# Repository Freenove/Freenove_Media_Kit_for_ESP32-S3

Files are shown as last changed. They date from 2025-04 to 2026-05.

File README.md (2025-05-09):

## Freenove_Media_Kit_for_ESP32-S3

A kit with a Freenove® ESP32-S3 Board for learning programming and electronics.

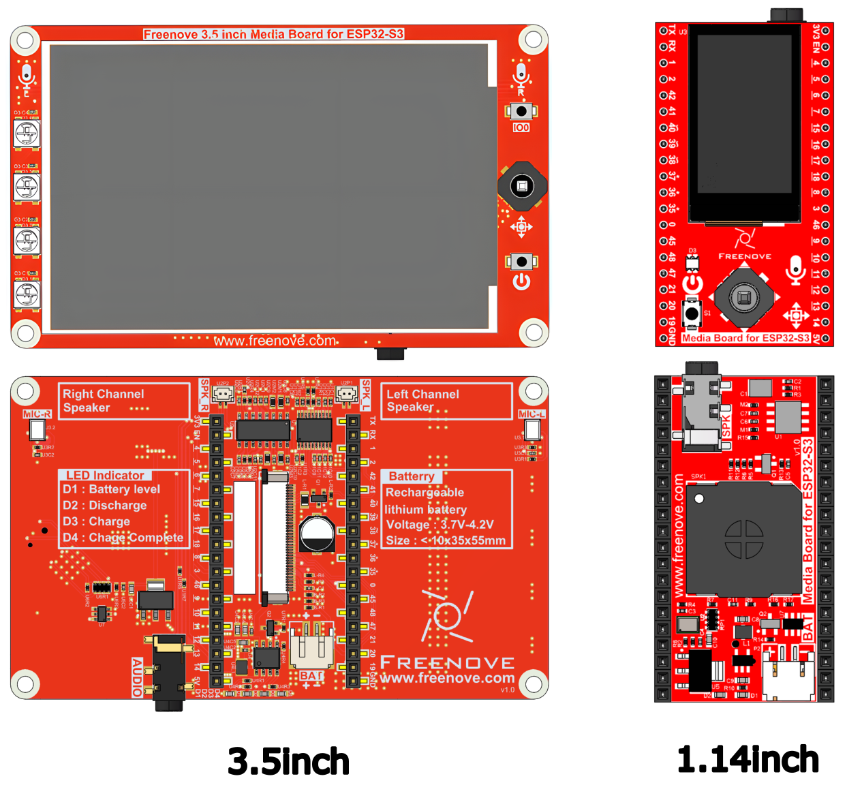
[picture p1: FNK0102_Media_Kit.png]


ESP32-S3 chip is manufactured by Espressif®.
>Espressif® is a trademark of Espressif Systems (Shanghai) Co.Ltd (https://www.espressif.com/).

Freenove ESP32-S3 Board can be uploaded code using Arduino® IDE.
> Arduino® is a trademark of Arduino LLC (https://www.arduino.cc/).

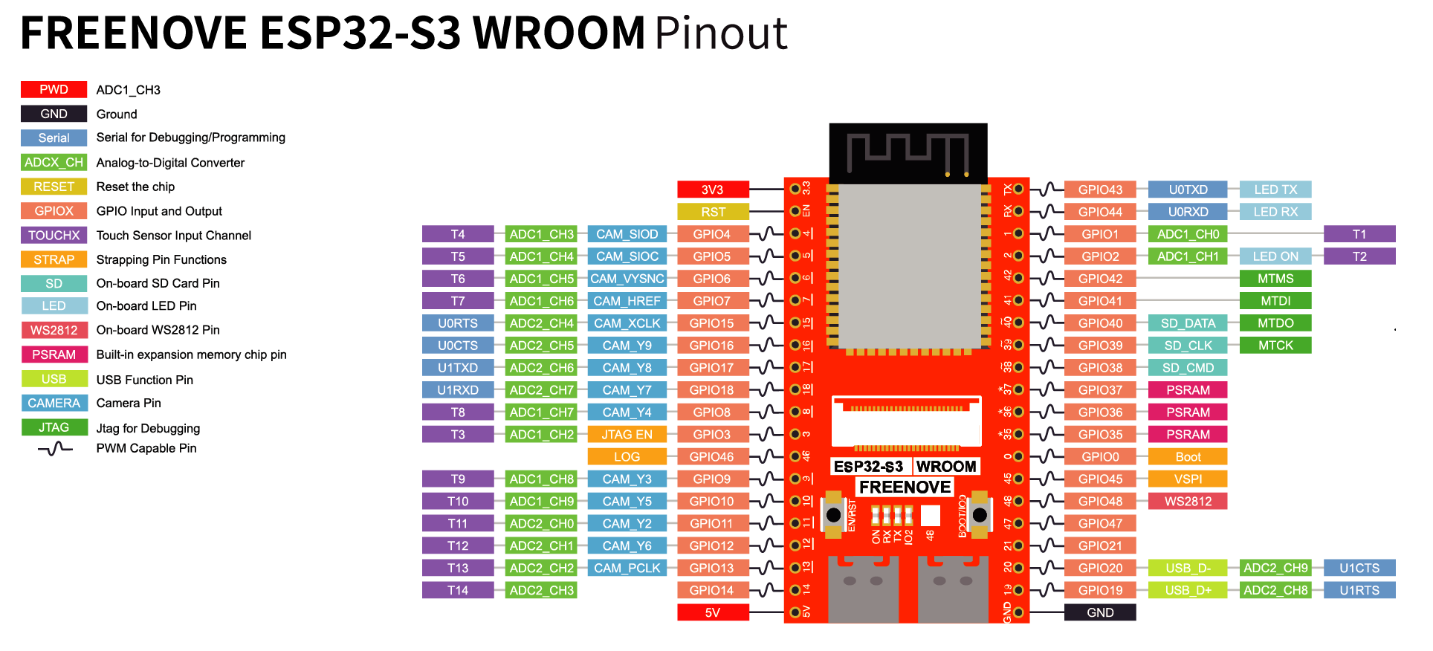
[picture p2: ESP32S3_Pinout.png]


### Download

* **Use command in console**

	Run following command to download all the files in this repository.

	`git clone https://github.com/Freenove/Freenove_Media_Kit_for_ESP32-S3.git`

* **Manually download in browser**

	Click the green "Clone or download" button, then click "Download ZIP" button in the pop-up window.
	Do NOT click the "Open in Desktop" button, it will lead you to install Github software.

> If you meet any difficulties, please contact our support team for help.

### Use

1. Download the ZIP file as above.
2. Unzip it and you will get a folder contains tutorials and related files.
3. If you are interested in the source code of OpenAI or Xiaozhi AI, you can visit the Urls:

	Open AI: [https://github.com/Freenove/openai-realtime-embedded](https://github.com/Freenove/openai-realtime-embedded)
	
	Xiaozhi Ai: [https://github.com/Freenove/xiaozhi-esp32](https://github.com/Freenove/xiaozhi-esp32)
	
	Xiaozhi Ai Server: [https://github.com/Freenove/xiaozhi-esp32-server](https://github.com/Freenove/xiaozhi-esp32-server)

### Support

Freenove provides free and quick customer support. Including but not limited to:

* Quality problems of products
* Problems of products when used
* Questions of learning and creation
* Opinions and suggestions
* Ideas and thoughts

Please send an email to:

[support@freenove.com](mailto:support@freenove.com)

We will reply within one working day.

### Purchase

Please visit the following page to purchase our products:

http://freenove.com/store

Business customers please contact us through the following email address:

[sale@freenove.com](mailto:sale@freenove.com)

### About

Freenove provides open source electronic products and services.

Freenove is committed to helping customers learn programming and electronic knowledge, quickly implement product prototypes, realize their creativity and launch innovative products. Our services include:

* Kits for learning programming and electronics
* Kits compatible with Arduino®, Raspberry Pi®, micro:bit®, etc.
* Kits for robots, smart cars, drones, etc.
* Components, modules and tools
* Design and customization

To learn more about us or get our latest information, please visit our website:

http://www.freenove.com

### Copyright

All the files in this repository are released under [Creative Commons Attribution-NonCommercial-ShareAlike 3.0 Unported License](http://creativecommons.org/licenses/by-nc-sa/3.0/).
You can find a copy of the license in this repository.



> It means you can use these files on your own derived works, in part or completely. But not for commercial use.

Freenove® brand and logo are trademarks of Freenove Creative Technology Co., Ltd. Must not be used without permission.

Other registered trademarks and their owners appearing in this repository:

Arduino® is a trademark of Arduino LLC (https://www.arduino.cc/).  
Raspberry Pi® is a trademark of Raspberry Pi Foundation (https://www.raspberrypi.org/).  
micro:bit® is a trademark of Micro:bit Educational Foundation (https://www.microbit.org/).  
Espressif® is a trademark of Espressif Systems (Shanghai) Co.Ltd (https://www.espressif.com/).

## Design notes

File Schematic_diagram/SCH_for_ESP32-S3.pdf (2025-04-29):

CSI_Y1 CSI_Y³ | CSI_Y²
IO0 | 27 IO35 | 28 IO36 | 29 IO37 | 30 IO38 | 31 IO39 | 32 IO40 | 33 IO41 | 34 IO42 | 35 RXD0/IO44 | 36 TXD0/IO43 | 37 IO2 | 38 IO1 | 39 GND | 40 PGND | 41

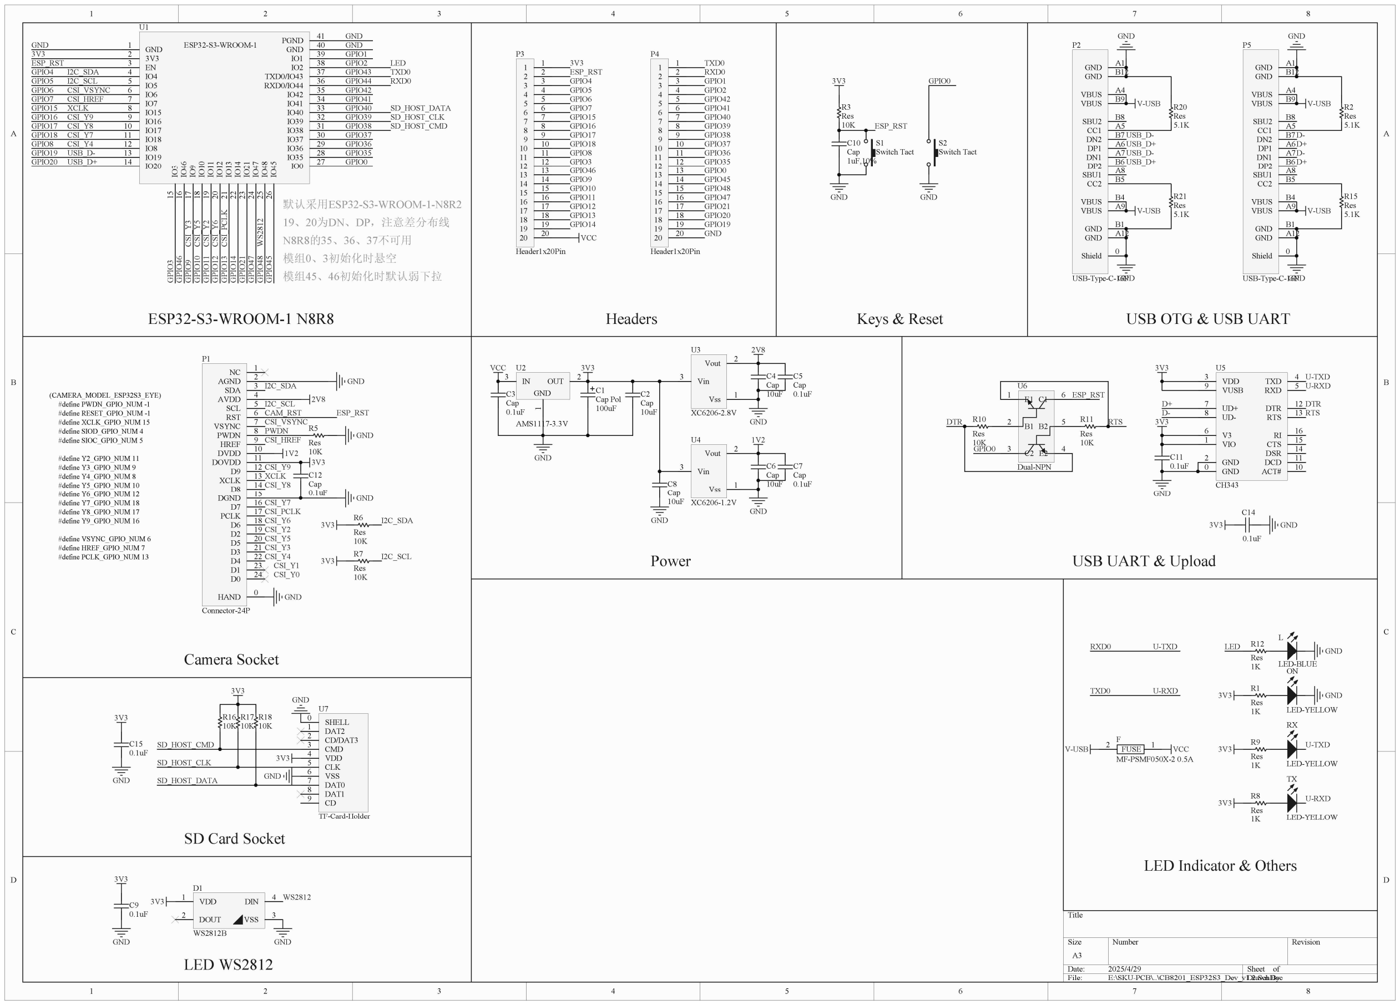
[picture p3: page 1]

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
Title

Size | Number | Revision
A3
Date: | 2025/4/29 | Sheet of
File: | E:\SKU-PCB\..\CB8201_ESP32S3_Dev_v1.2.SchDoc Drawn By:
NC | 1
AGND | 2
SDA | 3
AVDD | 4
SCL | 5
RST | 6
VSYNC | 7
PWDN | 8
HREF | 9
DVDD | 10
DOVDD | 11
D9 | 12
XCLK | 13
D8 | 14
DGND | 15
D7 | 16
PCLK | 17
D6 | 18
D2 | 19
D5 | 20
D3 | 21
D4 | 22
D1 | 23
D0 | 24
HAND | 0

P1

Connector-24P

1K

R1
Res

ON

LED-YELLOW

3V3 | GND

GND

2V8
CAM_RST
CSI_VSYNC
PWDN
CSI_HREF

CSI_Y9
XCLK
CSI_Y8

CSI_Y7

CSI_Y6
CSI_Y2

CSI_Y3
CSI_Y4

CSI_Y5

CSI_PCLK

1V2
3V3

GND

GND

IN 3 | OUT | 2 1
GND

U2

AMS1117-3.3V

VCC

Vss | 1
Vout | 2

Vin 3

U3

XC6206-2.8V

Vss | 1
Vout | 2

Vin 3

U4

XC6206-1.2V

1V2

2V8

GND

GND

100uF

C1
Cap Pol

3V3

10uF

C2
Cap

GND

0.1uF

C3
Cap

10uF

C4
Cap
0.1uF

C5
Cap

10uF

C6
Cap
0.1uF

C7
Cap

10uF

C8
Cap

GND

10K

R3
Res

1uF,10%

C10
Cap

3V3

GND

ESP_RST

ESP_RST

CSI_Y4 | CSI_Y⁵ | CSI_Y⁶

CSI_Y7

CSI_Y0

CSI_VSYNC

CSI_Y9
CSI_Y8

XCLK

CSI_HREF | CSI_PCLK

GND
10K

R5
Res

0.1uF

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
3V3 | I2C_SDA

I2C_SCL

TX

LED-YELLOW

RX

LED-YELLOW

DTR

1K

R8
Res

1K

R9
Res

C1 6

B1 2

E1 1

C2 3

B2 | 5
E2 | 4

U6

Dual-NPN

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
ESP_RST

GPIO0

GND

V-USB

0.1uF

C14

0.1uF

C15

GND

S1
Switch Tact

S2
Switch Tact

GPIO0

GND

1K

R12
Res

L

LED-BLUE

GND LED

3V3

3V3

TXD0

RXD0

U-TXD
U-RXD
FUSE 2 | 1

F

MF-PSMF050X-2 0.5A

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
10 10
11 11
12 12
13 13
14 14
15 15
16 16
17 17
18 18
19 19
20 20

P3

Header1x20Pin

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
10 10
11 11
12 12
13 13
14 14
15 15
16 16
17 17
18 18
19 19
20 20

P4

Header1x20Pin

VCC

D+

D+

D-

D-

D-

D+

V-USB

GND

5.1K

R2
Res

5.1K

R15
Res

GND

V-USB

GND 1
3V3 2
EN 3
IO4 4
IO5 5
IO6 6
IO7 7
IO15 8
IO16 9
IO17 10
IO18 11
IO8 12
IO19 13
IO20 14 | IO³ 15 IO⁴⁶ 16 IO⁹ 17 IO¹⁰ 18 IO¹¹ 19 IO¹² 20 IO¹³ 21 IO¹⁴ 22 IO²¹ 23 IO⁴⁷ 24 IO⁴⁸ 25 IO⁴⁵ 26

U1

GND | ESP32-S3-WROOM-1
3V3

GPIO0

GPIO1
GPIO2 GPIO¹³ GPIO¹⁴

GPIO19
GPIO20 | GPIO²¹

GPIO35

GPIO36

GPIO37

GPIO38

GPIO39

GPIO40

GPIO41

GPIO42

GPIO43
GPIO44 GPIO⁴⁶ | GPIO⁴⁷ GPIO⁴⁸ GPIO⁴⁵

GND
GND

GPIO4
GPIO5
GPIO6
GPIO7
GPIO8 | GPIO³ | GPIO⁹ GPIO¹⁰ GPIO¹¹ GPIO¹²

GPIO15
GPIO16
GPIO17
GPIO18

GPIO4
GPIO5
GPIO6
GPIO7

GPIO8

GPIO15
GPIO16
GPIO17
GPIO18

ESP_RST

3V3

GPIO13
GPIO14

GPIO46
GPIO9
GPIO10
GPIO11
GPIO12

GPIO3

VCC

GPIO0

GPIO1
GPIO2

GPIO35

GPIO36

GPIO37

GPIO38

GPIO39

GPIO40

GPIO41

GPIO42

GND

GPIO19

GPIO20

GPIO21

GPIO45

GPIO47

GPIO48

I2C_SDA

I2C_SCL

I2C_SDA
I2C_SCL

VIO 1

GND 2

VDD 3 | TXD | 4
| RXD | 5

V3 6

UD+ 7
UD- 8

VUSB 9

ACT# | 10 DCD | 11
DTR | | | 12
RTS | | | 13
DSR | 14 CTS | 15 RI | 16

GND 0

U5

CH343

GND | A1
GND | B12
VBUS | A4
VBUS | B9
SBU2 | B8
CC1 | A5
DN2 | B7
VBUS | B4
CC2 | B5
DP2 | B6
GND | B1
DP1 | A6
DN1 | A7
SBU1 | A8
VBUS | A9
GND | A12
Shield | 0

P5

USB-Type-C-16P

10K

R16
10K

R17
10K

R18

SD_HOST_CMD

SD_HOST_CLK
SD_HOST_DATA | GND

SD_HOST_CMD

SD_HOST_CLK

SD_HOST_DATA

TXD0
RXD0

VDD 1

DOUT 2 | VSS | 3
| DIN | 4

D1

WS2812B
GND | GND

0.1uF

C9

# WS2812 WS²⁸¹² 19、20为DN、DP，注意差分布线

## 默认采用ESP32-S3-WROOM-1-N8R2

LED

USB_D-USB_D+

## N8R8的35、36、37不可用

### 模组0、3初始化时悬空

### 模组45、46初始化时默认弱下拉

V-USB

GND

5.1K

R20
Res

5.1K

R21
Res

GND

V-USB

GND | A1
GND | B12
VBUS | A4
VBUS | B9
SBU2 | B8
CC1 | A5
DN2 | B7
VBUS | B4
CC2 | B5
DP2 | B6
GND | B1
DP1 | A6
DN1 | A7
SBU1 | A8
VBUS | A9
GND | A12
Shield | 0

P2

USB-Type-C-16P

USB_D-USB_D+
USB_D-USB_D+

GND

TXD0
RXD0

ESP_RST

3V3

3V3

GND

0.1uF

C11

U-TXD

U-RXD

U-TXD

U-RXD

DAT2 1
CD/DAT3 2
CMD 3
VDD 4
CLK 5
VSS 6
DAT0 7
DAT1 8

SHELL 0

CD 9

U7

TF-Card-Holder

3V3

3V3

3V3

# ESP32-S3-WROOM-1 N8R8

# Camera Socket

# SD Card Socket

# LED WS2812

# Headers

# Power

Keys & Reset | USB OTG & USB UART

# USB UART & Upload

# LED Indicator & Others

3V3

3V3

3V3

(CAMERA_MODEL_ESP32S3_EYE) #define PWDN_GPIO_NUM -1
#define RESET_GPIO_NUM -1

#define XCLK_GPIO_NUM 15

#define SIOD_GPIO_NUM 4

#define SIOC_GPIO_NUM 5

#define Y2_GPIO_NUM 11

#define Y3_GPIO_NUM 9

#define Y4_GPIO_NUM 8

#define Y5_GPIO_NUM 10

#define Y6_GPIO_NUM 12

#define Y7_GPIO_NUM 18

#define Y8_GPIO_NUM 17

#define VSYNC_GPIO_NUM 6

#define Y9_GPIO_NUM 16

#define HREF_GPIO_NUM 7

#define PCLK_GPIO_NUM 13

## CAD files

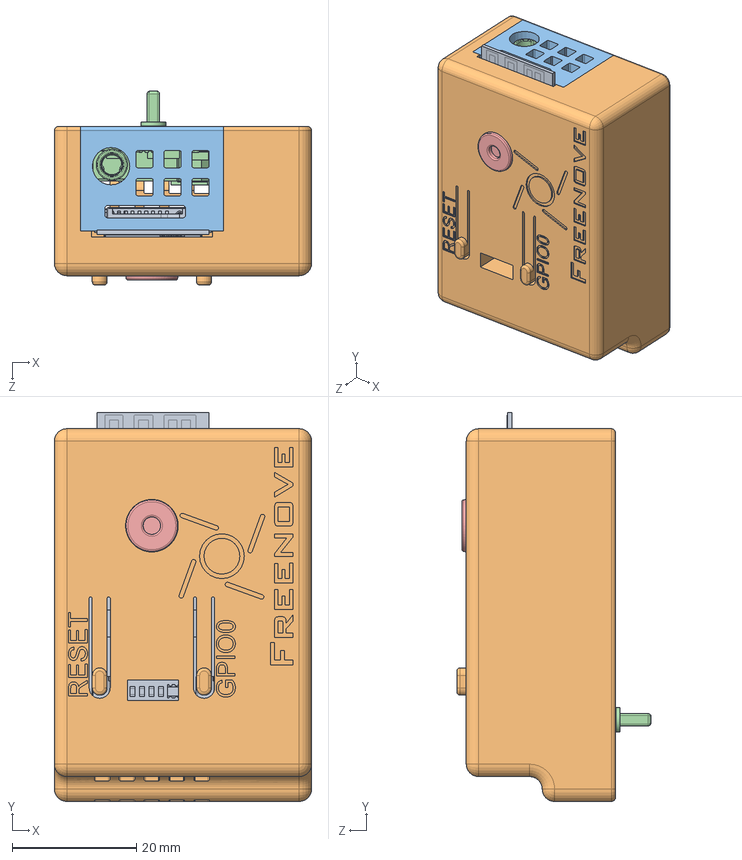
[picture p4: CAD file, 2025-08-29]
3D_Models/FNK0102A/FNK0102A_Assembly_Has_Battery_1.14inch.SLDASM
41.3 x 62.5 x 31.2 mm
CB8201_20250427
FNK0102_Part1_v1.2
FNK0102_Part2_v1.2
CB10201
Camera_OV3660
Battery_752035

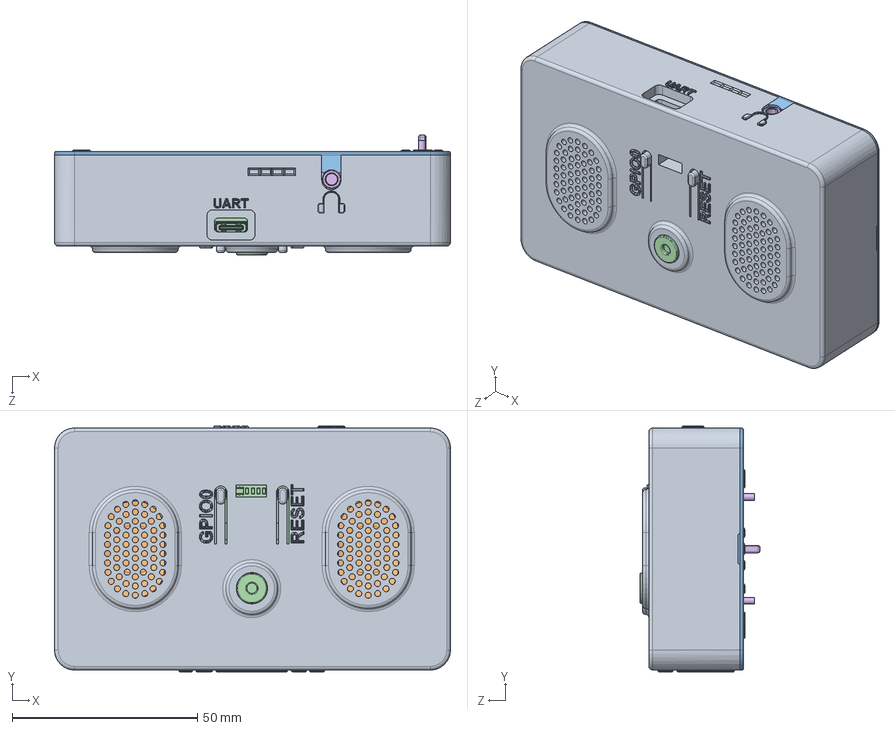
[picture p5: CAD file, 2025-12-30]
3D_Models/FNK0102B/FNK0102B_Assembly_Has_Battery_3.5inch.SLDASM
107.0 x 66.4 x 32.4 mm
FNK0102B_part1_v1.0
speaker_2535 x 2
FNK0102B_part2_v1.0
CB8201_OV3660
Battery_103450
CB10202

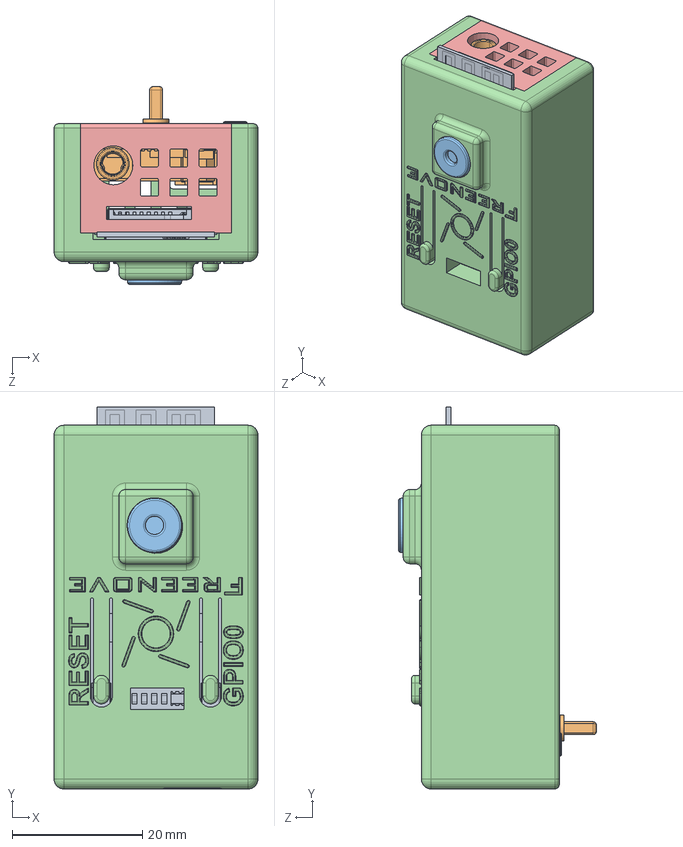
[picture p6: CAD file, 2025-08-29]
3D_Models/FNK0102A/FNK0102A_Assembly_No_Battery_1.14inch.SLDASM
31.3 x 58.7 x 30.4 mm
CB8201_20250427
CB10201
Camera_OV3660
FNK0102_Part1_v1.3
FNK0102_Part2_v1.3

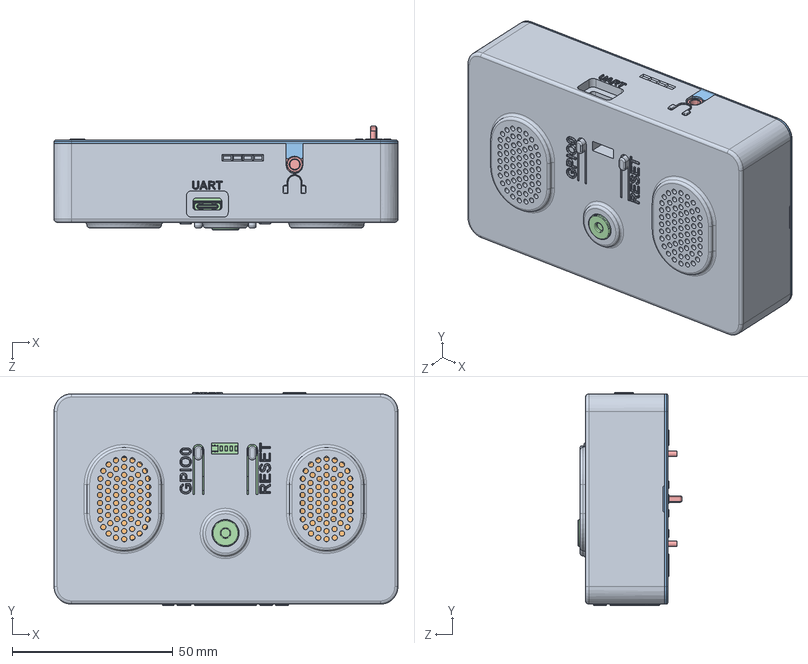
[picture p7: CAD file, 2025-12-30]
3D_Models/FNK0102B/FNK0102B_Assembly_No_Battery_3.5inch.SLDASM
107.0 x 66.4 x 32.4 mm
FNK0102B_part1_v1.0
speaker_2535 x 2
FNK0102B_part2_v1.0
CB8201_OV3660
CB10202

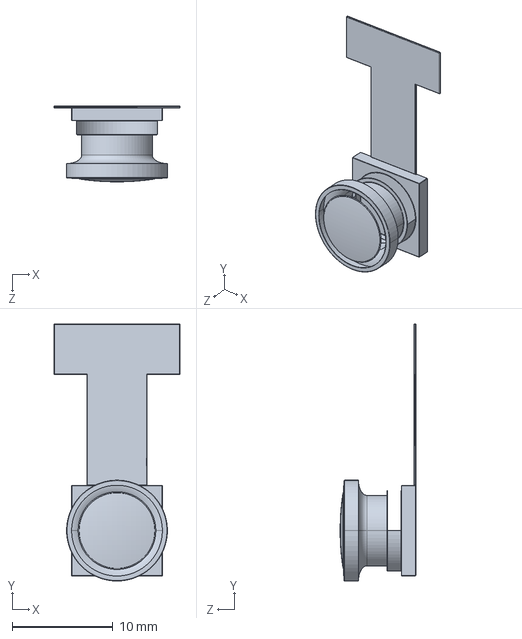
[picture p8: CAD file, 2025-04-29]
3D_Models/FNK0102A/3D_Shell_Camera/Camera.SLDPRT
12.5 x 25.5 x 7.51 mm

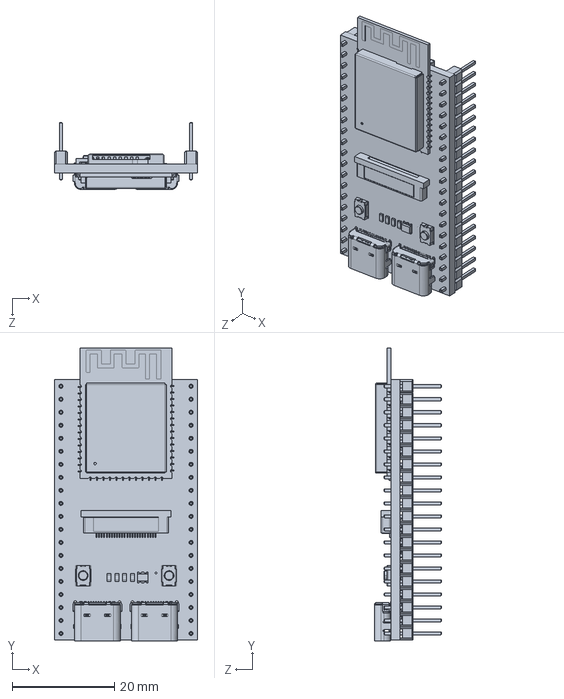
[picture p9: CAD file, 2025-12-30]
3D_Models/FNK0102A/3D_Shell_ESP32-S3/CB8201_20250427.SLDPRT
27.9 x 57.2 x 13.1 mm

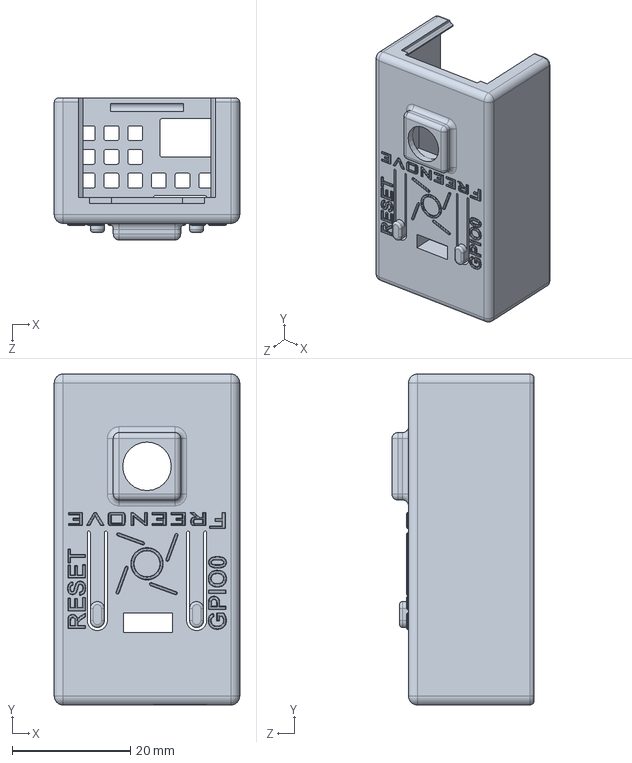
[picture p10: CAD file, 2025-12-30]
3D_Models/FNK0102A/3D_Shell_No_Battery/FNK0102_Part1_v1.3.SLDPRT
31.3 x 55.9 x 24.0 mm

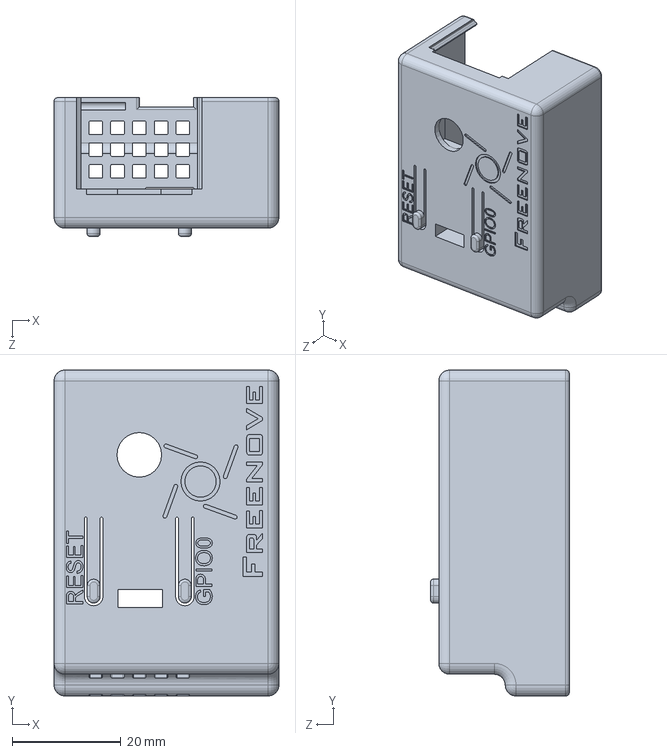
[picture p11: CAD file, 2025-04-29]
3D_Models/FNK0102A/3D_Shell_With_Battery/FNK0102_Part1_v1.2.SLDPRT
41.3 x 59.9 x 25.5 mm

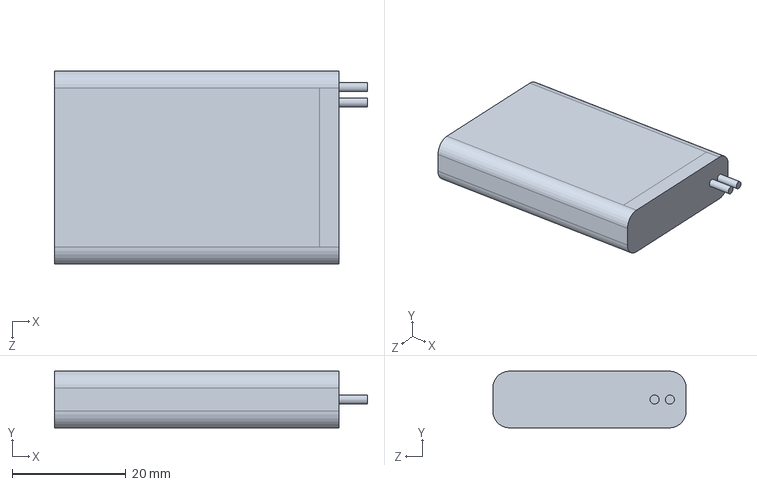
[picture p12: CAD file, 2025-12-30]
3D_Models/FNK0102B/3D_Shell_Battery/Battery_103450.SLDPRT
55.0 x 10.0 x 34.0 mm

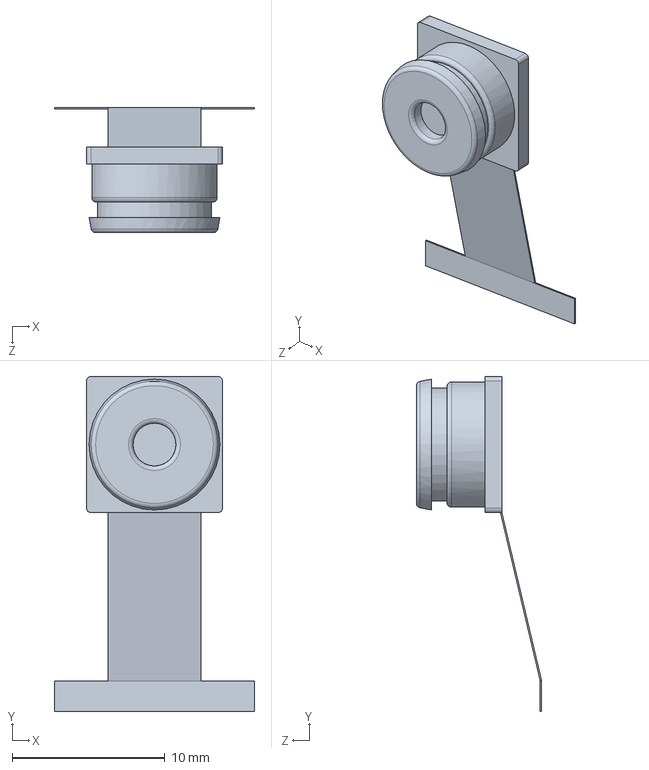
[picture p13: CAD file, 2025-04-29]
3D_Models/FNK0102B/3D_Shell_Camera/Camera_OV3660.SLDPRT
13.1 x 21.9 x 8.20 mm

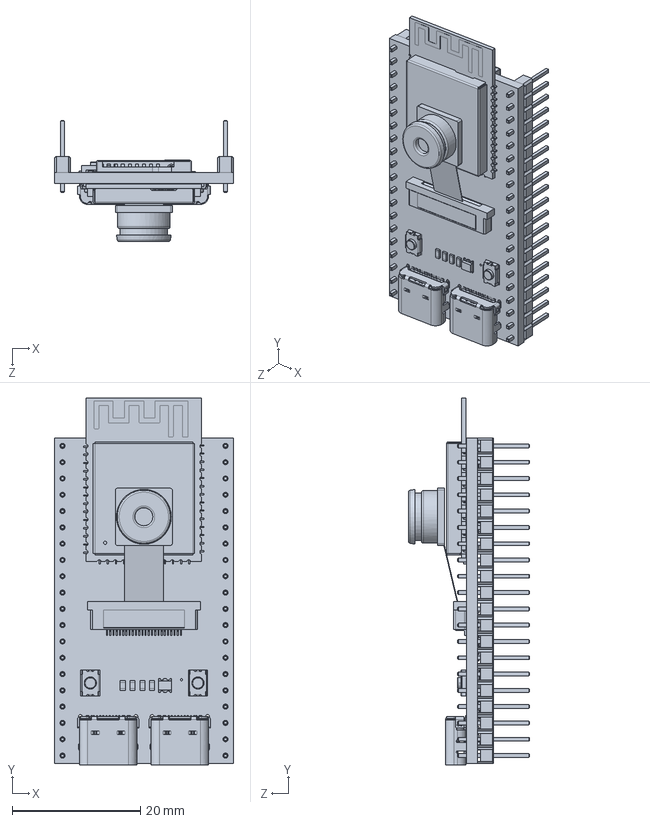
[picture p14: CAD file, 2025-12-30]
3D_Models/FNK0102B/3D_Shell_ESP32-S3/CB8201_OV3660.SLDPRT
27.9 x 57.2 x 18.9 mm

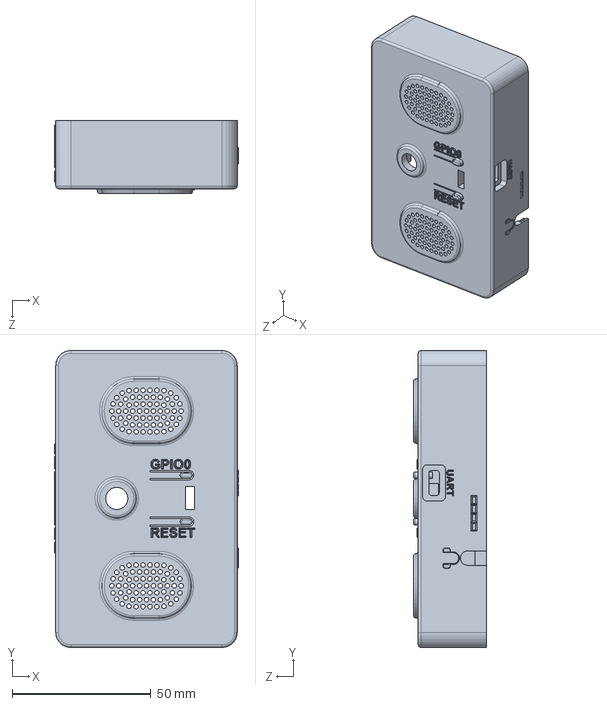
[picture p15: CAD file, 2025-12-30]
3D_Models/FNK0102B/3D_Shell_Part/FNK0102B_part1_v1.0.SLDPRT
66.4 x 107.0 x 26.3 mm

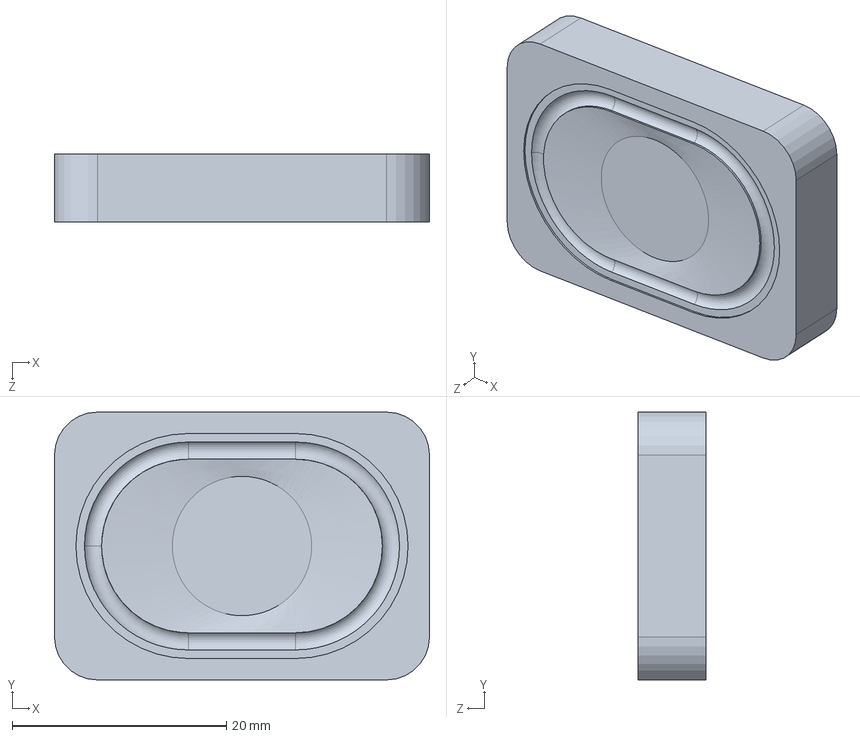
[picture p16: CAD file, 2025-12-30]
3D_Models/FNK0102B/3D_Shell_Speaker/speaker_2535.SLDPRT
35.0 x 25.0 x 6.30 mm

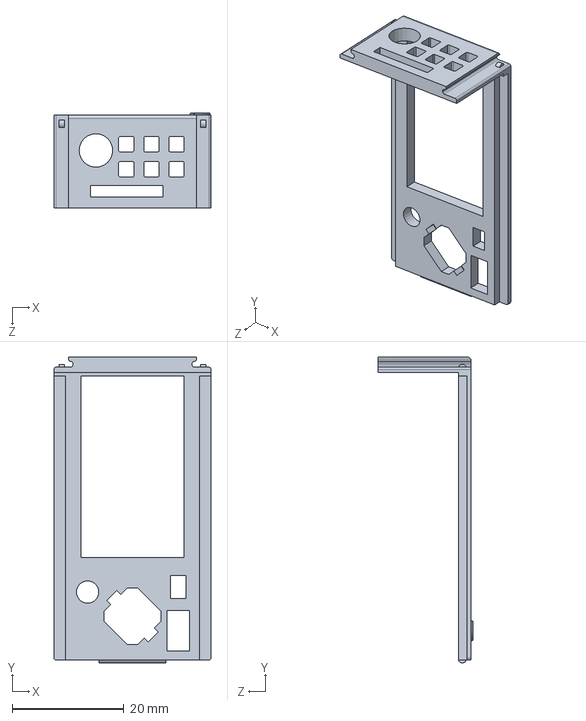
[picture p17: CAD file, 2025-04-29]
3D_Models/FNK0102A/3D_Shell_No_Battery/FNK0102_Part2_v1.3.SLDPRT
28.1 x 54.8 x 17.0 mm

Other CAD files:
3D_Models/FNK0102A/3D_Shell_With_Battery/Battery_752035.SLDPRT
3D_Models/FNK0102B/3D_Shell_Part/FNK0102B_part2_v1.0.SLDPRT
3D_Models/FNK0102A/3D_Shell_Media_Board/CB10201.SLDPRT
3D_Models/FNK0102A/3D_Shell_No_Battery/FNK0102_Part1_v1.3.STL
3D_Models/FNK0102A/3D_Shell_No_Battery/FNK0102_Part2_v1.3.STL
3D_Models/FNK0102A/3D_Shell_With_Battery/FNK0102_Part1_v1.2.STL
3D_Models/FNK0102A/3D_Shell_With_Battery/FNK0102_Part2_v1.2.SLDPRT
3D_Models/FNK0102A/3D_Shell_With_Battery/FNK0102_Part2_v1.2.STL
3D_Models/FNK0102B/3D_Shell_Media_Board/CB10202.SLDPRT

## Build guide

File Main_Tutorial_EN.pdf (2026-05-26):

█ www.freenove.com | List | 1

# Important Information

Thank you for choosing Freenove products!

## Getting Started

If you have not yet downloaded the zip file, associated with this kit, please do so now and unzip it.

## Get Support and Offer Input

Freenove provides free and responsive product and technical support, including but not limited to:
⚫ | Product quality issues
⚫ | Product use and build issues
⚫ | Questions regarding the technology employed in our products for learning and education
⚫ | Your input and opinions are always welcome
⚫ | We also encourage your ideas and suggestions for new products and product improvements
For any of the above, you may send us an email to:

# support@freenove.com

## Safety and Precautions

Please follow the following safety precautions when using or storing this product:
⚫ | Keep this product out of the reach of children under 6 years old.
⚫ | This product should be used only when there is adult supervision present as young children lack
| necessary judgment regarding safety and the consequences of product misuse.
⚫ | This product contains small parts and parts, which are sharp. This product contains electrically conductive
| parts. Use caution with electrically conductive parts near or around power supplies, batteries and
| powered (live) circuits.
⚫ | When the product is turned ON, activated or tested, some parts will move or rotate. To avoid injuries
| to hands and fingers keep them away from any moving parts!
⚫ | It is possible that an improperly connected or shorted circuit may cause overheating. Should this happen,
| immediately disconnect the power supply or remove the batteries and do not touch anything until
| it cools down! When everything is safe and cool, review the product tutorial to identify the cause.
⚫ | Only operate the product in accordance with the instructions and guidelines of this tutorial, otherwise
| parts may be damaged or you could be injured.
⚫ | Store the product in a cool dry place and avoid exposing the product to direct sunlight.
⚫ | After use, always turn the power OFF and remove or unplug the batteries before storing.

2 | List | www.freenove.com █

## About Freenove

Freenove provides open source electronic products and services worldwide.

Freenove is committed to assist customers in their education of robotics, programming and electronic circuits so that they may transform their creative ideas into prototypes and new and innovative products. To this end, our services include but are not limited to:

⚫ | Educational and Entertaining Project Kits for Robots, Smart Cars and Drones
⚫ | Educational Kits to Learn Robotic Software Systems for Arduino, Raspberry Pi and micro: bit
⚫ | Electronic Component Assortments, Electronic Modules and Specialized Tools
⚫ | Product Development and Customization Services

You can find more about Freenove and get our latest news and updates through our website:

## http://www.freenove.com

## sale@freenove.com

## Copyright

All the files, materials and instructional guides provided are released under Creative Commons Attribution-NonCommercial-ShareAlike 3.0 Unported License. (http://creativecommons.org/licenses/by-nc-sa/3.0/) A copy of this license can be found in the folder containing the Tutorial and software files associated with this product.

This means you can use these resource in your own derived works, in part or completely but NOT for the intent or purpose of commercial use.

Freenove brand and logo are copyright of Freenove Creative Technology Co., Ltd. and cannot be used without written permission.

█ www.freenove.com | List | 3

# Contents

4 | List | www.freenove.com █
Project 10.3 Record and Play | 164
Chapter 11 ESP32_SR | 173
Project 11.1 ESP32_SR | 173
Chapter 12 LVGL | 186
Project 12.1 LVGL | 186
Chapter 13 LVGL LEDPixel | 195
Project 13.1 LVGL LEDPixel | 195
Chapter 14 LVGL Camera | 199
Project 14.1 LVGL Camera | 199
Chapter 15 LVGL Picture | 205
Project 15.1 LVGL Picture | 205
Chapter 16 LVGL Music | 210
Project 16.1 LVGL Music | 210
Chapter 17 LVGL Sound Recorder | 215
Project 17.1 LVGL Sound Recorder | 215
Chapter 18 LVGL Multifunctionality | 219
Project 18.1 LVGL Multifunctionality | 219
Chapter 19 LVGL Multifunctionality | 224
Project 19.1 LVGL Multifunctionality | 224
AI Voice Assistant Based on XiaoZhi AI | 229
About the Project | 229
Cautions | 229
Disclaimer | 230
AI Voice Assistant Based on OpenAI Realtime Model | 232
About the Project | 232
Cautions | 232
About OpenAI | 232
Openai-realtime-embedded Disclaimer | 233
What's Next? | 235

█ www.freenove.com | List | 5

# List

As of the time of writing, the Freenove Media Kit for ESP32-S3 comes in two different models with varying screen sizes. However, this tutorial applies to both versions.

## 1.14inch

Top of ESP32-S3 N16R8 x1 | Bottom of ESP32-S3 N16R8 x1
Top of the Extension Board x1 | Bottom of the Extension Board x1

6 | List | www.freenove.com █
Housing Base (3D Printed) x1 | Housing Cover (3D Printed) x1

SD card reader x1 (random color)

(Not a USB flash drive.)

SDcard x1

## 3.5inch

Top of ESP32-S3 N16R8 x1 | Bottom of ESP32-S3 N16R8 x1

█ www.freenove.com | List | 7
Top of the Extension Board x1 | Bottom of the Extension Board x1
Housing Base (3D Printed) x1 | Housing Cover (3D Printed) x1

8 | List | www.freenove.com █

SD card reader x1 (random color)

(Not a USB flash drive.)

SDcard x1

## Note

Important Notes:
1. Surface Finish: The housing is 3D-printed using FDM technology with a layer resolution of 0.1–0.2 mm. As a result, minor surface roughness and visible layer lines are normal.
2. Color Change: The white PLA material may gradually develop a beige/yellowish tint over time due to environmental exposure. This is an inherent characteristic of the material.
3. Handling Care: PLA is less impact-resistant than conventional plastics. Please handle the housing gently and avoid excessive force during assembly.
Replacement Options:
1. 3D model files are available in Freenove_Media_Kit_for_ESP32-S3\3D_Models for self-printing if needed.
2. If you don’t have a 3D printer, you can order a replacement by uploading the STL file at JLCPCB (https://jlc3dp.com/?href=easyeda-home).

█ www.freenove.com | Preface | 9

# Preface

## ESP32-S3 WROOM

The ESP32-S3-WROOM-1 offers two antenna options: the PCB on-board antenna and the IPEX antenna.
- The PCB on-board antenna is an integrated antenna within the chip module itself, making it compact and convenient for both portability and design.
- The IPEX antenna is an external metal antenna connected to the module’s integrated antenna, providing enhanced signal performance.
PCB on-board antenna | IPEX antenna

The ESP32-S3 WROOM of this product is based on the ESP32-S3-WROOM-1 module with built-in PCB onboard antenna.
ESP32-S3 WROOM

10 | Preface | www.freenove.com █

The hardware interfaces of ESP32-S3 WROOM are distributed as follows:

Compare the left and right images. We've boxed off the resources on the ESP32-S3 WROOM in different colors to facilitate your understanding of the board.
Box color | Corresponding resources introduction
| GPIO pins
| LED indicators
| Camera interface
| Reset button, Boot mode selection button
| USB ports

For more information, please visit: https://www.espressif.com.cn/sites/default/files/documentation/esp32-s3-wroom-1_wroom-1u_datasheet_en.pdf. (https://www.espressif.com.cn/sites/default/files/documentation/esp32-s3-wroom-1_wroom-1u_datasheet_en.pdf)

GPIO pins of ESP32-S3 WROOM can be used to interface with external devices and control peripheral circuits.

█ www.freenove.com | Preface | 11

## Freenove Media Kit for ESP32-S3

As of the time of writing, the Freenove Media Kit for ESP32-S3 comes in two different models with varying screen sizes. However, this tutorial applies to both versions.

## 1.14inch

The audio circuit board integrates multiple functional hardware modules, including a 1.14-inch TFT display, a microphone, a battery charging circuit, an audio processing circuit, a headphone jack, and an integrated speaker, as illustrated in the figures below.

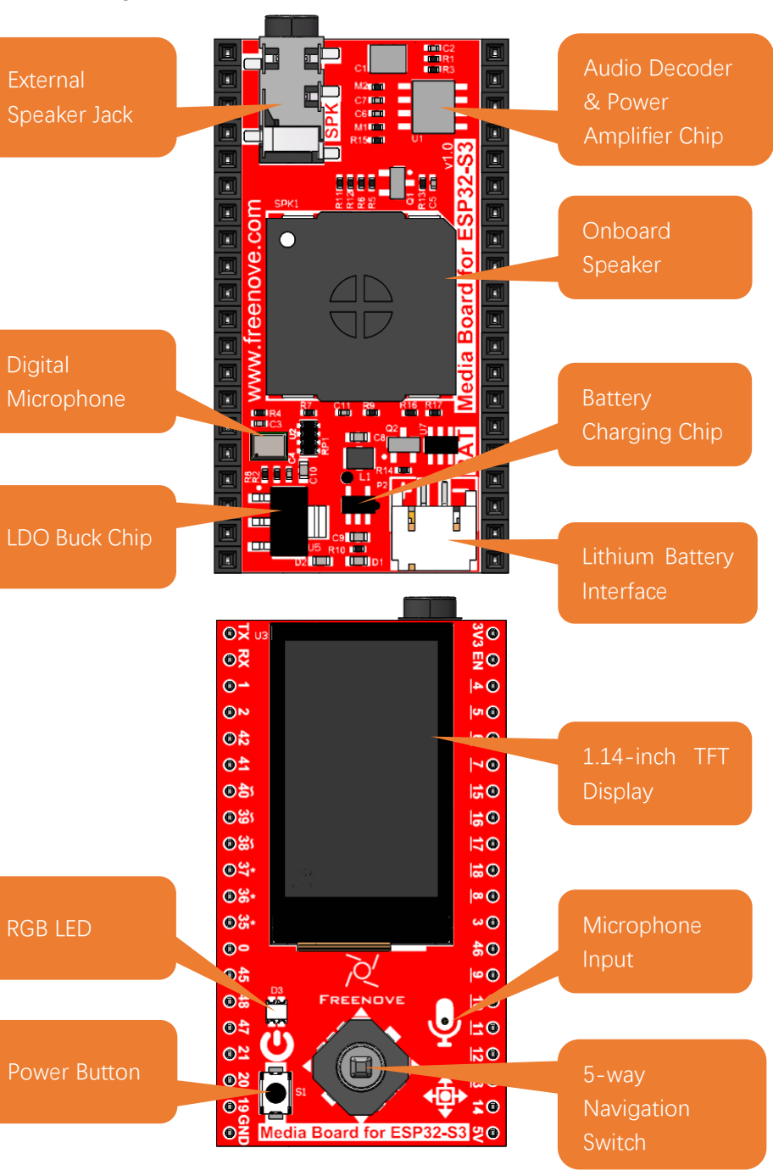
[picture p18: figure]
External Speaker Jack; Audio Decoder & Power Amplifier Chip; Onboard Speaker; Digital; Microphone; Battery; Charging Chip; Lithium Battery Interface; LDO Buck Chip; 1.14-inch TFT Display; Microphone Input; 5-way Navigation Switch; RGB LED; Power Button

## 3.5inch

12 | Preface | www.freenove.com █

The audio circuit board integrates multiple functional hardware modules, including a 3.5-inch TFT display, a microphone, a battery charging circuit, an audio processing circuit, a headphone jack, and an speaker jack, as illustrated in the figures below.

WS2812

3.5-inch
TFT display

Power
Button

Left
Microphone

Right
Microphone

5-way
Navigation
Key

Headphone
Jack

Battery
Connector

Buck Circuit

Audio Chip

Charging
Chip

DAC Chip

Speaker
Connector

Button

## Power Button

█ www.freenove.com | Preface | 13

The power button on the Freenove Media Kit for ESP32-S3, as shown in the diagram below, only works when powered by a battery (used to control battery connection/disconnection). It has no effect when powered via USB.

Schematic
The schematic of the power button is as shown below:

14 | Preface | www.freenove.com █

## Battery (Optional)

| 1.14inch
This product does not include a lithium battery. Please purchase one separately.

The device supports both USB direct power supply and lithium battery power supply.
We strongly recommend using USB power whenever possible, as lithium batteries can be hazardous and
| require careful handling. Avoid using a battery unless absolutely necessary.

The recommended size of lithium batteries for this product is: 7.5mmx20mmx35mm. Search for “702035
| battery” on any shopping platform.

This product uses a PH2.0mm 2P connector for power supply. You may purchase lithium batteries of any capacity, but please note that the rated input voltage range must be 3.7V–4.2V.

Commercially available batteries may have two different wiring polarities (positive/negative reversed). You must verify that the purchased battery’s pinout matches the product’s requirements (as shown in the diagram below). Incorrect polarity may cause device damage or safety hazards.

The red wire is Positive (+) and black wire Negative (-)

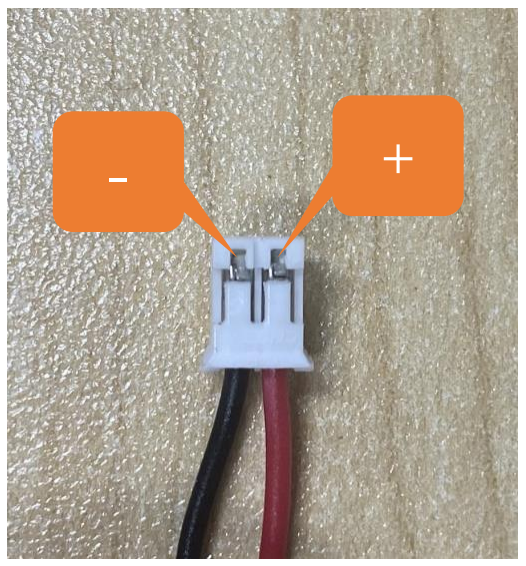
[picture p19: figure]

█ www.freenove.com | Preface | 15

3.5inch
This product does not include a lithium battery. Please purchase one separately.

The device supports both USB direct power supply and lithium battery power supply.
We strongly recommend using USB power whenever possible, as lithium batteries can be hazardous and require careful handling. Avoid using a battery unless absolutely necessary.

The recommended size of lithium batteries for this product is: 10mmx34mmx50mm. Search for “103450 battery” on any shopping platform.

This product uses a PH2.0mm 2P connector for power supply. You may purchase lithium batteries of any capacity, but please note that the rated input voltage range must be 3.7V–4.2V.

Commercially available batteries may have two different wiring polarities (positive/negative reversed). You must verify that the purchased battery’s pinout matches the product’s requirements (as shown in the diagram below). Incorrect polarity may cause device damage or safety hazards.

The red wire is Positive (+) and black wire Negative (-)

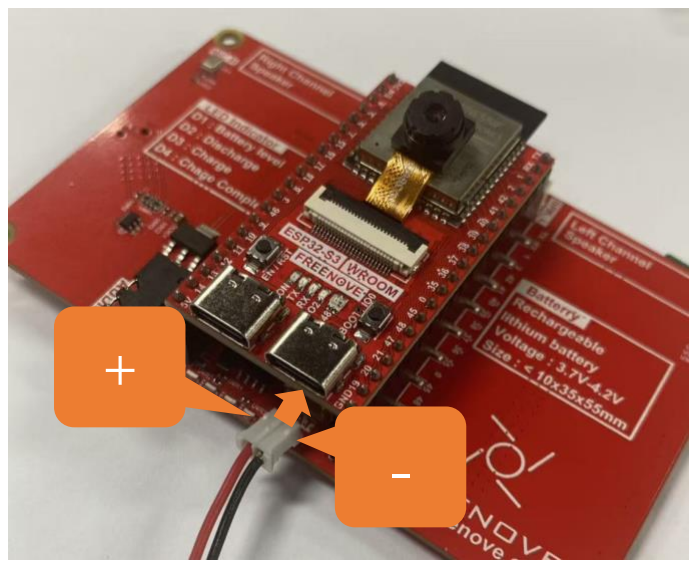
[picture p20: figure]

16 | Preface | www.freenove.com █

Note
We recommend using the dedicated charger designed for your lithium battery.
Since lithium batteries vary in specifications and quality, using the correct charger helps ensure optimal performance, safety, and longevity.
While our product also supports USB charging as a backup option, please note that this method does not support fast charging and provides only a slow, standard charge.

Charging & Power Indicators:

When using the USB port on the board to charge the battery: While charging, the blue LED will blink.
When charging is complete, the blue LED will stay lit.
If no battery is connected, the blue LED will keep blinking.

When the device is not connected to USB, it runs on battery power, and the green LED remains steadily lit.

USB Interface

█ www.freenove.com | Preface | 17

## Speaker and Headphone Connector

The Freenove Media Kit for ESP32-S3 is equipped with a speaker that supports high-quality audio output, capable of meeting the playback requirements for various sound effects and music. You can learn how to generate simple tones in Chapter 5: Simple Tone Test, and how to play music in Chapter 6: Play MP3 Test.

The following table shows the specifications of the speaker. 1.14inch：
Specifications | Description | Typical value
Rated Impedance | The resistance of the speaker to AC current, affecting amplifier matching. | 8Ω
Rated Power | The maximum continuous power the speaker can handle. | 1W
Frequency Range | The effective operating frequency range of the speaker. | 550~20kHz
Maximum Sound Pressure Level (SPL) | The highest sound intensity the speaker can produce under specific conditions. | 96±3dB
Dimensions | The length and width of the speaker. | 18mm * 18mm
3.5inch：
Specifications | Description | Typical value
Rated Impedance | The resistance of the speaker to AC current, affecting amplifier matching. | 4Ω
Rated Power | The maximum continuous power the speaker can handle. | 3W
Frequency Range | The effective operating frequency range of the speaker. | 550~20kHz
Maximum Sound Pressure Level (SPL) | The highest sound intensity the speaker can produce under specific conditions. | 98±3dB
Dimensions | The length and width of the speaker. | 35mm * 25mm

Notes:
1. Resistor R15 is not soldered by default (as shown in the figure below).
- When R15 is not soldered: Inserting a headphone plug disconnects the speaker.
- When R15 is soldered: Inserting a headphone plug allows both the speaker and headphone jack to output audio simultaneously.

18 | Preface | www.freenove.com █
2. Resistor R1 is soldered by default, while R3 is not soldered by default.
- When only R1 is soldered: The right channel is active.
- When only R3 is soldered: The left channel is active.

The onboard speaker can be used to play any audio, but the volume may be relatively low. If you wish to use external speakers, you can connect them via the headphone jack.
This product features a 3.5mm TRS headphone socket. If you intend to connect your own speakers using an audio cable, please ensure you purchase a compatible 3.5mm TRS plug.
Common 3.5mm male plugs include TRS Jack and TRRS Jack, which are easily distinguishable:
TRS Jack has two metal rings (Tip, Ring, Sleeve).
TRRS Jack has three metal rings (Tip, Ring, Ring, Sleeve). (See figure below.)

The TRS Jack (2-ring) headphone plug is compatible with the 3.5mm female socket on the Freenove Media Kit for ESP32-S3.
TRRS Jacks (3-ring) come in two common standards: OMTP and CTIA, differing in the wiring of Microphone (MIC) and Ground (GND) on the Ring2 and Sleeve contacts (see figure below).

█ www.freenove.com | Preface | 19
| Tip | Left channel
| Ring | Right channel
| Sleeve | GND
| | Sleeve | GND
| | Sleeve | Microphone

Important Notes:
1. If you connect headphones to the 3.5mm female socket, set the volume to 5 or lower (max volume = 21) in your code. Excessive volume may damage your headphones.
The Freenove Media Kit for ESP32-S3 is fully compatible with CTIA-standard (modern) headphones, but only partially supports OMTP-standard (older) headphones. Please verify compatibility before use.
2. If you connect a speaker to the 3.5mm socket, refer to the wiring diagram below for proper connection.
- Maximum Supported Speaker Power: The built-in audio output supports up to 2.5W speakers. For higher-power speakers, an external amplifier is required.

20 | Preface | www.freenove.com █

█ www.freenove.com | Preface | 21

## SD Card

Freenove Media Kit for ESP32-S3 comes with a 1GB SD card and a SD card reader (see the figure below). The SD card uses SDMMC communication protocol, providing faster speeds and better performance compared to SPI proocol.
Please note that the included card reader cannot be used as a USB flash driver. It is specifically designed for SD card access only.
SD card x1 | Card reader x1 (random color)

For more information and instuctions for using the SD card, please refer to Chapter 4.

The following table shows the pin definition of the SD card.

Item | Pins | Definition
SD Card | GPIO38 | SD_CMD
| GPIO39 | SD_CLK
| GPIO40 | SD_D0

22 | Preface | www.freenove.com █

## TFT Display

Freenove Media Kit for ESP32-S3 features a TFT display. With each pixel is individually controlled by a tiny transistor, TFT (Thin-Film Transistor) displays, a common type of LCD screen, offer high responsiveness,
| brightness, and contrast. 1.14inch
Specifications | Description
Dimensions | 1.14 inch
Resolution | 135×240 pixel
Drvier | ST7789
Display Area | 14.9mm * 24.9mm
Rated Voltage | 3.3V
Communication | SPI
The 1.14inch screen size specification refers to the diagonal measurement of the display's active viewing area, which equals approximately 2.9 centimeters (1.14 inches).
3.5inch
Specifications | Description
Dimensions | 3.5 inch
Resolution | 320x480 pixel
Drvier | ST7365/ST7796
Display Area | 48.96mm x73.44mm
Rated Voltage | 3.3V
Communication | SPI
The 3.5inch screen size specification refers to the diagonal measurement of the display's active viewing area, which equals approximately 8.9 centimeters (3.5 inches).

█ www.freenove.com | Preface | 23

Schematic of the TFT Display

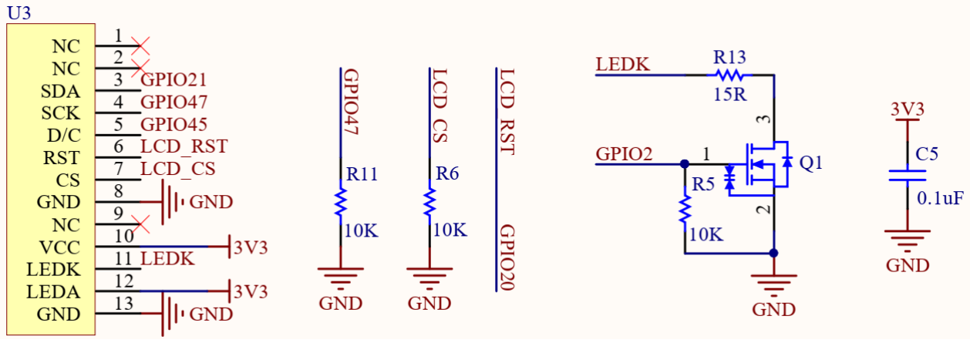
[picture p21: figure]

Note: During display reset operations, GPIO20 must be configured in output mode. The reset sequence requires:
First output a low level and maintain it for a delay period
Then switch to high level to complete the reset timing
The following table shows the pin definition of the TFT display.
Item | Pins | Definition
TFT display | GPIO21 | LCD_SDA
| GPIO47 | LCD_SCK
| GPIO45 | LCD_D/C
| GPIO20 | LCD_RST

24 | Preface | www.freenove.com █

## Microphone

The Freenove Media Kit for ESP32-S3 includes a MEMS microphone (Micro-Electro-Mechanical Systems microphone), which offers several advantages over traditional ECM (Electret Condenser Microphones) including smaller size, higher sensitivity and signal-to-noise ratio (SNR), and superior noise immunity, making
| them ideal for compact embedded applications. For further details on MEMS microphone technology, refer to Chapter 10
Top | Bottom

Shematic
1.14inch

3.5inch

The following table shows the pin definition of the microphone
Item | Pins | Definition
Mic | GPIO14 | MIC_WS
| GPIO3 | MIC_SCK
| GPIO46 | MIC_SD

## 5-way Navigation Switch

█ www.freenove.com | Preface | 25

Freenove Media Kit for ESP32-S3 utilizes a 5-way navigation button for human-machine interaction. For more details about the 5-way button, please refer to Chapter 3.

Item | Pin | Definition
Power Button | GPIO19 | PowerButton_COM

26 | Preface | www.freenove.com █

## Camera

| Freenove Media Kit for ESP32-S3 integrates a camera module.

The following table shows the pin definition of the camera.
Item | Pins | Definition
Camera | GPIO4 | SIOD
| GPIO5 | SIOC
| GPIO6 | CSI_VYSNC
| GPIO7 | CSI_HREF
| GPIO16 | CSI_Y9
| GPIO15 | XCLK
| GPIO17 | CSI_Y8
| GPIO18 | CSI_Y7
| GPIO13 | CSI_PCLK
| GPIO12 | CSI_Y6
| GPIO11 | CSI_Y2
| GPIO10 | CSI_Y5
| GPIO9 | CSI_Y3
| GPIO8 | CSI_Y4

█ www.freenove.com | Preface | 27

## Notes for GPIO

## GPIO Pinout Table

To learn what each GPIO corresponds to, please refer to the following table.
The functions of the pins are allocated as follows:
ESP32-S3 N16R8 | Funtions | Description
GPIO48 | WS2812_DIN | WS2812
GPIO21 | LCD_SDA | TFT_LCD
GPIO47 | LCD_SCK
GPIO45 | LCD_D/C
GPIO20 | LCD_RST
GPIO14 | MIC_WS | Mic
GPIO3 | MIC_SCK
GPIO46 | MIC_SD
GPIO19 | PowerButton_COM | Power Button
GPIO41 | NS4168_LRCLK | Digital Power Amplifier
GPIO42 | NS4168_BCLK
GPIO1 | NS4168_SDATA
GPIO4 | SIOD | Camera
GPIO5 | SIOC
GPIO6 | CSI_VYSNC
GPIO7 | CSI_HREF
GPIO16 | CSI_Y9
GPIO15 | XCLK
GPIO17 | CSI_Y8
GPIO18 | CSI_Y7
GPIO13 | CSI_PCLK
GPIO12 | CSI_Y6
GPIO11 | CSI_Y2
GPIO10 | CSI_Y5
GPIO9 | CSI_Y3
GPIO8 | CSI_Y4
GPIO38 | SD_CMD | SD Card
GPIO39 | SD_CLK
GPIO40 | SD_D0
For more information, refer to the schematic.
If you have any concerns, please feel free to contact us via support@freenove.com

28 | Preface | www.freenove.com █

## PSRAM Pin

The module on the ESP32-S3-WROOM board utilizes the ESP32-S3R16 chip, which comes with 8MB of external Flash. When using the OPI PSRAM, it should be noted that GPIO35-GPIO37 on the ESP32-S3-WROOM board will not be available for other purposes. However, when OPI PSRAM is not used, GPIO35-
| GPIO37 on the board can be used as normal GPIO.

## SDcard Pin

An SDcard slot is integrated on the back of the ESP32-S3-WROOM board, and we can use GPIO38-GPIO40 of ESP32-S3-WROOM to drive SD card.
The SDcard of ESP32-S3-WROOM uses SDMMC, a 1-bit bus driving method, which is integrated in the Arduino IDE, and we can call the “SD_MMC.h” library to drive it. For more details, please refer to the SDcard chapter in this tutorial.

## USB Pin

Please note that in this product, GPIO20 is used for both battery voltage sampling (ADC) and LCD reset signal (RST). Therefore, it must not be configured for USB functions to avoid signal interference.

█ www.freenove.com | Preface | 29

## Cam Pin

When using the camera on our ESP32-S3-WROOM, please check its pin assignments. Pins marked with underlined numbers are dedicated to the camera function. If you intend to use additional functions alongside the camera, avoid using these pins to prevent conflicts.

If you have any questions regarding GPIO information, you can click here to navigate back to the ESP32-S3 WROOM and view specific GPIO details.
Or check: https://www.espressif.com/sites/default/files/documentation/esp32-s3_datasheet_en.pdf.

30 | Preface | www.freenove.com █

## CH343 (Required)

ESP32-S3 WROOM uses CH343 to download code. Therefore, before using the device, it is necessary to install the CH343 driver on your computer.

## Windows

Check whether CH343 has been installed
1. Connect your computer and ESP32-S3 WROOM with a USB cable.
2. Turn to the main interface of your computer, select “This PC” and right-click to select “Manage”.

█ www.freenove.com | Preface | 31
3. Click “Device Manager”. If your computer has installed CH343, you can see”USB-Enhances-SERIAL CH343 (COMx)”. And you can click here to move to the next step.

CH343 Port

32 | Preface | www.freenove.com █

Installing CH343
1. First, download CH343 driver, click http://www.wch-ic.com/search?t=all&q=ch343 to download the appropriate one based on your operating system.

If you would not like to download the installation package, you can open “Freenove_Media_Kit_for_ESP32-S3/CH343”, we have prepared the installation package.

2. Open the folder “Freenove_Media_Kit_for_ESP32-S3/CH343/Windows/”

Windows

MAC

█ www.freenove.com | Preface | 33
3. Double click “CH343SER.EXE”.
4. Click “INSTALL” and wait for the installation to complete.

34 | Preface | www.freenove.com █
5. Install successfully. Close all interfaces.
6. When ESP32-S3 WROOM is connected to computer, select “This PC”, right-click to select “Manage” and click “Device Manager” in the newly pop-up dialog box, and you can see the following interface.
7. So far, CH343 has been installed successfully. Close all dialog boxes.

## MAC

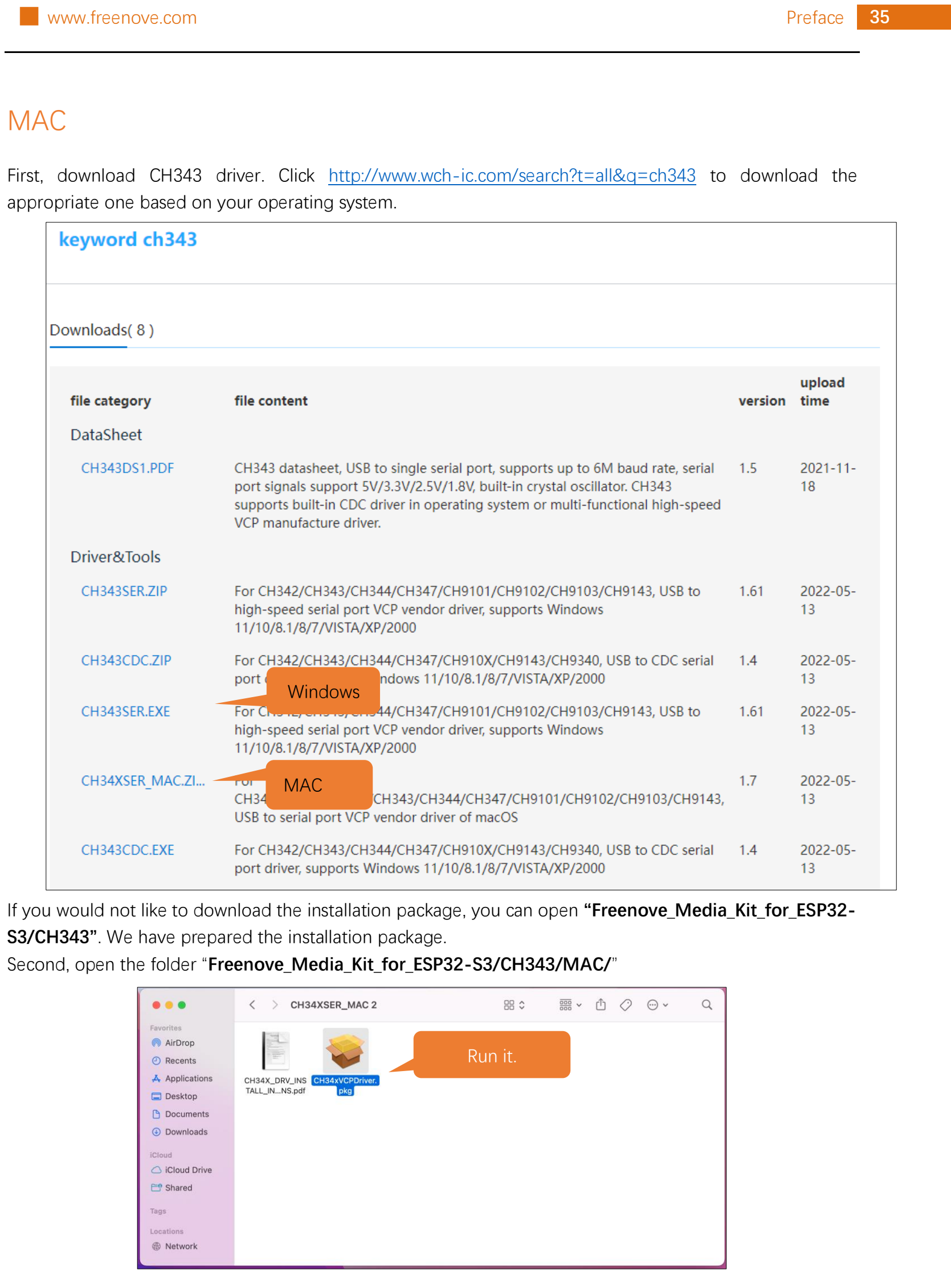
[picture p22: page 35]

█ www.freenove.com | Preface | 35

First, download CH343 driver. Click http://www.wch-ic.com/search?t=all&q=ch343 to download the appropriate one based on your operating system.

If you would not like to download the installation package, you can open “Freenove_Media_Kit_for_ESP32-S3/CH343”. We have prepared the installation package.
Second, open the folder “Freenove_Media_Kit_for_ESP32-S3/CH343/MAC/”

Windows

MAC

Run it.

36 | Preface | www.freenove.com █

Third, click Continue.

Fourth, click Install.

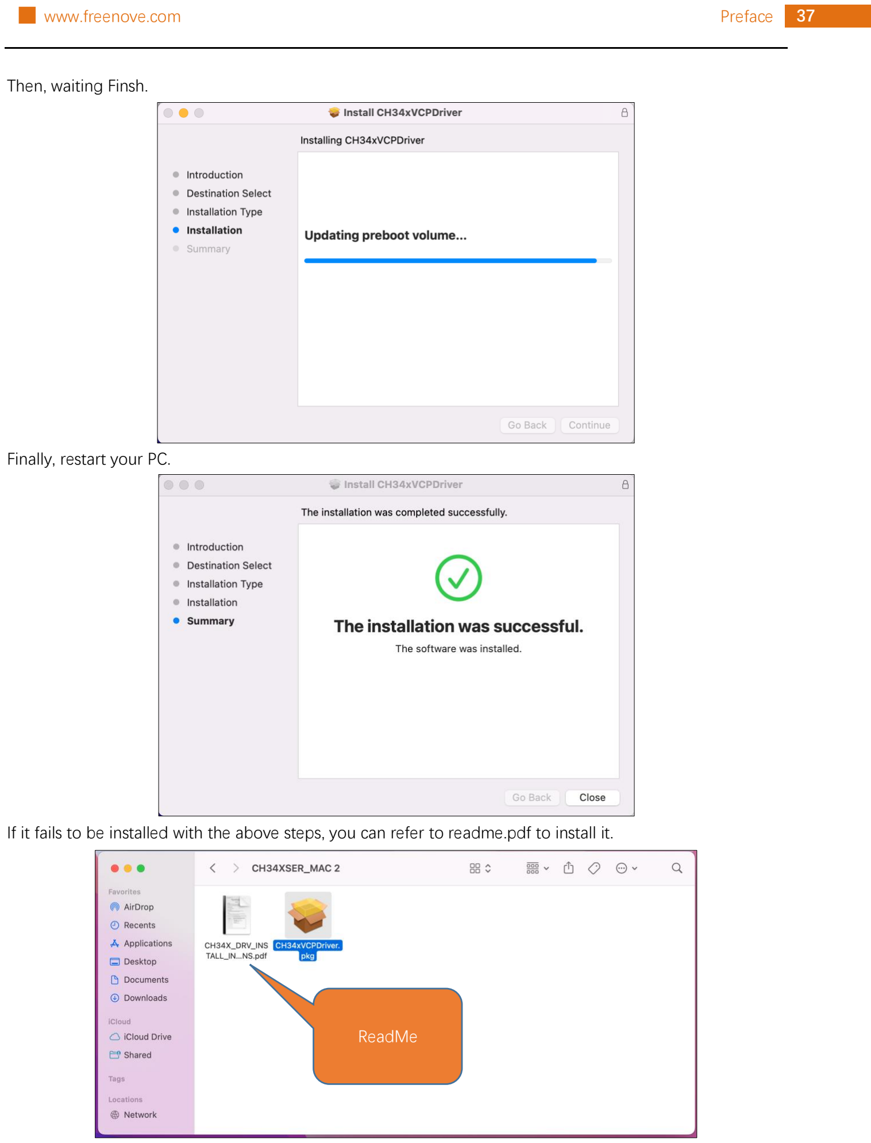
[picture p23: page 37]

█ www.freenove.com | Preface | 37

Then, waiting Finsh.

Finally, restart your PC.

If it fails to be installed with the above steps, you can refer to readme.pdf to install it.

ReadMe

## Linux

38 | Preface | www.freenove.com █

Here we take Ubuntu system as an example. Open the Terminal.

Run “lsusb” to check the port. lsusb
ls /dev/tty*

CH343 is fully compliant to the Communications Device Class (CDC) standard, they will work with a standard CDC-ACM driver (CDC - Abstract Control Model). Linux operating systems supply a default CDC-ACM driver that can be used with these USB UART devices. In Linux, this driver file name is cdc-acm.
If your computer does not recognise the ESP32S3’s port, you can do as follows to install the ch343 driver.

█ www.freenove.com | Preface | 39

Install the CH343 driver with the following command.
git clone https://github.com/WCHSoftGroup/ch343ser_linux.git

Enter the folder.
cd ch343ser_linux/driver/

Compile and generate the ch343.ko file. make

40 | Preface | www.freenove.com █

Load the generated file to the system.
sudo make load
sudo make install

Connect the ESP32S3 to your computer, check the port with the following command and you should see the port.
ls /dev/tty*

Accessing “ttyACM0” in Ubuntu requires higher privileges, so permission escalation via command is mandatory.
sudo usermod -a -G dialout $USER
sudo reboot

Please note that the configure takes effect after rebooting.

## Installing Python (Required)

## Windows

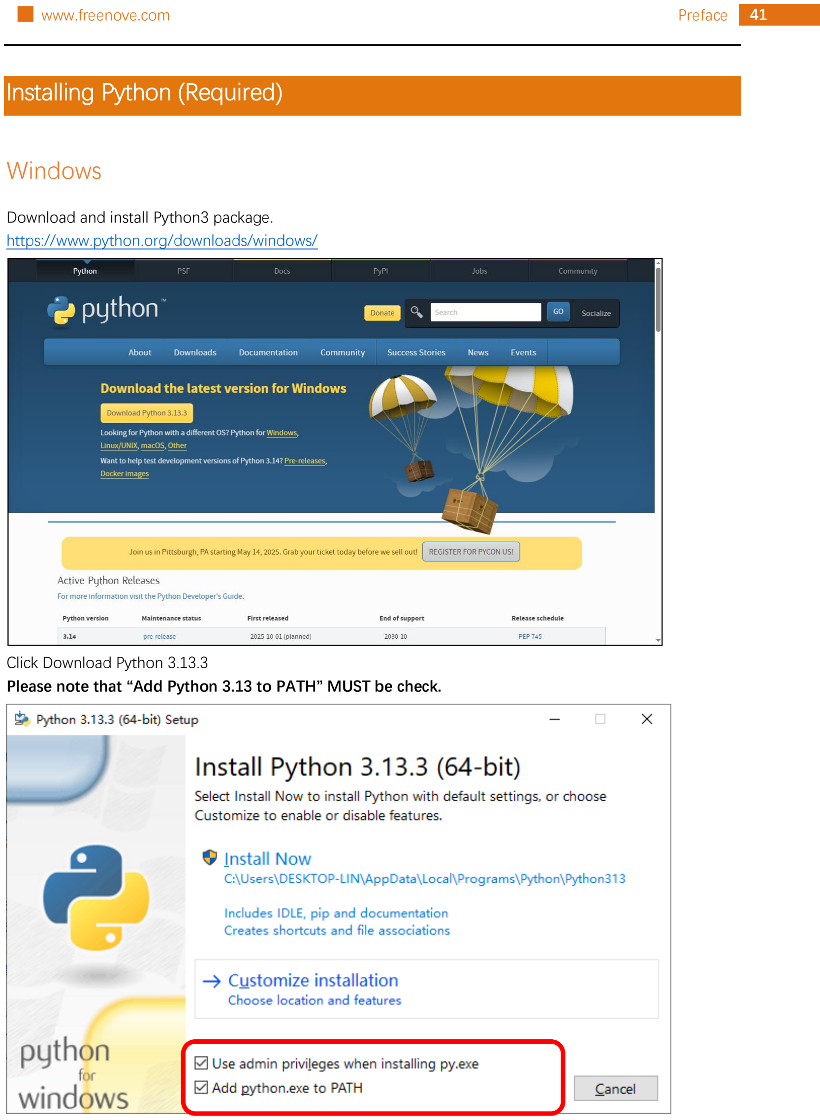
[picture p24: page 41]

█ www.freenove.com | Preface | 41

Download and install Python3 package. https://www.python.org/downloads/windows/

Click Download Python 3.13.3
Please note that “Add Python 3.13 to PATH” MUST be check.

42 | Preface | www.freenove.com █

Check all the options and then click “Next”.

Here you can select the installation path of Python. We install it at D drive. If you are a novice, you can select the default path.

█ www.freenove.com | Preface | 43

Wait for it to finish installing.

Now the installation is finished.

## MAC

44 | Preface | www.freenove.com █

Download installation package, link: https://www.python.org/downloads/ Click Download Python 3.13.3

Run the downloaded installation package. Click Continue

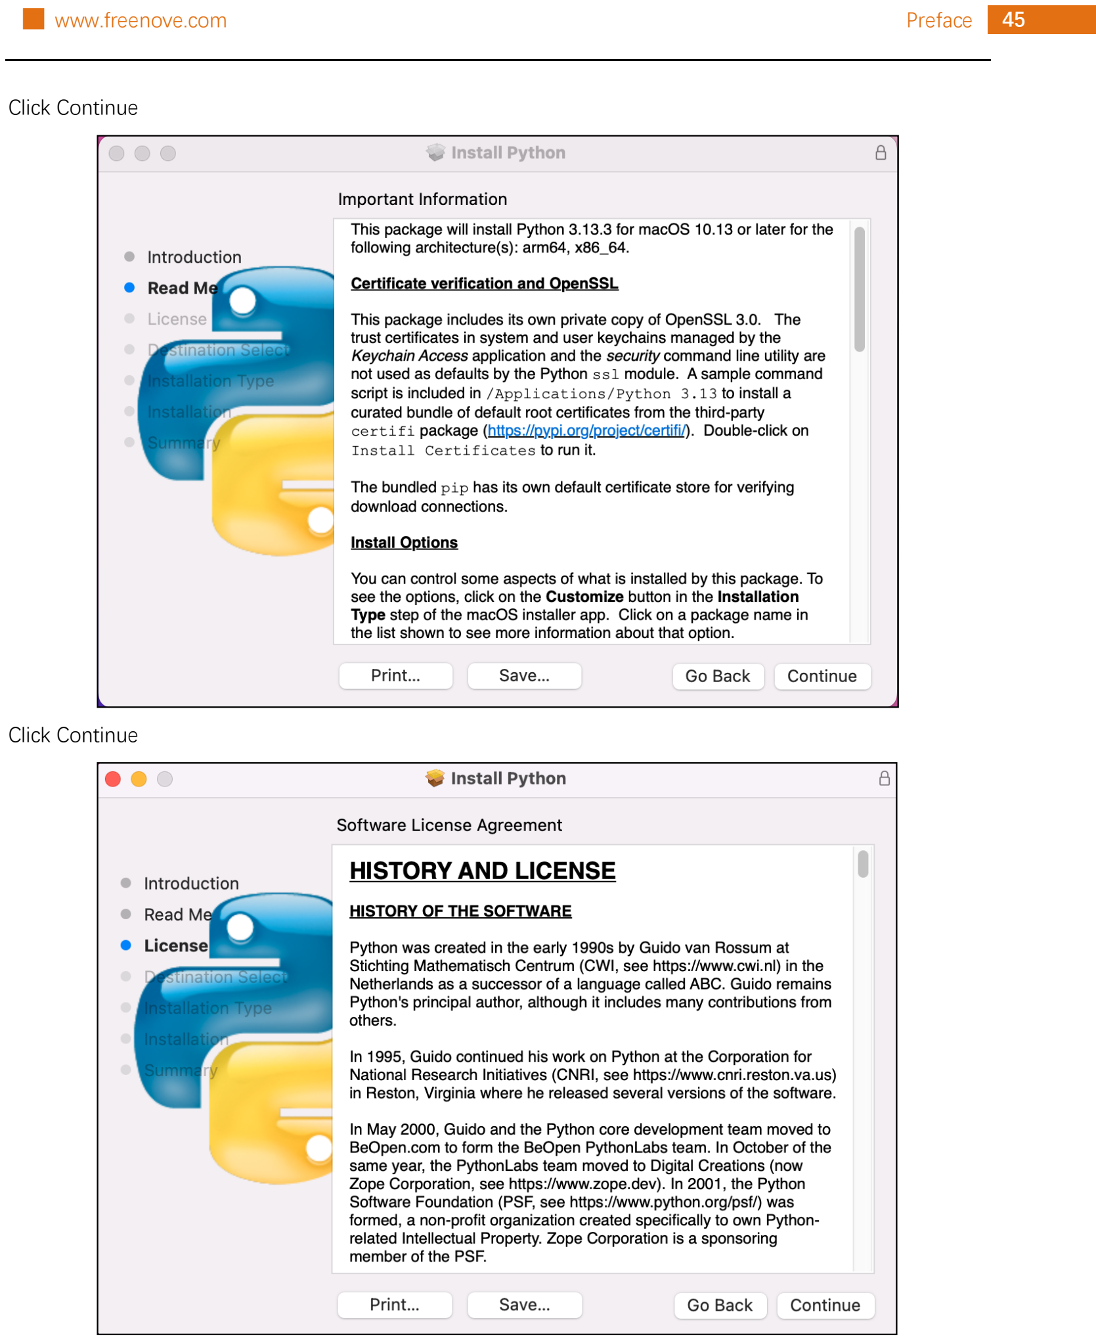
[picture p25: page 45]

█ www.freenove.com | Preface | 45

Click Continue

Click Continue

46 | Preface | www.freenove.com █

Click Install. If your computer has a password, enter the password and Install Software.

Now the installation succeeds.

## Linux

█ www.freenove.com | Preface | 47

Check whether Python3 is installed in the system. python –version
python3 –version

If it has not been installed, do it by running the following command. This will install the latest version by default.
sudo apt install python3

Link python to python3.
sudo rm /usr/bin/python
sudo ln -s /usr/bin/python3 /usr/bin/python

Install python3.13-venv virtual environment. sudo apt install python3-venv

Install python3-pip.
sudo apt install python3-pip

## Programming Software

48 | Preface | www.freenove.com █

Arduino Software (IDE) is used to write and upload the code for Arduino Board. First, install Arduino Software (IDE): visit https://www.arduino.cc/en/software/

Select and download corresponding installer based on your operating system. If you are a Windows user, please select the "Windows" to download and install the driver correctly.

█ www.freenove.com | Preface | 49

After the downloading completes, run the installer. For Windows users, there may pop up an installation dialog box of driver during the installation process. When it is popped up, please allow the installation. After installation is completed, an shortcut will be generated in the desktop.

Run it. The interface of the software is as follows:

Configured board
and serial port

Toolbar

Menus

Text editor

Console

Serial Monitor

50 | Preface | www.freenove.com █

Programs written with Arduino IDE are called sketches. These sketches are written in a text editor and are saved with the file extension.ino. The editor has features for cutting/pasting and for searching/replacing text. The console displays text output by the Arduino IDE, including complete error messages and other information. The bottom right-hand corner of the window displays the configured board and serial port. The toolbar buttons allow you to verify and upload programs, open the serial monitor, and access the serial plotter.
Verify Checks your code for errors compiling it.

Upload Compiles your code and uploads it to the configured board.

Debug Troubleshoot code errors and monitor program running status.

Serial Plotter Real-time plotting of serial port data charts.

Serial Monitor Used for debugging and communication between devices and computers.

## Environment Configuration

█ www.freenove.com | Preface | 51

First, open the software platform arduino, and then click File in Menus and select Preferences.

Second, click on the symbol behind “Additional Boards Manager URLs”

52 | Preface | www.freenove.com █

Third, fill in https://raw.githubusercontent.com/espressif/arduino-esp32/gh-pages/package_esp32_index.json (https://raw.githubusercontent.com/espressif/arduino-esp32/gh-pages/package_esp32_index.json) in the new window, click OK, and click OK on the Preferences window again.

Note: if you copy and paste the URL directly, you may lose the “-”. Please check carefully to make sure the link is correct.

Fourth, click “Boards Manager”. Enter “esp32” in Boards manager, select 3.2.0, and click “INSTALL”.

Note: Currently only version 3.0.7 is supported. Higer versions may lead to code running failure.

█ www.freenove.com | Preface | 53

Arduino will download these files automatically. Wait for the installation to complete.

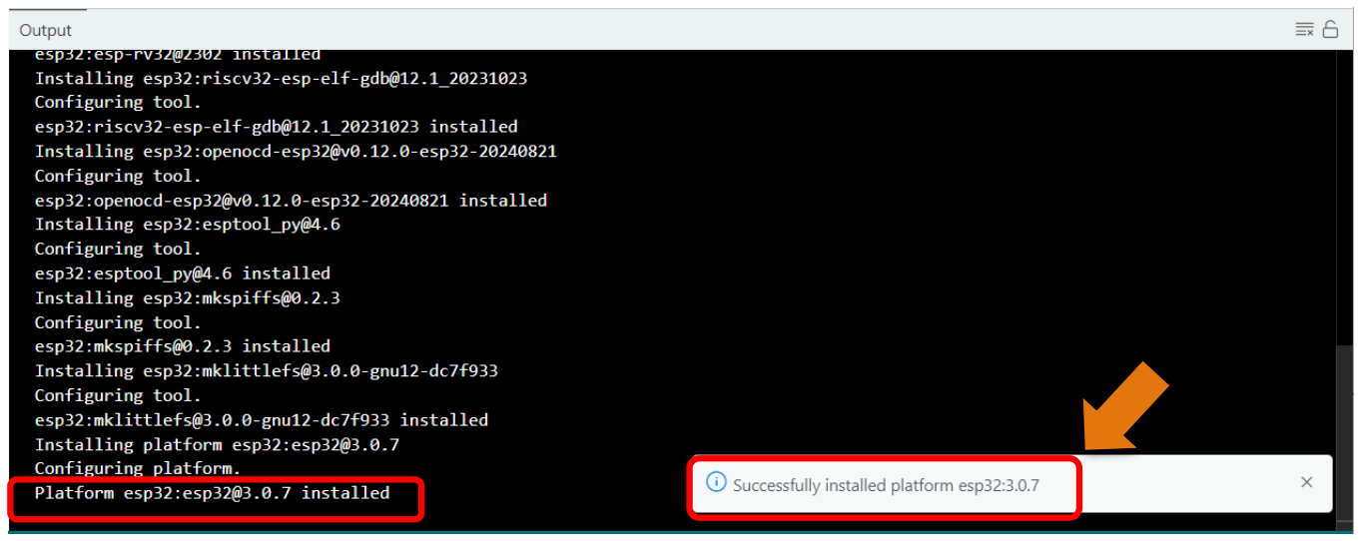
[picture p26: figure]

When finishing installation, click Tools in the Menus again and select Board: “ESP32S3 Dev Module”, and then you can see information of ESP32-S3.

54 | Preface | www.freenove.com █

## Library Installation

█ www.freenove.com | Preface | 55

Before starting the learning process, it is necessary to install some libraries in advance to enable the code to be compiled properly. For convenience, we have already packaged these libraries and placed them in the Freenove_Media_Kit_for_ESP32-S3/Libraries folder. Please refer to the following steps to install these libraries into the Arduino IDE.
1. Open Arduino IDE.
2. Select Sketch->Include Library->Add .ZIP library….

56 | Preface | www.freenove.com █
3. On the newly pop-up window, select the files from the Freenove_Media_Kit_for_ESP32-S3/Libraries. Click Open to install the library.
4. Repeat the above steps until all the six libraries are installed to Arduino. So far, all libraries have been installed.

Note: Some libraries are not the latest version. Please do not update them even if it prompts every time you open the IDE. Just click LATER. Otherwise, it may lead to compilation failure.

█ www.freenove.com | Chapter 0 Assembly | 57

# Chapter 0 Assembly

## 1.14inch

If the product you received is pre-assembled, you can skip this chapter.

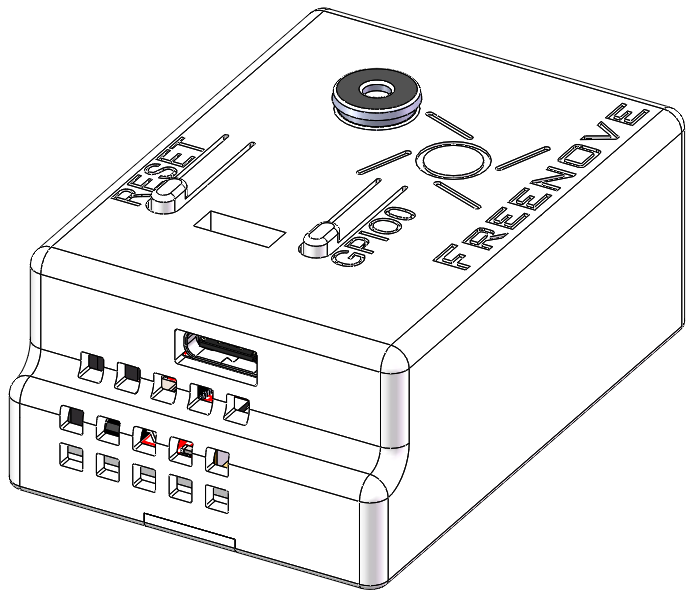
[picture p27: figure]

If you need to assemble it, please follow the following instructions step by step to proceed. First, connect the camera to the board.

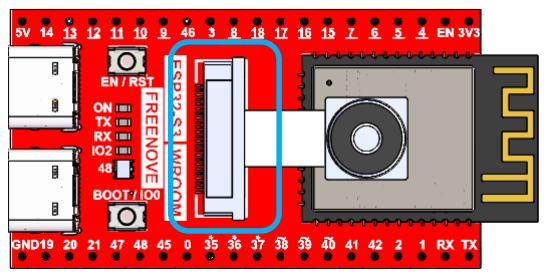
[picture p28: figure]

1. Do not remove or install the camera while power is on to avoids potential short circuits or damage during hot-plugging.
2. The camera socket features a flip-top design—gently lift the cover to install the camera. Avoid forceful handling.
3. Fully insert the camera into the socket until it reaches the end.

58 | Chapter 0 Assembly | www.freenove.com █

Plug the ESP32S3 onto the extension board.

1. Pay attention to the orientation of the board. Installing reversely may damage the board.
2. Align the two board pin to pin.
Connect the battery to the battery interface.
(Note: The battery is optional. You can also power the device via USB cable without installing a battery.)

Caution: Observe correct battery polarity during connection. Reverse polarity may damage the product. (If you do not use the battery, you may skip this step.)

+

█ www.freenove.com | Chapter 0 Assembly | 59

Place the battery as shwon below. (Skip this if you do not have a battery.)

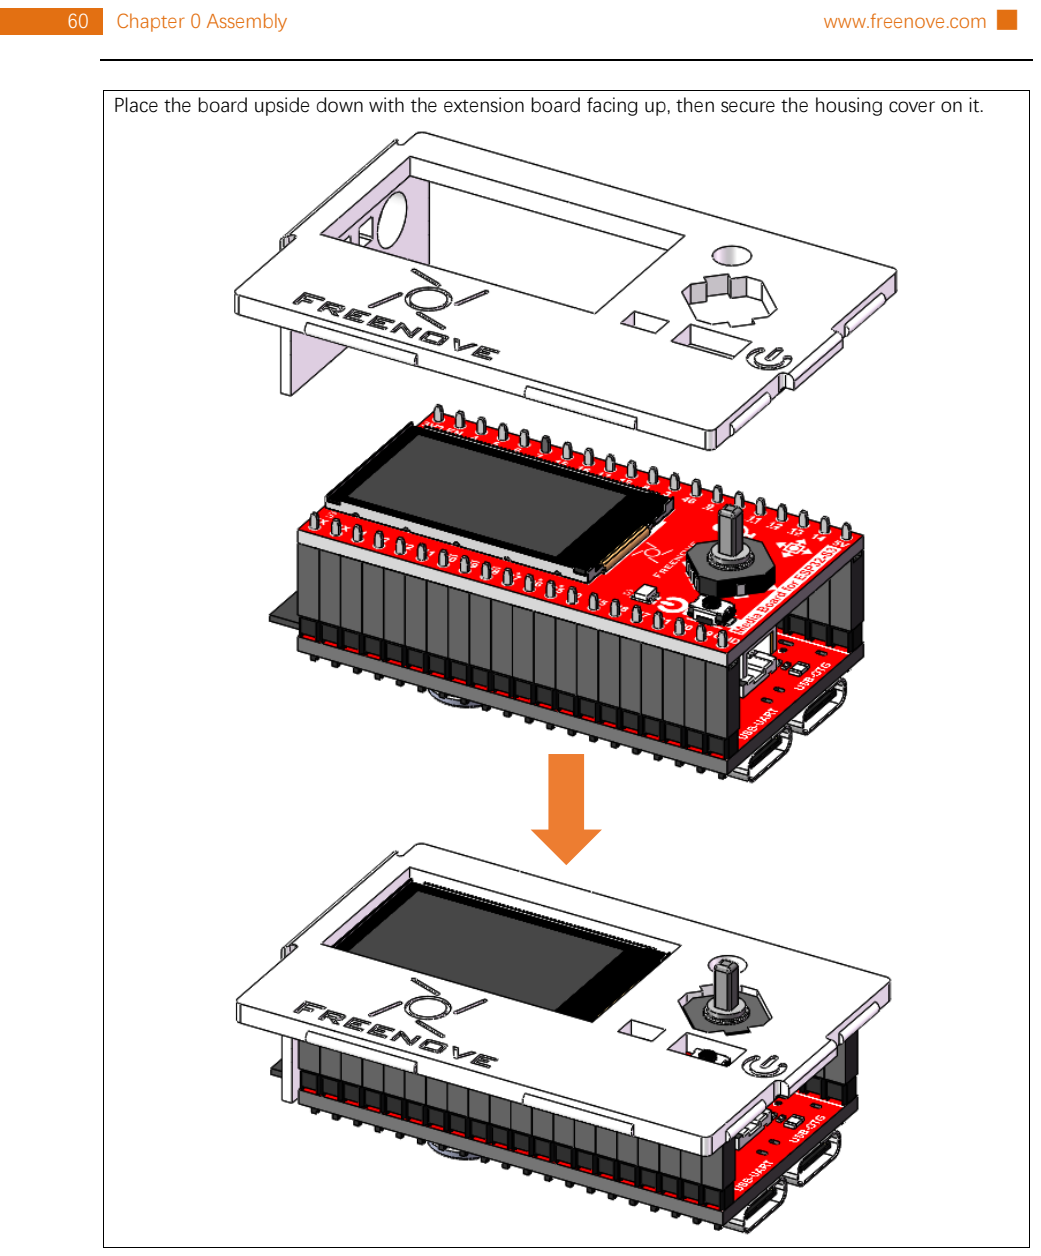
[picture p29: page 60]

60 | Chapter 0 Assembly | www.freenove.com █

Place the board upside down with the extension board facing up, then secure the housing cover on it.

█ www.freenove.com | Chapter 0 Assembly | 61

Align the housing cover with the base and secure both components together.

Align the housing cover with the snap-fit on the base. Gently press down until fully seated.

Note: The housing is fragile. Avoid forceful installation.

snap-fit

snap-fit

62 | Chapter 0 Assembly | www.freenove.com █

The installation should look like the image below once completed.

Please note that the typical accuracy of FDM-type 3D printers is 0.1–0.2 mm, so snap-fit structures may have slight looseness, which is normal.
Finally, insert the SD card to the ESP32S3.

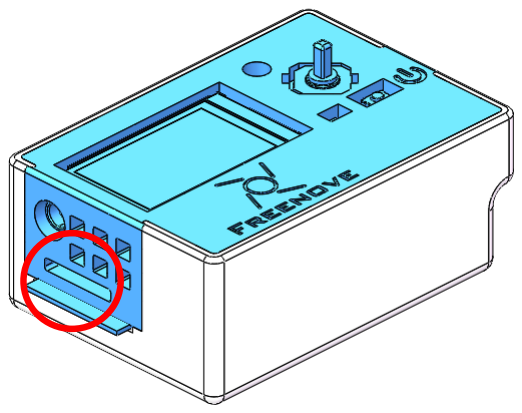
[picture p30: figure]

To depart the housing, please do as following:
Caution: The housing is fragile. Avoid using excessive force during disassembly
Gently push upward on the antenna area of the ESP32-S3 (highlighted in the circled section below) with your finger.

█ www.freenove.com | Chapter 0 Assembly | 63

## 3.5inch

If the product you received is pre-assembled, you can skip this chapter.

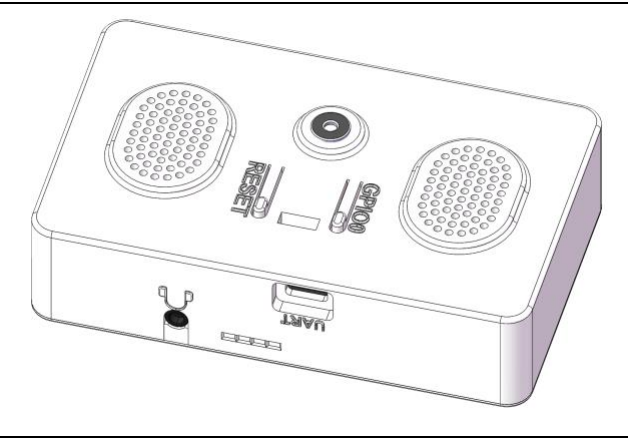
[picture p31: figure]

If you need to assemble it, please follow the following instructions step by step to proceed. First, connect the camera to the board.

1. Do not remove or install the camera while power is on to avoids potential short circuits or damage during hot-plugging.
2. The camera socket features a flip-top design—gently lift the cover to install the camera. Avoid forceful handling.
3. Fully insert the camera into the socket until it reaches the end.

64 | Chapter 0 Assembly | www.freenove.com █

Plug the ESP32S3 onto the extension board.

1. Pay attention to the orientation of the board. Installing reversely may damage the board.
2. Align the two board pin to pin.
Connect the battery to the battery interface.
(Note: The battery is optional. You can also power the device via USB cable without installing a battery.)

Caution: Observe correct battery polarity during connection. Reverse polarity may damage the product. (If you do not use the battery, you may skip this step.)

+

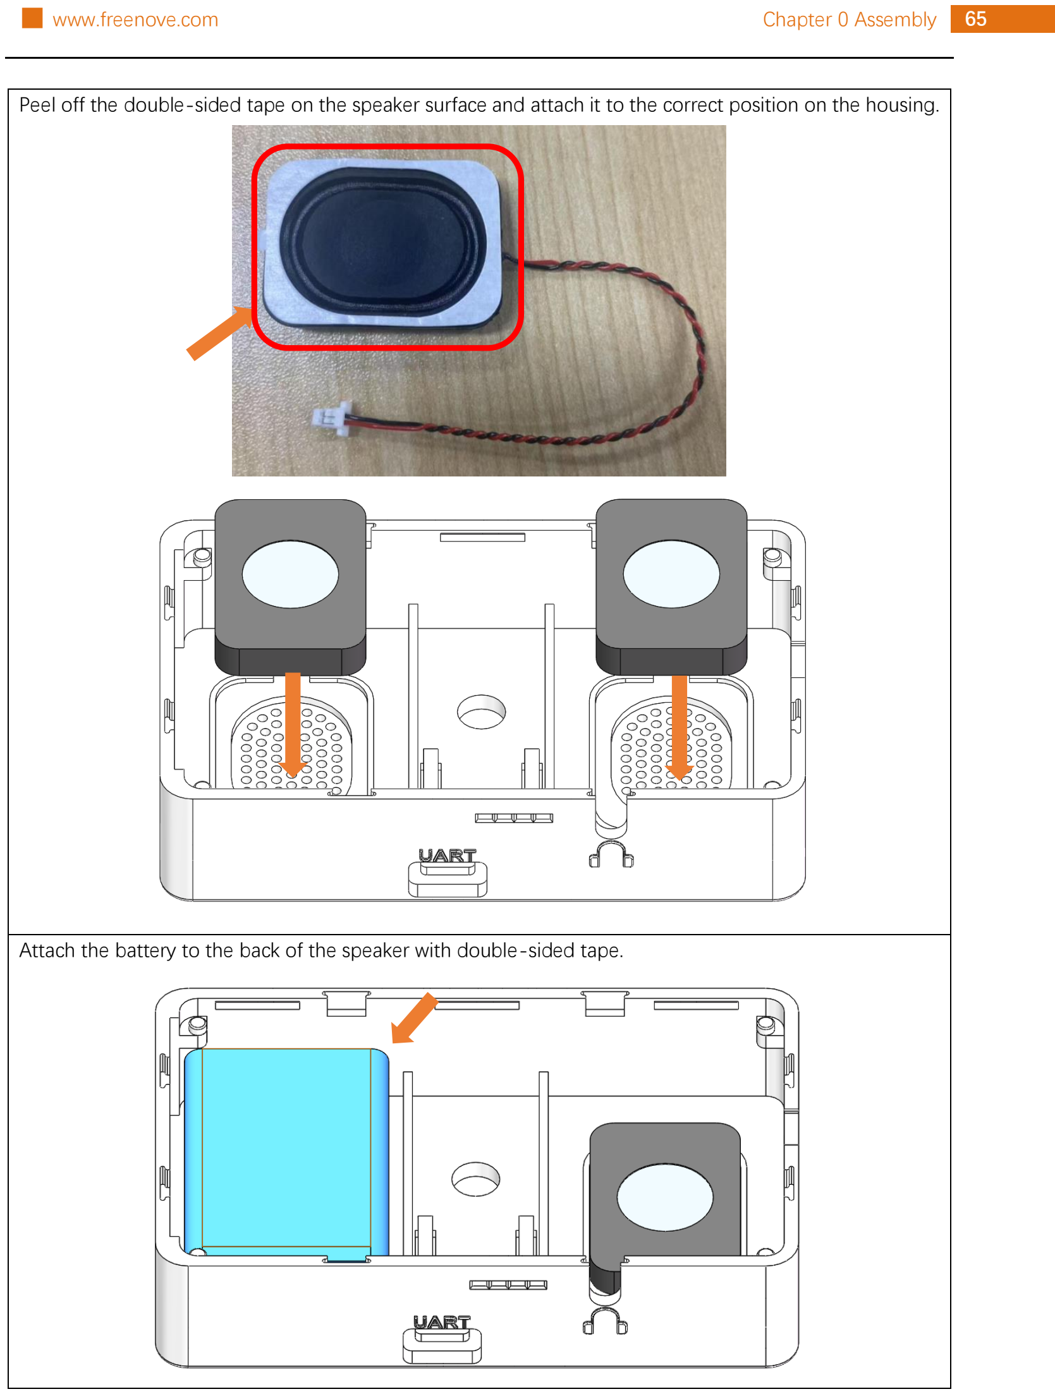
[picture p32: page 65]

█ www.freenove.com | Chapter 0 Assembly | 65

Peel off the double-sided tape on the speaker surface and attach it to the correct position on the housing.

Attach the battery to the back of the speaker with double-sided tape.

66 | Chapter 0 Assembly | www.freenove.com █

Conenct the speaker cable to the extension board.

Put the extension board to the housing.

█ www.freenove.com | Chapter 0 Assembly | 67

After assembly

Align the housing with the slot for installation.
Caution: The housing is fragile. Please handle with care during installation.

68 | Chapter 0 Assembly | www.freenove.com █

Assembly Complete

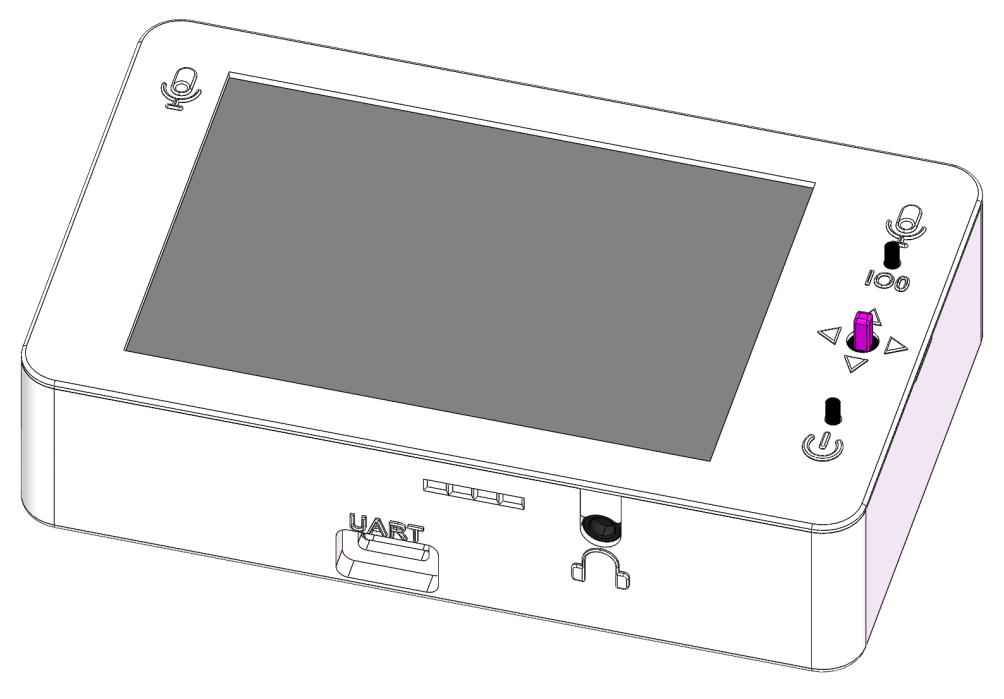
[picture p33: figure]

█ www.freenove.com | Chapter 1 LEDPixel Test | 69

# Chapter 1 LEDPixel Test

In this chapter, we will learn how to drive an RGB LED by assigning specific pins to control its color output.

## Project 1.1 LEDPixel

Learn the basic usage of WS2812 and use it to flash red, green, blue and white.
Note: Both the LED Pixels on the ESP32S3 board and on the extension board are connected to IO48 pin, so they will always maintain perfectly synchronized lighting effects.

## Component List

As of the time of writing, the Freenove Media Kit for ESP32-S3 comes in two different models with varying screen sizes. However, this tutorial applies to both versions.
Freenove ESP32-S3 x1 | USB cable x1

Extension Board x1（1.14 inch/3.5 inch）

or

70 | Chapter 1 LEDPixel Test | www.freenove.com █

## Related Knowledge

The three primary colors of light are red, green, and blue. When these colors are combined in different proportions and brightness levels, they can generate almost all colors we can see.

Freenove ESP32-S3 | 1.14inch Extension Board

3.5inch
Extension Board

█ www.freenove.com | Chapter 1 LEDPixel Test | 71

## Circuit

Connect Freenove Media Kit for ESP32-S3 to your computer using the USB cable.

## Sketch

This code uses a library named “Freenove_WS2812_Lib_for_ESP32”. If you have not yet installed it, please do so first.
How to install the library
Open Arduino IDE，click Sketch -> Include Library -> Add .ZIP Library. In the pop-up window, find the file named “./Libraries/Freenove_WS2812_Lib_for_ESP32.Zip” which locates in this directory, and click OPEN.

72 | Chapter 1 LEDPixel Test | www.freenove.com █

Sketch_01_LedPixel_RGBW

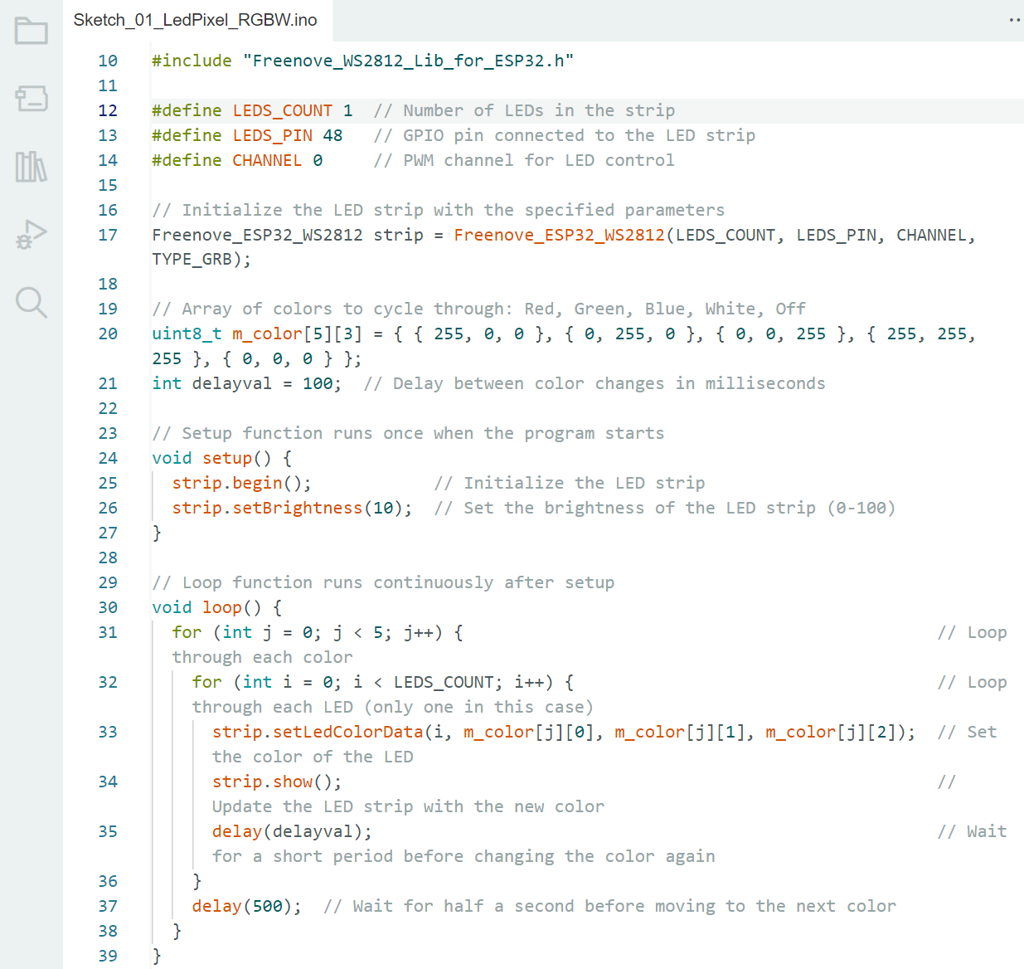
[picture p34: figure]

█ www.freenove.com | Chapter 1 LEDPixel Test | 73

The following is the program code:
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
#include “Freenove_WS2812_Lib_for_ESP32.h”

#define LEDS_COUNT 1 // Number of LEDs in the strip

#define LEDS_PIN 48 | // GPIO pin connected to the LED strip

#define CHANNEL 0 | // PWM channel for LED control

// Initialize the LED strip with the specified parameters
Freenove_ESP32_WS2812 strip = Freenove_ESP32_WS2812(LEDS_COUNT, LEDS_PIN, CHANNEL, TYPE_GRB);

// Array of colors to cycle through: Red, Green, Blue, White, Off
uint8_t m_color[5][3] = { {255, 0, 0}, {0, 255, 0}, {0, 0, 255}, {255, 255, 255}, {0, 0, 0} }; int delayval = 100; // Delay between color changes in milliseconds

// Setup function runs once when the program starts
void setup() {
strip.begin(); | // Initialize the LED strip
strip.setBrightness(10); // Set the brightness of the LED strip (0-100) }

// Loop function runs continuously after setup
void loop() {
for (int j = 0; j < 5; j++) {
for (int i = 0; i < LEDS_COUNT; i++)
strip.setLedColorData(i, m_color[j][0], m_color[j][1], m_color[j][2]); strip.show();
delay(delayval);
}
delay(500); // Wait for half a second before moving to the next color }
}
To use some libraries, first you need to include their header file.
1 #include “Freenove_WS2812_Lib_for_ESP32.h”
Define the pin connected to the WS2812, the number of WS2812, and RMT channel values. 3
4
5

#define LEDS_COUNT 1 // Number of LEDs in the strip

#define LEDS_PIN 48 | // GPIO pin connected to the LED strip

#define CHANNEL 0 | // PWM channel for LED control

Use the above parameters to create a WS2812 object strip.
7 Freenove_ESP32_WS2812 strip = Freenove_ESP32_WS2812(LEDS_COUNT, LEDS_PIN, CHANNEL, TYPE_GRB); Define the color values to be used, such as red, green, blue, white, and black.
11 uint8_t m_color[5][3] = { {255, 0, 0}, {0, 255, 0}, {0, 0, 255}, {255, 255, 255}, {0, 0, 0} }; Define a variable to set the time interval for each led to light up. The smaller the value is, the faster it will light up.
12 int delayval = 100; // Delay between color changes in milliseconds

74 | Chapter 1 LEDPixel Test | www.freenove.com █

Initialize strip() in setup() and set the brightness.
13
14
strip.begin(); | // Initialize the LED strip
strip.setBrightness(10); // Set the brightness of the LED strip (0-100)
In the loop(), there are two “for” loops, the internal for loop is to light the LED one by one, and the external one to switch colors. strip.setLedColorData() is used to set the color, but it does not change immediately. Only when strip.show() is called will the color data be sent to the LED to change the color.
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
for (int j = 0; j < 5; j++) {
for (int i = 0; i < LEDS_COUNT; i++)
strip.setLedColorData(i, m_color[j][0], m_color[j][1], m_color[j][2]); strip.show();
delay(delayval);
}
delay(500); // Wait for half a second before moving to the next color }
Select Tools –> Board -> esp32 -> ESP32S3 Dev Module.

After connecting the Freenove Media Kit for ESP32-S3, the system will assign a serial communication port named in the format 'COMx' (where 'x' is a numeric ID that may vary across computers). You must select the correct port under Tools → Port.
Note: COM1 is typically NOT the port used by the Freenove Media Kit for ESP32-S3.

█ www.freenove.com | Chapter 1 LEDPixel Test | 75

Click upload to upload the sketch to ESP32S3 board.

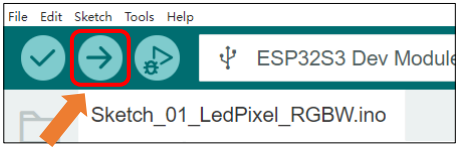
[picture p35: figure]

After successfully uploading the code, you will observe the WS2812 LEDs cycling through predefined colors (red → green → blue → white → red) in sequence. The color transitions occur at 500ms intervals, creating a smooth color-changing loop effect.

If you have any concerns, please feel free to contact us via support@freenove.com Reference

Freenove_ESP32_WS2812(u16 n = 8, u8 pin_gpio = 2, u8 chn = 0, LED_TYPE t = TYPE_GRB) Constructor to create a ws2812 object.
Before each use of the constructor, please add “#include “Freenove_WS2812_Lib_for_ESP32.h” Parameters
n: The number of led.
pin_gpio: The pin connected to the LED.
Chn: RMT channel, which has eight channels, 0-7, and uses channel 0 by default. This means that you can use eight ws2812 modules for the display at the same time, and these modules do not interfere with each other.
t: Types of LED.
TYPE_RGB：The sequence of ws2812 module loading color is red, green and blue.
TYPE_RBG：The sequence of ws2812 module loading color is red, blue and green. TYPE_GRB：The sequence of ws2812 module loading color is green, red and blue. TYPE_GBR：The sequence of ws2812 module loading color is green, blue and red. TYPE_BRG：The sequence of ws2812 module loading color is blue, red and green. TYPE_BGR：The sequence of ws2812 module loading color is blue, green and red.
500ms | 500ms | 500ms

500ms

76 | Chapter 1 LEDPixel Test | www.freenove.com █

void begin(void);
Initialize the LEDPixel object

void setLedColorData (u8 index, u8 r, u8 g, u8 b); void setLedColorData (u8 index, u32 rgb);
void setLedColor (u8 index, u8 r, u8 g, u8 b); void setLedColor (u8 index, u32 rgb);
Set the color of led with order number n.

void show(void);
Send the color data to the led and display the set color immediately.

void setBrightness(uint8_t);
Set the brightness of the LED.

To learn more about the library, you may visit the following website: https://github.com/Freenove/Freenove_WS2812_Lib_for_ESP32

█ www.freenove.com | Chapter 2 Battery Voltage Detection | 77

# Chapter 2 Battery Voltage Detection

ADC is used to convert analog signals into digital signals. Control chip on the control board has integrated this function. Now let us try to use this function to convert analog signals into digital signals

For battery precautions and selection guidelines, please refer to Battery.

## Project 2.1 Battery Voltage Value

## Component List

As of the time of writing, the Freenove Media Kit for ESP32-S3 comes in two different models with varying screen sizes. However, this tutorial applies to both versions.
Freenove ESP32-S3 x1 | USB cable x1

Extension Board x1（1.14 inch/3.5 inch）

or

78 | Chapter 2 Battery Voltage Detection | www.freenove.com █

## Related Knowledge

| ADC
An ADC is an electronic integrated circuit used to convert analog signals such as voltages to digital or binary form consisting of 1s and 0s.The onboard ADC module is set to 10 bits by default, which means the resolution is 2^10=1024, so its range (at 5V) will be evenly divided into 1024 parts. By default, the resolution of the onboard ADC is set to 10 bits, which can be updated to 12 bits (0-4096) and 14 bits (0-16383) resolution to improve the accuracy of the analog readings. Any analog value can be mapped to one digital value using the resolution of the converter. So the more bits the ADC has, the denser the partition of analog will be and the
| greater the precision of the resulting conversion.

Subsection 1: the analog in rang of 0V-5/1024V corresponds to digital 0; Subsection 2: the analog in rang of 5 /1024V-2*5/1024V corresponds to digital 1;

The following analog signal will be divided accordingly.
The conversion formula is as follows:

# ADC Value =

# Analog Voltage

3.3

∗ 1023

█ www.freenove.com | Chapter 2 Battery Voltage Detection | 79

Kirchhoff's Laws
Kirchhoff's Laws are the two fundamental principles of circuit analysis, formulated by German physicist Gustav Kirchhoff in 1845. Consisting of Kirchhoff’s Current Law (KCL) and Voltage Law (KVL), they are applicable to all lumped-parameter circuits — regardless of whether they are linear or nonlinear, time-varying or time-invariant. These laws represent one of the key manifestations of the conservation of energy in electrical circuits.

Kirchhoff’s Current Law (KCL) states:
At any given node in a lumped-parameter circuit, the algebraic sum of all currents entering (or leaving) the node at any instant is always zero.
Mathematically, this is expressed as:

∑ Ik = 0

n

k=1

Kirchhoff’s Voltage Law (KVL) states:
In any closed loop of a circuit, the algebraic sum of all voltage drops is always equal to zero. Mathematically, this is expressed as:
∑ Uk = 0

n

k=1
Ohm's Law
Ohm's Law, formulated by the German physicist Georg Simon Ohm in 1827, is one of the most fundamental laws in circuit theory. It defines the basic relationship between voltage and current in a linear resistive element: Under constant temperature conditions, the current (I) flowing through a conductor is directly proportional to the voltage (U) across it and inversely proportional to the conductor's resistance (R).

Mathematically, it is expressed as:

## U = I × R

Where:
- U represents Voltage（Unit: Volt,V）
- I refer to current（Unit: Ampere, A）
- R denotes resistance（Unit:: Ohm, Ω）

Based on the above, the following relationships can be derived from the formula:

I =

U
R

R =

U
I

Battery Voltage Detection
The maximum input voltage for the GPIO pins of the Freenove Media Kit for ESP32-S3 is 3.3V. Exceeding this limit may cause permanent damage to the device. Since the full charge voltage of a 3.7V lithium battery can theoretically reach 4.2V, it is strictly prohibited to directly connect the lithium battery to the GPIO pins of the Freenove Media Kit for ESP32-S3. The input voltage must be regulated within the safe range through circuit

80 | Chapter 2 Battery Voltage Detection | www.freenove.com █

design (as shown in the figure below).

The schematic above can be simplified as the following equivalent circuit for easier understanding.

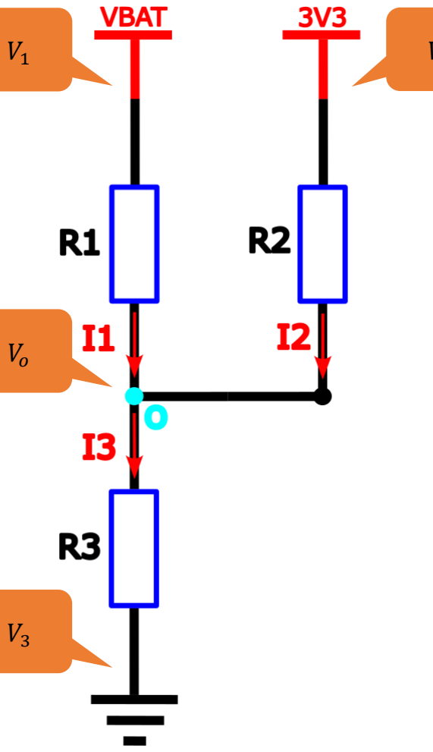
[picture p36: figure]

Based on Kirchhoff's Current Law (KCL), we can derive that:

## I1 + I2 + I3 = 0

Accoding to the following formula of Ohm’s Law

I =

U
R

It can be further deduced that:
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
█ www.freenove.com | Chapter 2 Battery Voltage Detection | 81

Since voltage is the difference in potential, it can be converted into:

## V1 − Vo

R1

+

## V2 − Vo

R2

+

## V3 − Vo

R3

= 0

By simplifying it, we can get:

## V1 = Vo (1 +

R1
R2

+

R1
R3

) − V2 ×

R1
R2

− V3 ×

R1
R3

Substituting the actual resistance value, we can finally get

## V1 = Vo × 2. 5 − 3300

Where:
R1 = 10KΩ, R2 = 10KΩ, R3 = 20KΩ, The unit of V1 is millivolt(mV).

## Circuit

Connect Freenove Media Kit for ESP32-S3 to your computer using the USB cable.

Connect the battery to Freenove Media Kit for ESP32-S3.
For battery precautions and selection guidelines, please refer to Battery.

## Sketch

Sketch_02_1_Battery_Volts
1 | #define BATTERY_MIN 3200
2 | #define BATTERY_MAX 4200
3
4
5
6 | void setup() {
7 | // Setup code to run once:
8 | Serial.begin(115200); // Set baud rate to 115200
9 | pinMode(BATTERY_PIN, INPUT); // Set battery voltage detection pin to input mode
10 | analogReadResolution(12); // Set ADC resolution to 12 bits
11 | analogSetAttenuation(ADC_11db);// Set attenuation to 11dB

const uint8_t BATTERY_PIN = 20;

82 | Chapter 2 Battery Voltage Detection | www.freenove.com █

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
void loop() {
// Main code to run repeatedly: battery_read();
}

void battery_read() {
int total_value = 0, valid_time = 0, adc_value = 0, battery_volts = 0; // Sample 20 times for filtering
for(int i = 0; i < 20; i++) {
// Read ADC value
adc_value = analogReadMilliVolts(BATTERY_PIN);
// Calculate battery voltage using voltage divider (unit: mV) battery_volts = (adc_value * 2.5) - 3300;
// Filter out abnormal values
if(battery_volts > BATTERY_MIN && battery_volts < BATTERY_MAX) { total_value += battery_volts;
valid_time++;
}
delay(50);
}
// Calculate average of valid measurements if(valid_time != 0)
battery_volts = total_value / valid_time;

// Output results
Serial.printf(“valid time: %d, battery volts: %.2fV\n”, valid_time,battery_volts/1000.0); }
Define the maximum and minimum voltage range 1
2

#define BATTERY_MIN 3200

#define BATTERY_MAX 4200

Define battery voltage detection pin.
4 const uint8_t BATTERY_PIN = 20;
Set the serial baud rate to 115200.
8 Serial.begin(115200); // Set baud rate to 115200
Set the ADC resolution to 12-bit, providing a measurement range of 0 to 4095 (2¹² - 1).
10 analogReadResolution(12);
Set the ADC attenuation factor to 11db
11 analogSetAttenuation(ADC_11db);// Set attenuation to 11dB
Perform cyclic sampling of battery voltage 20 times and apply filtering processing. 22
23
24
| for(int i = 0; i < 20; i++) {
| // Read ADC value
| adc_value = analogReadMilliVolts(BATTERY_PIN);

█ www.freenove.com | Chapter 2 Battery Voltage Detection | 83

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
// Calculate battery voltage using voltage divider (unit: mV) battery_volts = (adc_value * 2.5) - 3300;
// Filter out abnormal values
if(battery_volts > BATTERY_MIN && battery_volts < BATTERY_MAX) { total_value += battery_volts;
valid_time++;
}
delay(50);
}
Calculate the average effective battery voltage 34
35
36

// Calculate average of valid measurements if(valid_time != 0)
battery_volts = total_value / valid_time; Output battery voltage value and sampling times. 34
35

// Output results
Serial.printf(“valid time: %d, battery volts: %.2fV\n”, valid_time, battery_volts / 1000.0); Upload the code to the board and press ON the power button.

The current battery voltage value will be printed on the serial monitor.

When both the battery and USB are connected, the Freenove Media Kit for ESP32-S3 will be powered by USB and the battery will charge slowly

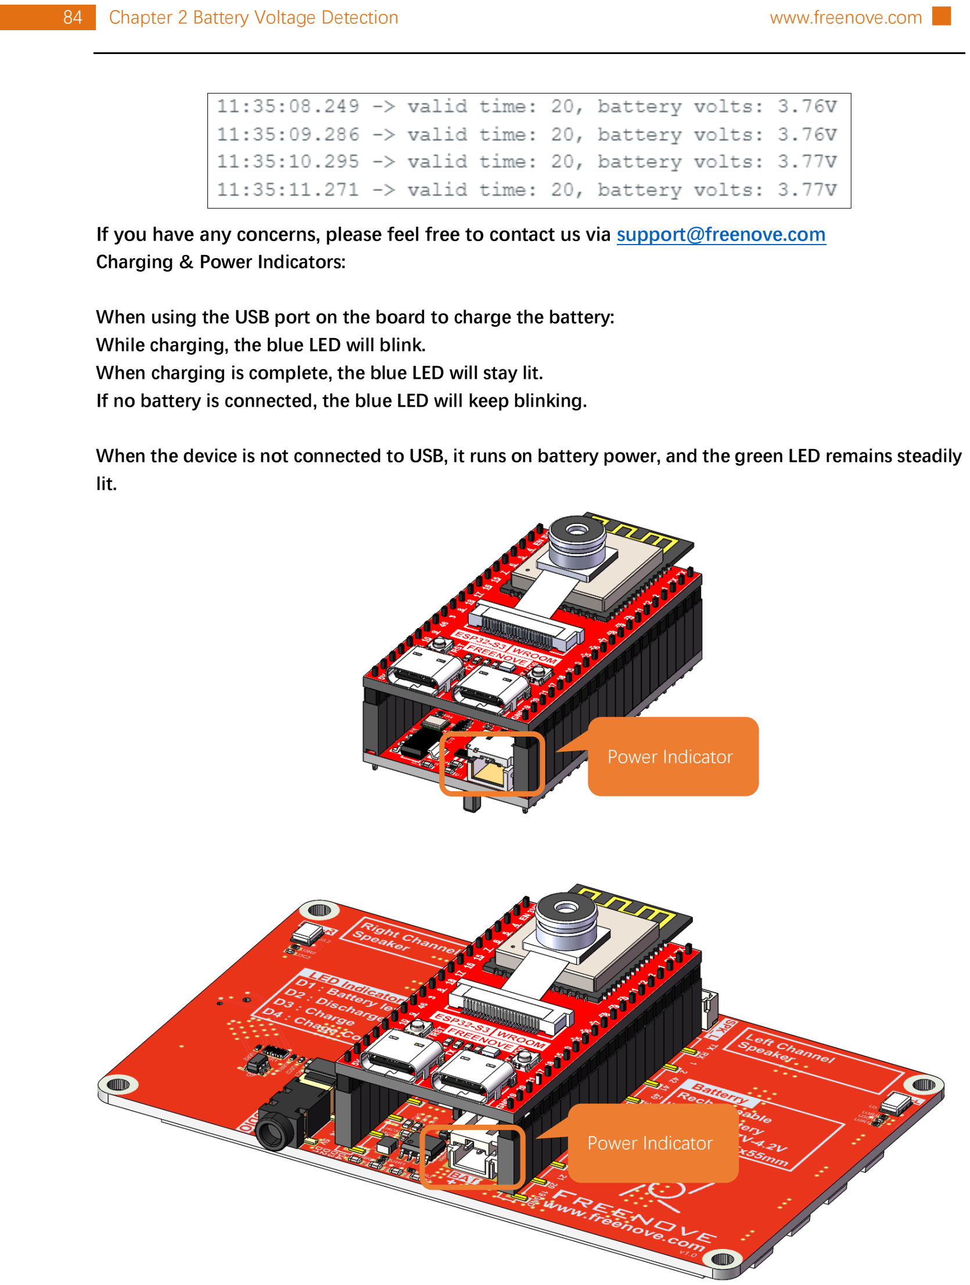
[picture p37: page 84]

84 | Chapter 2 Battery Voltage Detection | www.freenove.com █

If you have any concerns, please feel free to contact us via support@freenove.com Charging & Power Indicators:

When using the USB port on the board to charge the battery:
While charging, the blue LED will blink.
When charging is complete, the blue LED will stay lit.
If no battery is connected, the blue LED will keep blinking.

When the device is not connected to USB, it runs on battery power, and the green LED remains steadily lit.

Power Indicator

Power Indicator

█ www.freenove.com | Chapter 2 Battery Voltage Detection | 85

Reference

analogReadResolution(uint8_t bits)
This function is used to configure the ADC's conversion resolution and measurement range.

Parameters
bits: The resolution in bits. Higher bit values result in greater measurement precision.
ADC sampling range: 0 to (2^bits – 1).

analogSetAttenuation(adc_attenuation_t attenuation)
This function configures the input signal attenuation factor for the ADC.

Parameters
attenuation: Attenuation multiple
ADC_0dB: Voltage measurement range: 0mV ~ 950mV. ADC_2_5dB: Voltage measurement range: 0mV ~ 1250mV. ADC_6dB: Voltage measurement range: 0mV ~ 1750mV.
ADC_11dB: Voltage measurement range: 0mV ~ 3100mV.

analogReadMilliVolts(uint8_t pin)
This function reads the voltage value (in millivolts, mV) from an analog pin.

Parameters
pin: Pin number.

86 | Chapter 3 5-Way Navigation Switch Test | www.freenove.com █

# Chapter 3 5-Way Navigation Switch Test

In the previous section, we covered ADC concepts. This section will discuss the working principles and operation of a 5-way navigation switch, as there is some relevance between the two topics.

## Project 3.1 Button Value

## Component Knowledge

5-way Navigation Switch
The 5-way navigation switch is a digital switch that supports actuation in five directions: up, down, left, right, and center (press).

Its operation is as follows:
No press: All terminals (A, B, C, D, O, Com) remain open (non-conducting). Center press: O and Com make contact (conduct).
Upward push: D and Com make contact.
Downward push: B and Com make contact.
Leftward push: A and Com make contact.
Rightward push: C and Com make contact.
This switch is widely used in applications requiring directional input, such as game controllers, remote controls, and navigation interfaces.

█ www.freenove.com | Chapter 3 5-Way Navigation Switch Test | 87

## Component List

As of the time of writing, the Freenove Media Kit for ESP32-S3 comes in two different models with varying screen sizes. However, this tutorial applies to both versions.
Freenove ESP32-S3 x1 | USB cable x1

Extension Board x1（1.14 inch/3.5 inch）

or

## Circuit

Connect Freenove Media Kit for ESP32-S3 to your computer using the USB cable.

88 | Chapter 3 5-Way Navigation Switch Test | www.freenove.com █

## Schematic

We use the ADC function of GPIO19 to read the voltage value of Com and determine which direction
| of the 5-way button is pressed based on different voltage values. The circuit schematic is as follows.

Typically, we read the ADC value from GPIO19 and treat any value within the range of [(ADC - 50), (ADC + 50)] as a valid button press. Please refer to the code in Sketch_02_1_Button_Value and Sketch_02_2_Button to better understand this logic.

## Sketch

Sketch_03_1_Button_Value
The following is the program code: 1
2
3 | void setup() {
4 | // Initialize serial communication at 115200 bits per second
5 | Serial.begin(115200);
6
7 | // Set the ADC resolution to 12 bits (0-4095)
8 | analogReadResolution(12);
9 | // Set the ADC attenuation to 11 dB
10 | analogSetAttenuation(ADC_11db);
11 | }
12
13 | void loop() {
14 | // Read the analog/millivolts value for pin 20
15 | int analogValue = analogReadMilliVolts(BUTTON_PIN);
16 | // Print the ADC value to the serial monitor
17 | Serial.printf(“ADC value = %d\n”, analogValue);
18
19

#define BUTTON_PIN 19 // GPIO pin connected to the button

// Delay in between reads for clear read from serial

█ www.freenove.com | Chapter 3 5-Way Navigation Switch Test | 89

20
21

delay(100);
}
Define the pin connected to the 5-way navigation button.
1 #define BUTTON_PIN 19 // GPIO pin connected to the button Set the serial baud rate to 115200.
5 Serial.begin(115200);
Set the ADC resolution to 12-bit, providing a measurement range of 0 to 4095 (2¹² - 1).
8 analogReadResolution(12);
Set the ADC input attenuation level to define the measurable voltage range
10 analogSetAttenuation(ADC_11db);
Read the voltage value from GPIO19 in millivolts (mV).
15 int analogValue = analogReadMilliVolts(BUTTON_PIN); Print the GPIO19 voltage reading to the serial monitor.
17 Serial.printf(“ADC value = %d\n”, analogValue); Open the serial monitor upon the code upload completes.

Select the correct baud rate (115200).

90 | Chapter 3 5-Way Navigation Switch Test | www.freenove.com █

The serial monitor will display the ADC sampling values of the GPIO19 pin in real time. When operating the 5-way switch, the corresponding ADC values will dynamically update according to the switch state.

If you have any concerns, please feel free to contact us via support@freenove.com

Reference

analogReadResolution(uint8_t bits)
This function is used to configure the ADC's conversion resolution and measurement range.

Parameters
bits: The resolution in bits. Higher bit values result in greater measurement precision.
ADC sampling range: 0 to (2^bits – 1).

analogSetAttenuation(adc_attenuation_t attenuation)
This function configures the input signal attenuation factor for the ADC.

Parameters
attenuation: Attenuation multiple
ADC_0dB: Voltage measurement range: 0mV ~ 950mV. ADC_2_5dB: Voltage measurement range: 0mV ~ 1250mV. ADC_6dB: Voltage measurement range: 0mV ~ 1750mV.
ADC_11dB: Voltage measurement range: 0mV ~ 3100mV.

analogReadMilliVolts(uint8_t pin)
This function reads the voltage value (in millivolts, mV) from an analog pin.

Parameters
pin: Pin number.

█ www.freenove.com | Chapter 3 5-Way Navigation Switch Test | 91

## Project 3.2 Button

In the previous section, we learned how to read the ADC values of the 5-way navigation button. In this section, we will learn how to accurately determine the specific direction that the button moves based on these ADC values.

## Component List

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

Extension Board x1（1.14 inch/3.5 inch）

or

## Circuit

Connect Freenove Media Kit for ESP32-S3 to your computer using the USB cable.

92 | Chapter 3 5-Way Navigation Switch Test | www.freenove.com █

## Component Knowledge

| Button Bouncing
Push buttons, as common mechanical input devices, utilize metal contacts and a return spring in their internal structure. However, due to the inherent physical properties of mechanical contacts, instantaneous stable conduction or disconnection cannot be achieved upon pressing or releasing. Instead, rapid mechanical bouncing occurs, generating a series of unstable on-off signals during the transition. This phenomenon,
| known as contact bounce, is also observed in 5-way navigation switches.

To ensure signal accuracy and reliability, effective debounce strategies must be incorporated into the system design. These measures mitigate the effects of mechanical bounce, providing clean and consistent input
| signals for downstream processing.

Metal contacts

█ www.freenove.com | Chapter 3 5-Way Navigation Switch Test | 93

## Sketch

Sketch_03_2_Button
The following is the program code:
1
2
3 | #define BUTTON_PIN 19 // GPIO pin connected to the button
4 | Button button(BUTTON_PIN);
5
6 | void setup() {
7 | // Initialize serial communication at 115200 bits per second
8 | Serial.begin(115200);
9 | // Initialize the button
10 | button.init();
11 | }
12
13 | void loop() {
14 | // Scan for button events
15 | button.key_scan();
16 | // Handle button events
17 | handleButtonEvents();
18 | // Delay to prevent excessive CPU usage
19 | delay(50);
20 | }
21
22 | void handleButtonEvents() {
23 | // Get the current state of the button
24 | int buttonState = button.get_button_state();
25 | // Get the key value of the button
26 | int buttonKeyValue = button.get_button_key_value();
27 | // Handle different button states
28 | switch (buttonState) {
29 | case Button::KEY_STATE_PRESSED:
30 | Serial.println(String(buttonKeyValue) + “ Pressed.”);
31 | break;
32 | case Button::KEY_STATE_RELEASED:
33 | Serial.println(String(buttonKeyValue) + “ Released.”);
34 | break;
35 | default:
36 | break;
37 | }
38 | }

#include “driver_button.h”

94 | Chapter 3 5-Way Navigation Switch Test | www.freenove.com █

Define the pin connecting to the switch.
1 #define BUTTON_PIN 19 // GPIO pin connected to the button Define the object of the switch.
8 Button button(BUTTON_PIN);
Set the baud rate to 115200.
8 Serial.begin(115200);
Initialize the switch.
10 button.init();
Scan the state of the button periodically.
15 button.key_scan();
Handle button events.
17 handleButtonEvents();
Reference
Button:init();
This function is used to initialize the button.
Button:key_scan();
The function is used to scan the state of the switch and needs to be placed in the loop() function for periodic scanning.
Button:get_button_state();
This function is used to read the state of the 5-way navigation switch.

Switch states:

KEY_STATE_IDLE: The switch is inactive (no trigger detected).
KEY_STATE_PRESSED_BOUNCE_TIME: Button press detected, debouncing in progress (filtering contact bounce).
KEY_STATE_PRESSED: Button press confirmed (debounce complete, valid press event). KEY_STATE_RELEASE_BOUNCE_TIME: Button release detected, debouncing in progress (filtering release bounce).
KEY_STATE_RELEASED: Button y release confirmed (debounce complete, valid release event).
Button:get_button_key_value();
The function is used to obtain the key values of a 5-way button.
The key values are as follows:

Volt_330: Not pressed (0)
Volt_000: Center (1)
Volt_264: Forward (5)
Volt_198: Backward (4)
Volt_066: Left (2)
Volt_132: Right (3)

If you have any concerns, please feel free to contact us via support@freenove.com

█ www.freenove.com | Chapter 4 SD Card Read & Write Test | 95

# Chapter 4 SD Card Read & Write Test

An SD card slot is integrated on the back of the ESP32-S3 WROOM. In this chapter, we learn how to use ESP32-S3 to read and write SDcard.

## Project 4.1 SDMMC Test

## Component List

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

Extension Board x1（1.14 inch/3.5 inch）

or

SD card x1 | Card reader x1 (random color)

96 | Chapter 4 SD Card Read & Write Test | www.freenove.com █

## Component knowledge

| SD card read and write method
The ESP32-S3 provides two primary interfaces for SD card communication: SPI and SDMMC. Each interface
| offers distinct advantages in terms of pin usage and performance:
| SPI Interface: Requires 4 I/O pins Delivers the slowest performance (approximately 50% of SDMMC 4-bit mode speed) SDMMC Interface: Offers two operational modes:

1-bit bus mode: Uses only 3 I/O pins while maintaining about 80% of the 4-bit mode's performance
| 4-bit bus mode: Requires 6 I/O pins but delivers maximum throughput
For most applications, we recommend the SDMMC 1-bit bus mode as it provides an optimal balance between pin efficiency and performance. This configuration minimizes I/O usage while still delivering
| satisfactory speed for typical use cases. Format SD card

To initiate the project, you'll first need to prepare a blank SD card and a compatible card reader. The initial setup involves assigning a drive letter to the SD card and formatting it properly. Below you'll find system-specific instructions to complete these preparatory steps. Please follow the guide corresponding to your
| operating system.

## Windows

Insert the SD card into the card reader, and then insert the card reader into the computer.
In the Windows search box, enter “Disk Management” and select “Create and format hard disk partitions”.

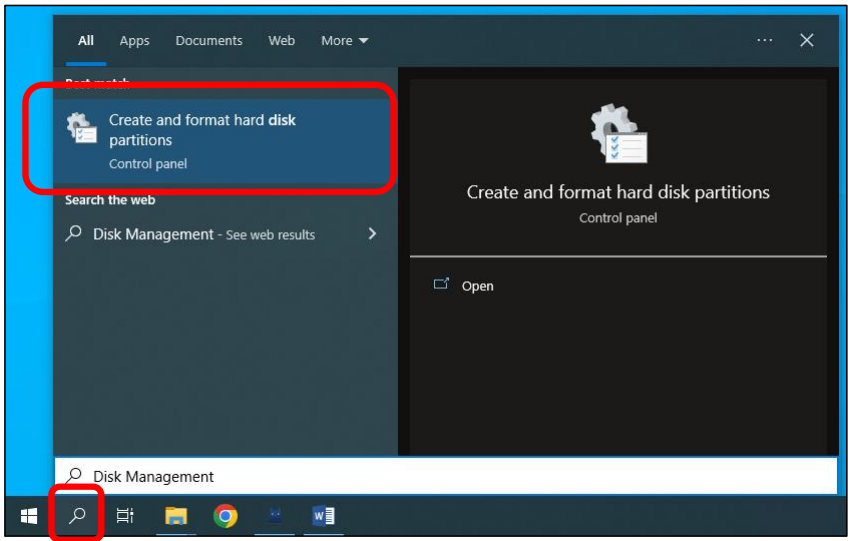
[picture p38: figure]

█ www.freenove.com | Chapter 4 SD Card Read & Write Test | 97

In the newly opened window, locate an unallocated volume with a size close to 1GB.

Click to select the volume, right-click and select “New Simple Volume”.

Click Next.

98 | Chapter 4 SD Card Read & Write Test | www.freenove.com █

On the right-hand side, you can select a preferred drive letter for the SD card or simply proceed with the default setting by clicking on the “Next” button.

When formatting the SD card, select the file system as FAT (or FAT32) and set the allocation unit size to 16K. You can set the volume label to any name of your choice. Once you have made these selections, click on the “Next” button to proceed.

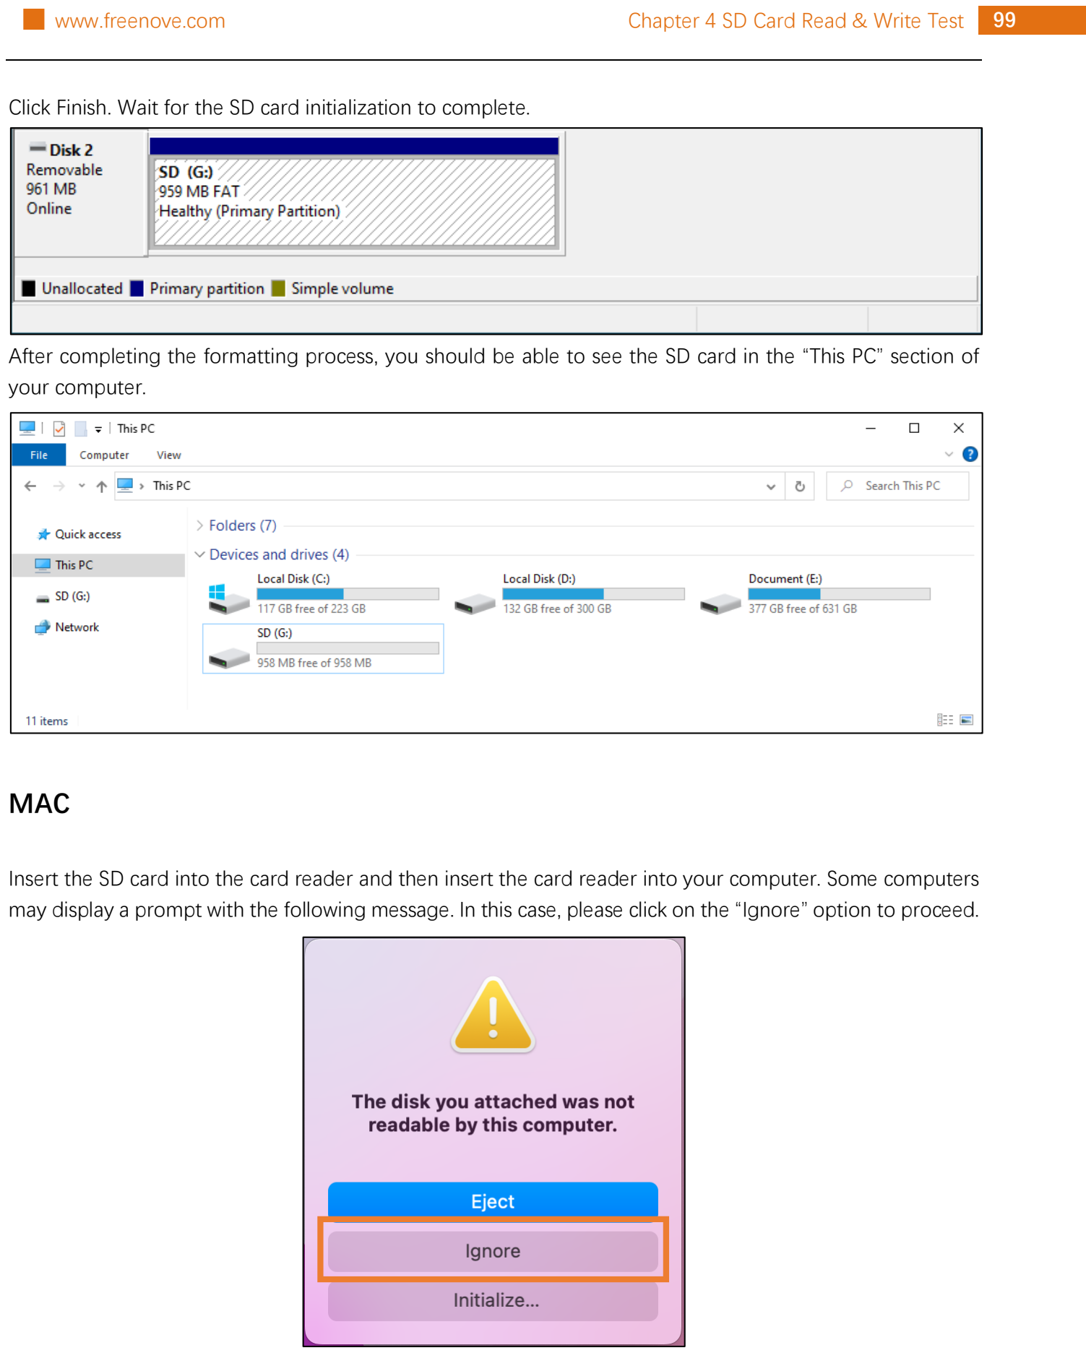
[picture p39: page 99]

█ www.freenove.com | Chapter 4 SD Card Read & Write Test | 99

Click Finish. Wait for the SD card initialization to complete.

After completing the formatting process, you should be able to see the SD card in the “This PC” section of your computer.

## MAC

Insert the SD card into the card reader and then insert the card reader into your computer. Some computers may display a prompt with the following message. In this case, please click on the “Ignore” option to proceed.

100 | Chapter 4 SD Card Read & Write Test | www.freenove.com █

Find “Disk Utility” in the MAC system and click to open it.

Select “Generic MassStorageClass Media”, note that its size is about 1G. It is important to select the correct item to avoid accidentally erasing other device. Once you have verified that you have selected the correct device, click on the “Erase” button to proceed with erasing the SD card.

Select the configuration as shown in the figure below, and then click “Erase”.

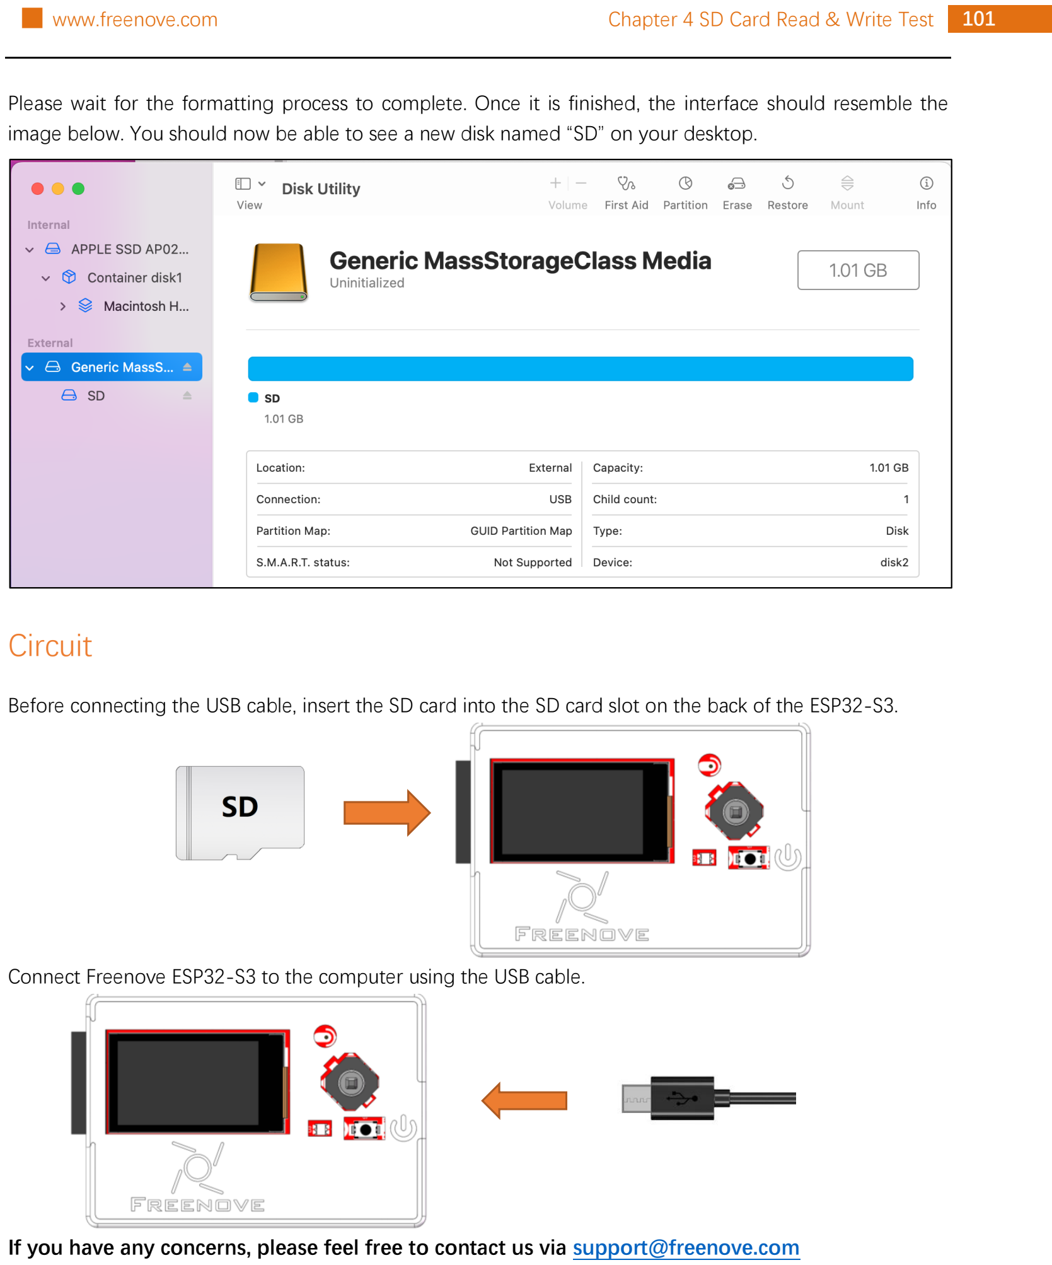
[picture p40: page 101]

█ www.freenove.com | Chapter 4 SD Card Read & Write Test | 101

Please wait for the formatting process to complete. Once it is finished, the interface should resemble the image below. You should now be able to see a new disk named “SD” on your desktop.

## Circuit

Before connecting the USB cable, insert the SD card into the SD card slot on the back of the ESP32-S3.

Connect Freenove ESP32-S3 to the computer using the USB cable.

If you have any concerns, please feel free to contact us via support@freenove.com

102 | Chapter 4 SD Card Read & Write Test | www.freenove.com █

## Sketch

| The following is the program code:
| 1
| 2
3 | #define SD_MMC_CMD 38 // Please do not modify it.
4 | #define SD_MMC_CLK 39 // Please do not modify it.
5 | #define SD_MMC_D0 40 // Please do not modify it.
6
7 | void setup() {
8 | // Initialize serial communication at 115200 bits per second
9 | Serial.begin(115200);
10 | // Initialize the SDMMC interface with the specified pins
11 | sdmmc_init(SD_MMC_CLK, SD_MMC_CMD, SD_MMC_D0);
12
13 | // List files in the root directory and print them
14 | std::list<File_Entry> fileList = list_dir(“/”, 0);
15 | print_file_list(fileList);
16
17 | // Create a new directory and list files again
18 | create_dir(“/mydir”);
19 | fileList = list_dir(“/”, 0);
20 | print_file_list(fileList);
21
22 | // Remove the directory and list files again
23 | remove_dir(“/mydir”);
24 | fileList = list_dir(“/”, 2);
25 | print_file_list(fileList);
26
27 | // Write text to a new file
28 | const char* text = “Hello “;
29 | write_file(“/foo.txt”, (const uint8_t*)text, strlen(text));
30
31 | // Append text to the existing file
32 | text = “World!\n”;
33 | append_file(“/foo.txt”, (const uint8_t*)text, strlen(text));
34
35 | // Read the file content into a buffer and print it
36 | uint8_t buffer[100];
37 | read_file(“/foo.txt”, buffer, sizeof(buffer));
38 | Serial.write(buffer, strlen((char*)buffer));
39
40

#include “driver_sdmmc.h”

// Rename the file and read the new file content

█ www.freenove.com | Chapter 4 SD Card Read & Write Test | 103

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
rename_file(“/foo.txt”, “/hello.txt”); read_file(“/hello.txt”, buffer, sizeof(buffer)); Serial.write(buffer, strlen((char*)buffer));

// Print SD card information
Serial.println(“\r\nSD card info:”);
Serial.printf(“Total space: %lluMB\r\n”, SD_MMC.totalBytes() / (1024 * 1024)); Serial.printf(“Used space: %lluMB\r\n”, SD_MMC.usedBytes() / (1024 * 1024)); }

void loop() {
delay(10000);
}
Add the SD card drive header file.
1 #include “driver_sdmmc.h”
The drive pins of the SD card are pre-defined and should not be modified as they are fixed. Altering the pins may result in errors or malfunctions while accessing the SD card.
3
4
5

#define SD_MMC_CMD 38 // Please do not modify it.

#define SD_MMC_CLK 39 // Please do not modify it.

#define SD_MMC_D0 40 // Please do not modify it.

Initialize the serial port function. Sets the drive pin for SDMMC one-bit bus mode. 9
11

Serial.begin(115200);
sdmmc_init(SD_MMC_CLK, SD_MMC_CMD, SD_MMC_D0);
Call the listDir() function to read the folder and file names in the SD card, and print them out through the serial port. This function can be found in “ driver_sdmmc.cpp”.
14 list_dir(“/”, 0);
Call create_dir () to create a folder, and call remove_dir () to delete a folder.
18
23

create_dir(“/mydir”);
remove_dir(“/mydir”);
Call write_file () to write any content to the txt file. If there is no such file, create this file first. Call append_file () to append any content to txt.
Call read_file () to read the content in txt and print it via the serial port.
29
33
37

write_file(“/foo.txt”, (const uint8_t*)text, strlen(text)); append_file(“/foo.txt”, (const uint8_t*)text, strlen(text)); read_file(“/foo.txt”, buffer, sizeof(buffer));
Call renameFile() to copy a file and rename it.
41 rename_file(“/foo.txt”, “/hello.txt”);
Print the total size and used size of the SD card via the serial port.
50
51

Serial.printf(“Total space: %lluMB\r\n”, SD_MMC.totalBytes() / (1024 * 1024)); Serial.printf(“Used space: %lluMB\r\n”, SD_MMC.usedBytes() / (1024 * 1024)); If you are interesting in the implementation of functions, you can check them out here.

104 | Chapter 5 Simple Tone Test | www.freenove.com █

# Chapter 5 Simple Tone Test

This chapter will explain how to use the ESP_I2S library to implement I2S audio output and achieve looped playback of a sequence of musical notes.

## Project 5.1 Simple Tone

I2S (Inter-IC Sound) is a standardized synchronous serial interface dedicated to digital audio data transfer. Since the microcontroller on the board includes built-in I2S support, we will leverage this capability to produce simple tones.

## Component List

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

Extension Board x1（1.14 inch/3.5 inch）

or

█ www.freenove.com | Chapter 5 Simple Tone Test | 105

## Circuit Knowledge

I2S
I2S achieves high-efficiency data transmission through three signal lines:
- SCK (Serial Clock): Provides synchronization timing, with each bit of audio data corresponding to one SCK pulse.
- WS (Word Select): Distinguishes between left and right audio channels. A high WS level indicates left-channel data transmission, while a low WS level represents right-channel transmission.
- SD (Serial Data): Carries the actual audio data. The Most Significant Bit (MSB) is transmitted first and always appears at the second SCK pulse after a frame begins (following a WS transition).
The I2S protocol is widely used in audio devices such as DACs, ADCs, and digital microphones, offering low latency and high-fidelity performance.

## Circuit

Connect Freenove Media Kit for ESP32-S3 to your computer using the USB cable.

106 | Chapter 5 Simple Tone Test | www.freenove.com █

## Sketch

| Sketch_05_Simple_Tone The following is the program code:
| 1
| 2
3 | #define I2S_BCLK 42
4 | #define I2S_DOUT 1
5 | #define I2S_LRC 41
6
7 | // Define note frequencies in Hz for “Do Re Mi Fa So La Ti”
8 | const int frequencies[] = { 261, 293, 329, 349, 392, 440, 493 };
9 | const int amplitude = 500; // Amplitude of the square wave, controls volume
10 | const int sampleRate = 8000; // Sampling rate, number of samples per second in Hz
11
12 | // I2S configuration parameters
13 | i2s_data_bit_width_t bps = I2S_DATA_BIT_WIDTH_16BIT; // 16 bits per sample
14 | i2s_mode_t mode = I2S_MODE_STD; // Use standard I2S mode
15 | i2s_slot_mode_t slot = I2S_SLOT_MODE_STEREO; // Use stereo mode (left and right
16 | channels)
17
18 | int currentNote = 0; // Index of the current note being played, starts at 0 (Do)
19 | int halfWavelength; // Half wavelength of the square wave, controls the flipping point
20
21 | int32_t sample = amplitude; // Current sample value, initialized to amplitude
22 | int count = 0; // Sample counter, tracks progress of the current note
23
24
25
26 | void setup() {
27 | Serial.begin(115200); // Initialize serial communication at 115200 baud rate
28 | Serial.println(“I2S simple tone”); // Print debug message
29 | i2s.setPins(I2S_BCLK, I2S_LRC, I2S_DOUT); // Set I2S pins (BCLK, LRCK, DATA)
30
31 | // Initialize I2S
32 | if (!i2s.begin(mode, sampleRate, bps, slot)) {
33 | Serial.println(“Failed to initialize I2S!”); // Print error message if initialization
34 | fails
35 | while (1)
36 | ; // Stop program execution
37 | }
38 | // // Calculate initial half wavelength for generating the square wave
39 | halfWavelength = (sampleRate / frequencies[currentNote]);

#include <ESP_I2S.h> // Include ESP_I2S library for I2S audio output

I2SClass i2s; // Create I2S object for controlling I2S output

█ www.freenove.com | Chapter 5 Simple Tone Test | 107

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
while(currentNote < 7)
{
if (count % halfWavelength == 0) { sample = -1 * sample;
}

// Write the current sample value to I2S, output to right and left channels i2s.write(sample); // Right channel
i2s.write(sample); // Left channel

// Increment the sample counter
count++;

// If the current note finishes playing (1 second), switch to the next note
if (count >= sampleRate) { // sampleRate represents the number of samples in 1 second
count = 0; | // Reset the sample counter
currentNote++; | // Switch to the next note

// Update the half wavelength to match the new note frequency if(currentNote < 7)
halfWavelength = (sampleRate / frequencies[currentNote]); }
}
}
void loop() {
// If the sample counter reaches half wavelength, flip the sample value to generate a square wave
delay(1000);
}
Include the header file for the I2S library.
1 #include <ESP_I2S.h> // Include ESP_I2S library for I2S audio output Set the frequency, volume and sampling rate of the sound.
7
8
9
10

// Define note frequencies in Hz for “Do Re Mi Fa So La Ti”
const int frequencies[] = { 261, 293, 329, 349, 392, 440, 493 };
const int amplitude = 500; // Amplitude of the square wave, controls volume const int sampleRate = 8000; // Sampling rate, number of samples per second in Hz Configure I2S parameters.
12
13
14
15

// I2S configuration parameters
i2s_data_bit_width_t bps = I2S_DATA_BIT_WIDTH_16BIT; // 16 bits per sample
i2s_mode_t mode = I2S_MODE_STD; | // Use standard I2S mode
i2s_slot_mode_t slot = I2S_SLOT_MODE_STEREO; | // Use stereo mode (left and right channels)
Set I2S pins.
30 i2s.setPins(I2S_BCLK, I2S_LRC, I2S_DOUT); // Set I2S pins (BCLK, LRCK, DATA)

108 | Chapter 5 Simple Tone Test | www.freenove.com █

The I2S initialization function.
33 i2s.begin(mode, sampleRate, bps, slot)
Output left and right channel audio samples through I2S interface 50
51
52
| // Write the current sample value to I2S, output to right and left channels
| i2s.write(sample); // Right channel
| i2s.write(sample); // Left channel
Calculate the half wavelength corresponding to the frequency based on the frequency and sampling rate of the current note,
63 halfWavelength = (sampleRate / frequencies[currentNote]);
Click the Upload button to upload the sketch.

Once the code is uploaded, the speaker will play the Do-Re-Mi-Fa-Sol-La-Si-Do scale sequence Reference

I2SClass:setPins(int8_t bclk, int8_t ws, int8_t dout, int8_t din = -1, int8_t mclk = -1); This function configures the I2S interface pins
Parameters:
bclk: Bit clock pin
ws: Word select (channel selection) pin dout: Data output pin
din: Data input pin (optional)
mclk: Master clock pin (optional)
I2SClass:begin(i2s_mode_t mode, uint32_t rate, i2s_data_bit_width_t bits_cfg, i2s_slot_mode_t ch, int8_t slot_mask = -1);
I2SThis function initialize I2S.
Paramters：
Mode: I2S working mode
Rate: sampling rate
bits_cfg: data bit width
I2S_DATA_BIT_WIDTH_8BIT = 8, | /*!< I2S channel data bit-width: 8 */
I2S_DATA_BIT_WIDTH_16BIT = 16, | /*!< I2S channel data bit-width: 16 */
I2S_DATA_BIT_WIDTH_24BIT = 24, | /*!< I2S channel data bit-width: 24 */
I2S_DATA_BIT_WIDTH_32BIT = 32, | /*!< I2S channel data bit-width: 32 */
Ch: channel modes
I2S_SLOT_MODE_MONO = 1,
I2S_SLOT_MODE_STEREO = 2,
slot_mask：slot mask (optional）

█ www.freenove.com | Chapter 6 Play MP3 Test | 109

# Chapter 6 Play MP3 Test

In the previous study, we have learned how to use the SD card. Now we are going to learn to play the music in the SD card.

## Project 6.1 Play MP3

## Component List

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

Extension Board x1（1.14 inch/3.5 inch）

or

SD card x1 | Card reader x1 (random color)

## Circuit

110 | Chapter 6 Play MP3 Test | www.freenove.com █

Before compling code, we should copy music to SD card first, as illustrated below. We have placed a folder called “music” in: Freenove_Media_Kit_for_ESP32-S3\Sketch\Sketch_06_Play_MP3,
please copy this folder to the SD card.

Before connecting the USB cable, insert the SD card into the SD card slot on the back of the ESP32-S3.

## Sketch

How to install the library
In this project, we will use the ESP32-audioI2S.zip library to decode the audio files in the SD card, and then output the audio signal through IIS. If you have not installed this library, please follow the steps below to install it.
Open Arduino IDE->Sketch->Include library-> Add .ZIP Library.

█ www.freenove.com | Chapter 6 Play MP3 Test | 111

In the newly opened window, select “ Freenove_Media_Kit_for_ESP32-S3\Libraries\ESP32-audioI2S.zip”
and click “Open”.

If you have any concerns, please feel free to contact us via support@freenove.com Sketch_06_Play_MP3
The following is the program code:
1 | #include “Arduino.h”
2 | #include “Audio.h”
3 | #include “FS.h”
4 | #include “SD_MMC.h”
5
6 | #define SD_MMC_CMD 38 // Command pin for SDMMC
7 | #define SD_MMC_CLK 39 // Clock pin for SDMMC
8 | #define SD_MMC_D0 40 // Data pin for SDMMC
9
10 | #define I2S_BCLK 42 // Bit clock pin for I2S
11 | #define I2S_DOUT 1 // Data out pin for I2S
12 | #define I2S_LRC 41 // Left/Right clock pin for I2S
13
14
15
16 | void setup() {
17 | Serial.begin(115200);
18
19 | SD_MMC.setPins(SD_MMC_CLK, SD_MMC_CMD, SD_MMC_D0);
20 | if (!SD_MMC.begin(“/sdcard”, true, true, SDMMC_FREQ_DEFAULT, 5)) {
21 | Serial.println(“Card Mount Failed”);
22 | return;
23 | }
24 | uint8_t cardType = SD_MMC.cardType();
25 | if (cardType == CARD_NONE) {
26 | Serial.println(“No SD_MMC card attached”);
27 | return;
28 | }
29 | if (cardType == CARD_MMC) {
30 | Serial.println(“MMC”);
31 | } else if (cardType == CARD_SD) {
32 | Serial.println(“SDSC”);

Audio audio;

112 | Chapter 6 Play MP3 Test | www.freenove.com █
33 | } else if (cardType == CARD_SDHC) {
34 | Serial.println(“SDHC”);
35 | } else {
36 | Serial.println(“UNKNOWN”);
37 | }
38 | uint64_t cardSize = SD_MMC.cardSize() / (1024 * 1024);
39 | Serial.printf(“SD_MMC Card Size: %lluMB\n”, cardSize);
40
41 | audio.setPinout(I2S_BCLK, I2S_LRC, I2S_DOUT);
42 | audio.setVolume(2); // 0...21
43
44 | audio.connecttoFS(SD_MMC, “/music/Jingle Bells.mp3”);
45 | }
46
47 | void loop() {
48 | audio.loop();
49 | if (Serial.available()) { // put streamURL in serial monitor
50 | audio.stopSong();
51 | String r = Serial.readString();
52 | r.trim();
53 | if (r.length() > 5) audio.connecttoFS(SD_MMC, r.c_str());
54 | log_i(“free heap=%i”, ESP.getFreeHeap());
55 | }
56 | }
57
58 | // optional
59 | void audio_info(const char *info) {
60 | Serial.print(“info “);
61 | Serial.println(info);
62 | }
63 | void audio_id3data(const char *info) { //id3 metadata
64 | Serial.print(“id3data “);
65 | Serial.println(info);
66 | }
67 | void audio_eof_mp3(const char *info) { //end of file
68 | Serial.print(“eof_mp3 “);
69 | Serial.println(info);
70 | }
71 | void audio_showstation(const char *info) {
72 | Serial.print(“station “);
73 | Serial.println(info);
74 | }
75 | void audio_showstreamtitle(const char *info) {
76 | Serial.print(“streamtitle “);

█ www.freenove.com | Chapter 6 Play MP3 Test | 113

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
Serial.println(info);
}
void audio_bitrate(const char *info) { Serial.print(“bitrate “);
Serial.println(info);
}
void audio_commercial(const char *info) { //duration in sec Serial.print(“commercial “);
Serial.println(info);
}
void audio_icyurl(const char *info) { //homepage
Serial.print(“icyurl | “);
Serial.println(info);
}
void audio_lasthost(const char *info) { //stream URL played Serial.print(“lasthost “);
Serial.println(info);
}
Include the required header files.
1
2
3
4

#include “Arduino.h”

#include “Audio.h”

#include “FS.h”

#include “SD_MMC.h”

Macro definitions for SD Card pin configuration 6
7
8

#define SD_MMC_CMD 38 // Command pin for SDMMC #define SD_MMC_CLK 39 // Clock pin for SDMMC #define SD_MMC_D0 40 // Data pin for SDMMC Macro definitions for I2S pin configuration

10
11
12
#define I2S_BCLK | 42 // Bit clock pin for I2S

#define I2S_DOUT | 1 | // Data out pin for I2S

#define I2S_LRC | 41 // Left/Right clock pin for I2S

SD card initialization
19
20
21
22
23

SD_MMC.setPins(SD_MMC_CLK, SD_MMC_CMD, SD_MMC_D0);
if (!SD_MMC.begin(“/sdcard”, true, true, SDMMC_FREQ_DEFAULT, 5)) { Serial.println(“Card Mount Failed”);
return;
}
Declare an audio decoding object, associate it with the pin, set the volume, and set the decoding object. 14

41
42
43
44

Audio audio;
…
audio.setPinout(I2S_BCLK, I2S_LRC, I2S_DOUT); audio.setVolume(2); // 0...21

audio.connecttoFS(SD_MMC, “/music/Jingle Bells.mp3”);

114 | Chapter 6 Play MP3 Test | www.freenove.com █

Continuously play music until the current track finishes. Upon receiving data through the serial port, remove any leading or trailing spaces and use the audio object to decode the data.
45 | audio.loop();
46 | if (Serial.available()) { // put streamURL in serial monitor
47 | audio.stopSong();
48 | String r = Serial.readString();
49 | r.trim();
50 | if (r.length() > 5) audio.connecttoFS(SD_MMC, r.c_str());
51 | log_i(“free heap=%i”, ESP.getFreeHeap());
52 | }
It is necessary to change the settings in Arduino IDE before clicking the Uploading button, as shown below. Caution: Incorrect settings will result in compilation error or uploading failure. To achieve desired result, please configure exactly the same as below.

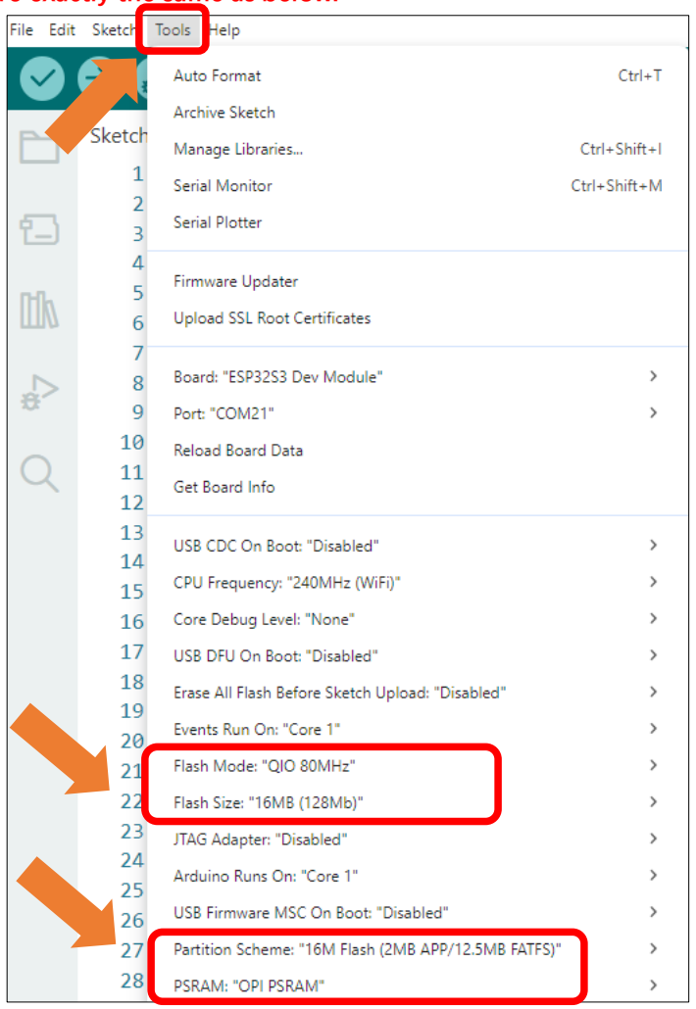
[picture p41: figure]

█ www.freenove.com | Chapter 6 Play MP3 Test | 115

If you want to switch the music in the SD card, you can directly input the song through the serial port.

To adjust the volume, you can modify the parameter in the code, as shown below. The range of the volume is between 0 to 21.

These functions are used to print information about audio decoding. If you don't want to see this information in the serial port, you can simply comment out these functions.”
59 | void audio_info(const char *info);
63 | void audio_id3data(const char *info);
67 | void audio_eof_mp3(const char *info);
71 | void audio_showstation(const char *info);
75 | void audio_showstreamtitle(const char *info);
79 | void audio_bitrate(const char *info);
83 | void audio_commercial(const char *info);
87 | void audio_icyurl(const char *info);
91 | void audio_lasthost(const char *info);

116 | Chapter 7 Video Web Server | www.freenove.com █

# Chapter 7 Video Web Server

In this section, we take ESP32-S3's video function as an example to study.

## Project 7.1 Camera Web Server

Connect the ESP32-S3 to your computer with the USB cable. Check its IP address through the serial monitor upon the code upload completes. Access the IP address via a browser to view the video and image data.

## Component List

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

Extension Board x1（1.14 inch/3.5 inch）

or

█ www.freenove.com | Chapter 7 Video Web Server | 117

## Circuit

Before connecting the USB cable, insert the SD card into the SD card slot on the back of the ESP32-S3.

## Sketch

Sketch_07_Video_Web_Server The following is the program code:
1 | #include "esp_camera.h"
2 | #include <WiFi.h>
3 | #include "driver_sdmmc.h"
4
5 | // Select camera model
6 | #define CAMERA_MODEL_ESP32S3_EYE // Has PSRAM
7 | #include "camera_pins.h"
8
9 | const char* ssid = "********"; // Input your Wi-Fi name
10 | const char* password = "********"; // Input your Wi-Fi password
11
12 | #define SD_MMC_CMD 38 // Please do not modify it.
13 | #define SD_MMC_CLK 39 // Please do not modify it.
14 | #define SD_MMC_D0 40 // Please do not modify it.
15
16 | void camera_init(void);
17 | void startCameraServer();
18
19 | void setup() {
20 | Serial.begin(115200);
21 | while (!Serial);
22 | Serial.setDebugOutput(true);
23 | Serial.println();
24
25 | // Initialize the camera
26 | camera_init();
27 | // Initialize the SDMMC interface for SD card operations

118 | Chapter 7 Video Web Server | www.freenove.com █
28 | sdmmc_init(SD_MMC_CLK, SD_MMC_CMD, SD_MMC_D0);
29 | // Remove and create a new directory for video storage
30 | remove_dir("/video");
31 | create_dir("/video");
32
33 | // Connect to Wi-Fi network
34 | WiFi.begin(ssid, password);
35
36 | // Wait for Wi-Fi connection
37 | while (WiFi.status() != WL_CONNECTED) {
38 | delay(500);
39 | Serial.print(".");
40 | }
41 | Serial.println("");
42 | Serial.println("WiFi connected");
43
44 | // Start the camera web server
45 | startCameraServer();
46
47 | // Print the IP address to connect to the web server
48 | Serial.print("Camera Ready! Use 'http://");
49 | Serial.print(WiFi.localIP());
50 | Serial.println("' to connect");
51 | }
52
53 | void loop() {
54 | // Main loop code, can be used for additional tasks
55 | delay(10000);
56 | }
57
58 | void camera_init(void) {
59 | camera_config_t config;
60 | config.ledc_channel = LEDC_CHANNEL_0;
61 | config.ledc_timer = LEDC_TIMER_0;
62 | config.pin_d0 = Y2_GPIO_NUM;
63 | config.pin_d1 = Y3_GPIO_NUM;
64 | config.pin_d2 = Y4_GPIO_NUM;
65 | config.pin_d3 = Y5_GPIO_NUM;
66 | config.pin_d4 = Y6_GPIO_NUM;
67 | config.pin_d5 = Y7_GPIO_NUM;
68 | config.pin_d6 = Y8_GPIO_NUM;
69 | config.pin_d7 = Y9_GPIO_NUM;
70 | config.pin_xclk = XCLK_GPIO_NUM;
71 | config.pin_pclk = PCLK_GPIO_NUM;

█ www.freenove.com | Chapter 7 Video Web Server | 119
72 | config.pin_vsync = VSYNC_GPIO_NUM;
73 | config.pin_href = HREF_GPIO_NUM;
74 | config.pin_sccb_sda = SIOD_GPIO_NUM;
75 | config.pin_sccb_scl = SIOC_GPIO_NUM;
76 | config.pin_pwdn = PWDN_GPIO_NUM;
77 | config.pin_reset = RESET_GPIO_NUM;
78 | config.xclk_freq_hz = 10000000;
79 | config.frame_size = FRAMESIZE_QVGA;
80 | config.pixel_format = PIXFORMAT_JPEG; // for streaming
81 | config.grab_mode = CAMERA_GRAB_WHEN_EMPTY;
82 | config.fb_location = CAMERA_FB_IN_PSRAM;
83 | config.jpeg_quality = 10;
84 | config.fb_count = 1;
85
86 | // Initialize the camera with the specified configuration
87 | esp_err_t err = esp_camera_init(&config);
88 | if (err != ESP_OK) {
89 | if (err == ESP_ERR_NOT_SUPPORTED) {
90 | config.pixel_format = PIXFORMAT_RGB565;
91 | esp_err_t err = esp_camera_init(&config);
92 | if (err != ESP_OK) {
93 | Serial.printf("Camera init failed with error 0x%x", err);
94 | return;
95 | }
96 | }
97 | }
98 | sensor_t* s = esp_camera_sensor_get();
99 | uint16_t pid = s->id.PID;
100 | if (pid == OV2640_PID) {
101 | s->set_hmirror(s, 0);
102 | s->set_vflip(s, 0);
103 | } else if (pid == OV3660_PID) {
104 | s->set_hmirror(s, 0);
105 | s->set_vflip(s, 1);
106 | } else if (pid == GC2145_PID) {
107 | s->set_hmirror(s, 1);
108 | delay(500);
109 | s->set_vflip(s, 1);
110 | } else if (pid == GC0308_PID) {
111 | s->set_hmirror(s, 0);
112 | delay(500);
113 | s->set_vflip(s, 0);
114 | } else {
115 | s->set_hmirror(s, 0);

120 | Chapter 7 Video Web Server | www.freenove.com █

116
117
118
119
120
121

s->set_vflip(s, 1);
}
s->set_brightness(s, 1); // Slightly increase brightness s->set_saturation(s, 0); // Reduce saturation s->set_ae_level(s, -3); // Set exposure compensation level }
Add procedure files and API interface files related to ESP32-S3 camera. 1
2
3
4
5
6
7

#include "esp_camera.h"

#include <WiFi.h>

#include "driver_sdmmc.h"

// Select camera model
#define CAMERA_MODEL_ESP32S3_EYE // Has PSRAM #include "camera_pins.h"

Enter the name and password of your router.
9
10
const char* ssid = “********”; | // Input your Wi-Fi name
const char* password = “********”; // Input your Wi-Fi password
Initialize serial port, set baud rate to 115200; open the debug and output function of the serial. 20
21
22
23

Serial.begin(115200);
while (!Serial);
Serial.setDebugOutput(true);
Serial.println();
ESP32-S3 connects to the router and prints a successful connection prompt. If it does not connect succssfully, press the reset key on the ESP32-S3 WROOM.
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
// Connect to Wi-Fi network WiFi.begin(ssid, password);

// Wait for Wi-Fi connection
while (WiFi.status() != WL_CONNECTED) { delay(500);
Serial.print(“.”);
}
Serial.println(““);
Serial.println(“WiFi connected”);
Start the camera web server and print its IP address via serial port. 44
45
46
47
48
49
50

// Start the camera web server startCameraServer();

// Print the IP address to connect to the web server Serial.print(“Camera Ready! Use 'http://”); Serial.print(WiFi.localIP());
Serial.println(“' to connect”);

█ www.freenove.com | Chapter 7 Video Web Server | 121

Configure parameters including interface pins of the camera. Note: Changing the pins is not recommended.

camera_config_t config;
config.ledc_channel = LEDC_CHANNEL_0;
config.ledc_timer = LEDC_TIMER_0; config.pin_d0 = Y2_GPIO_NUM; config.pin_d1 = Y3_GPIO_NUM; config.pin_d2 = Y4_GPIO_NUM; config.pin_d3 = Y5_GPIO_NUM; config.pin_d4 = Y6_GPIO_NUM; config.pin_d5 = Y7_GPIO_NUM; config.pin_d6 = Y8_GPIO_NUM; config.pin_d7 = Y9_GPIO_NUM; config.pin_xclk = XCLK_GPIO_NUM; config.pin_pclk = PCLK_GPIO_NUM; config.pin_vsync = VSYNC_GPIO_NUM; config.pin_href = HREF_GPIO_NUM; config.pin_sccb_sda = SIOD_GPIO_NUM; config.pin_sccb_scl = SIOC_GPIO_NUM; config.pin_pwdn = PWDN_GPIO_NUM; config.pin_reset = RESET_GPIO_NUM;
config.xclk_freq_hz = 10000000;
config.frame_size = FRAMESIZE_VGA;
config.pixel_format = PIXFORMAT_RGB565; // for streaming config.grab_mode = CAMERA_GRAB_WHEN_EMPTY; config.fb_location = CAMERA_FB_IN_PSRAM; config.jpeg_quality = 12;
config.fb_count = 1;
Configure the display image information of the camera.
The set_vflip() function sets whether the image is flipped 180°, with 0 for no flip and 1 for flip 180°. The set_brightness() function sets the brightness of the image, with values ranging from -2 to 2. The set_saturation() function sets the color saturation of the image, with values ranging from -2 to 2.

// Get the camera sensor and adjust settings
sensor_t* s = esp_camera_sensor_get();
s->set_vflip(s, 0); | // Flip the image vertically
s->set_brightness(s, 1); // Increase brightness
s->set_saturation(s, 0); // Decrease saturation
Modify the resolution and sharpness of the images captured by the camera. The sharpness ranges from 10 to 63, and the smaller the number, the sharper the picture. The larger the number, the blurrier the picture. Please refer to the table below.

config.frame_size = FRAMESIZE_VGA;
config.jpeg_quality = 10;

122 | Chapter 7 Video Web Server | www.freenove.com █

It is necessary to change the settings in Arduino IDE before clicking the Uploading button, as shown below. Caution: Incorrect settings will result in compilation error or uploading failure. To achieve desired result, please configure exactly the same as below.

After uploading the code, an IP address will be printed in the Serial Monitor. The IP address is automatically assigned by the system (the specific IP address may vary depending on the network environment).

█ www.freenove.com | Chapter 7 Video Web Server | 123

Open the IP address on a browser and you will see the video streaming.

Note: Display performance may differ across camera models, with some devices showing a flipped image. If this occurs, configure the horizontal/vertical mirroring settings.
104
105
s->set_hmirror(s, 1); | // Mirror the image horizontally
s->set_vflip(s, 0); | // Restore vertical orientation
Parameter Description:
- 0: Normal display
- 1: Flip (mirror)
To achieve the desired display, configure the settings according to real-time preview feedback during setup. Reference
Image resolution | Sharpness | Image resolution | Sharpness
FRAMESIZE_96X96 | 96x96 | FRAMESIZE_HVGA | 480x320
FRAMESIZE_QQVGA | 160x120 | FRAMESIZE_VGA | 640x480
FRAMESIZE_QCIF | 176x144 | FRAMESIZE_SVGA | 800x600
FRAMESIZE_HQVGA | 240x176 | FRAMESIZE_XGA | 1024x768
FRAMESIZE_240X240 | 240x240 | FRAMESIZE_HD | 1280x720
FRAMESIZE_QVGA | 320x240 | FRAMESIZE_SXGA | 1280x1024
FRAMESIZE_CIF | 400x296 | FRAMESIZE_UXGA | 1600x1200
We suggest that the resolution of the camera should not exceed 640x480.
If you have any concerns, please feel free to contact us via support@freenove.com

124 | Chapter 8 TFT Clock | www.freenove.com █

# Chapter 8 TFT Clock

In this section, we will learn how to use the TFT display.

## Project 8.1 TFT Clock

## Component List

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

Extension Board x1（1.14 inch/3.5 inch）

or

█ www.freenove.com | Chapter 8 TFT Clock | 125

## Circuit

Connect Freenove Media Kit for ESP32-S3 to your computer using the USB cable.
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

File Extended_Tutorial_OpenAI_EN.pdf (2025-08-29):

█ www.freenove.com | Contents | 1

# Contents

2 | AI Voice Assistant Based on OpenAI Realtime model | www.freenove.com █

# AI Voice Assistant Based on OpenAI Realtime model

This project applies the Media Kit to develop an AI voice assistant for conversations with OpenAI. It requires basic programming skills and some familiarity with OpenAI.

## About the Project

This voice assistant project (https://github.com/Freenove/openai-realtime-embedded) is based on OpenAI's
open-source project | openai-realtime-embedded | (https://github.com/openai/openai-realtime-embedded).
It enables embedded devices to call OpenAI's Realtime Model APIs, such as GPT-4o Realtime and GPT-4o Mini Realtime, allowing you to build your own AI voice assistant.

Freenove has adapted this project for its Media Kit product. This article will guide you on how to run it on the Media Kit.

## Cautions

⚫ | Project Copyright: The original author of this project is OpenAI. Freenove forked and adapted it for Media
| Kit, and the project is licensed under the MIT License.
⚫ | Supported Countries/Regions: This project uses OpenAI’s GPT-4o RealTime API, which is not available
| in all countries/regions. Please check OpenAI’s supported countries list:
| https://platform.openai.com/docs/supported-countries.
| If you cannot access this link, OpenAI’s services are likely unavailable in your location.
⚫ | Supported Languages: OpenAI supports many languages but has no official list. For reference, see:
| https://platform.openai.com/docs/api-reference/realtime-sessions/create
| https://en.wikipedia.org/wiki/List_of_ISO_639_language_codes）
⚫ | Pricing: The GPT-4o RealTime API is a paid service, and you must purchase credits from OpenAI to use
| it.
⚫ | Seeking Help: If you have followed the tutorial but still encounter issues, contact us at
| support@freenove.com
| Note: Since both the project and API are provided by OpenAI, if OpenAI discontinues them, we will also
| remove related documentation, tutorials, and code.

## About OpenAI

OpenAI is a leading artificial intelligence research and deployment company committed to ensuring that artificial general intelligence (AGI) benefits all of humanity. Guided by principles of openness, collaboration, and safety, the organization drives the development and practical application of cutting-edge models. These include the renowned GPT series of language models, the DALL·E image generation model, as well as speech recognition and synthesis tools like Whisper.

█ www.freenove.com | AI Voice Assistant Based on OpenAI Realtime model | 3

OpenAI not only provides powerful AI models but also offers API services that enable developers to easily integrate these models into their own products. Recently, OpenAI launched its new Realtime API, which significantly enhances conversational naturalness through direct streaming of audio input and output, with automatic interruption handling capabilities.

However, it's important to note that:
1. OpenAI currently does not offer free services
2. The Realtime API currently only supports:
GPT-4o and GPT-4o mini models
The latest transcription models: GPT-4o Transcribe and GPT-4o mini Transcribe

For more information about Realtime API, please refer to Realtime API - OpenAI API (https://platform.openai.com/docs/guides/realtime)

## OpenAI-Realtime-Embedded Disclaimer

This implementation is an adaptation of the open-source project available at https://github.com/openai/openai-realtime-embedded, provided for third-party learning and AI functionality testing purposes, without any promotion or support for commercial applications. This tutorial is intended solely for personal learning and development by technology enthusiasts.

Notes:
1. As this is a third-party open-source project, if you encounter issues during your learning process, please submit an issue to the original repository https://github.com/openai/openai-realtime-embedded/issues
2. The OpenAI API is a paid service. You must subscribe and enable billing to access any API functionality. Without an active paid account, all OpenAI API features will be unavailable.
3. To use OpenAI services, you must apply for your own API key directly from OpenAI. We do not provide or share any API key information.
For details about OpenAI API access, please visit: https://platform.openai.com/docs/api-reference/introduction

Please see the following flowchart.
- The ESP32-S3 executes the openai-realtime-embedded source code, establishes a WiFi connection, and streams audio data to OpenAI’s servers.
- Upon receiving the audio stream, OpenAI’s servers process the data, generate text responses, and synthesize corresponding audio, which is then transmitted back to the ESP32-S3 via WiFi.
- In this project, the ESP32-S3 communicates with OpenAI’s servers using the WebSocket protocol.

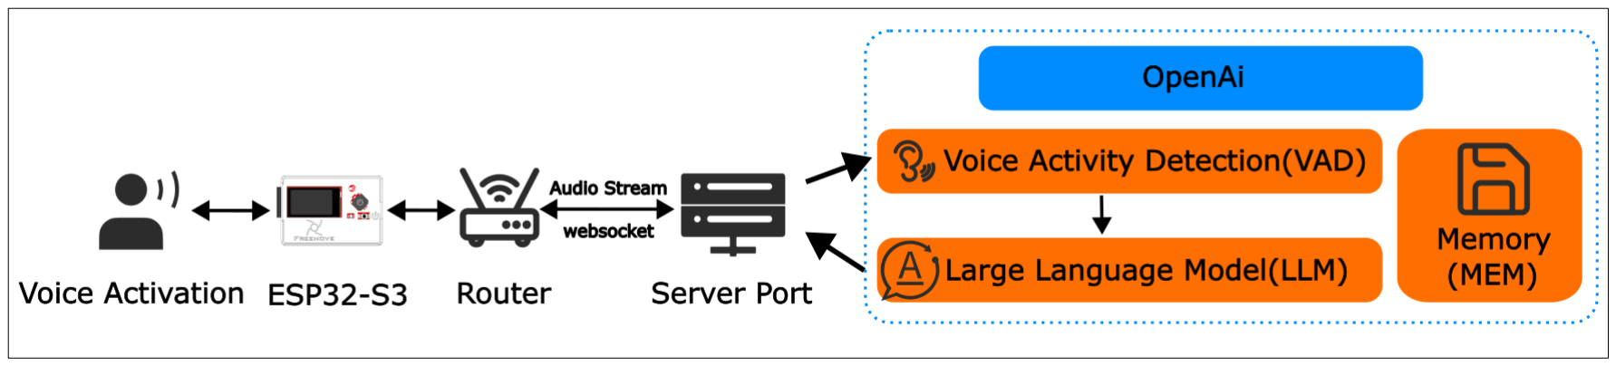
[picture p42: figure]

4 | AI Voice Assistant Based on OpenAI Realtime model | www.freenove.com █

## Freenove Media Kit for ESP32-S3

As of the time of writing, the Freenove Media Kit for ESP32-S3 comes in two different models with varying screen sizes. However, this tutorial applies to both versions.

## 1.14inch

The audio circuit board integrates multiple functional hardware modules, including a 1.14-inch TFT display, a microphone, a battery charging circuit, an audio processing circuit, a headphone jack, and an integrated speaker, as illustrated in the figures below.

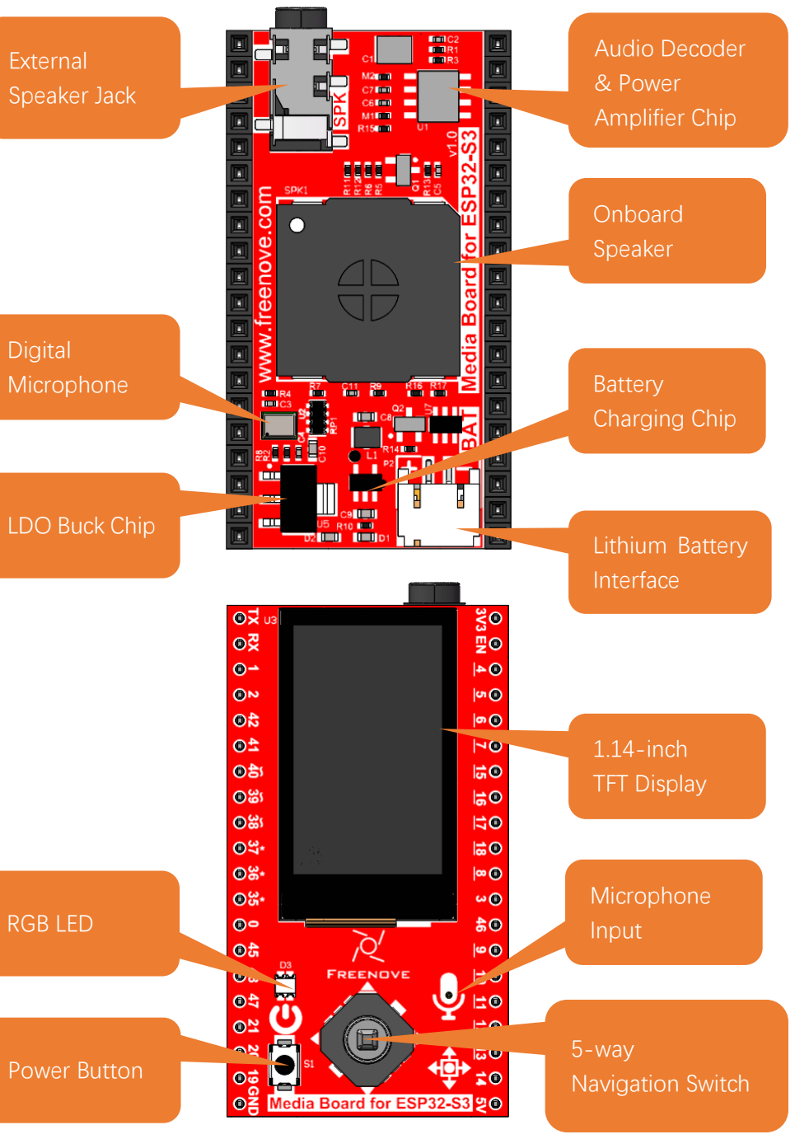
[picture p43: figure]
External Speaker Jack; Audio Decoder & Power Amplifier Chip; Onboard Speaker; Digital; Microphone; Battery; Charging Chip; Lithium Battery Interface; LDO Buck Chip; 1.14-inch TFT Display; Microphone Input; 5-way Navigation Switch; RGB LED; Power Button

## 3.5inch

█ www.freenove.com | AI Voice Assistant Based on OpenAI Realtime model | 5

The audio circuit board integrates multiple functional hardware modules, including a 3.5-inch TFT display, a microphone, a battery charging circuit, an audio processing circuit, a headphone jack, and an speaker jack, as illustrated in the figures below.

WS2812

3.5-inch
TFT display

Power
Button

Left
Microphone

Right
Microphone

5-way
Navigation
Key

Headphone
Jack

Battery
Connector

Buck Circuit

Audio Chip

Charging
Chip

DAC Chip

Speaker
Connector

Button

## Install CH343 Driver (Required)

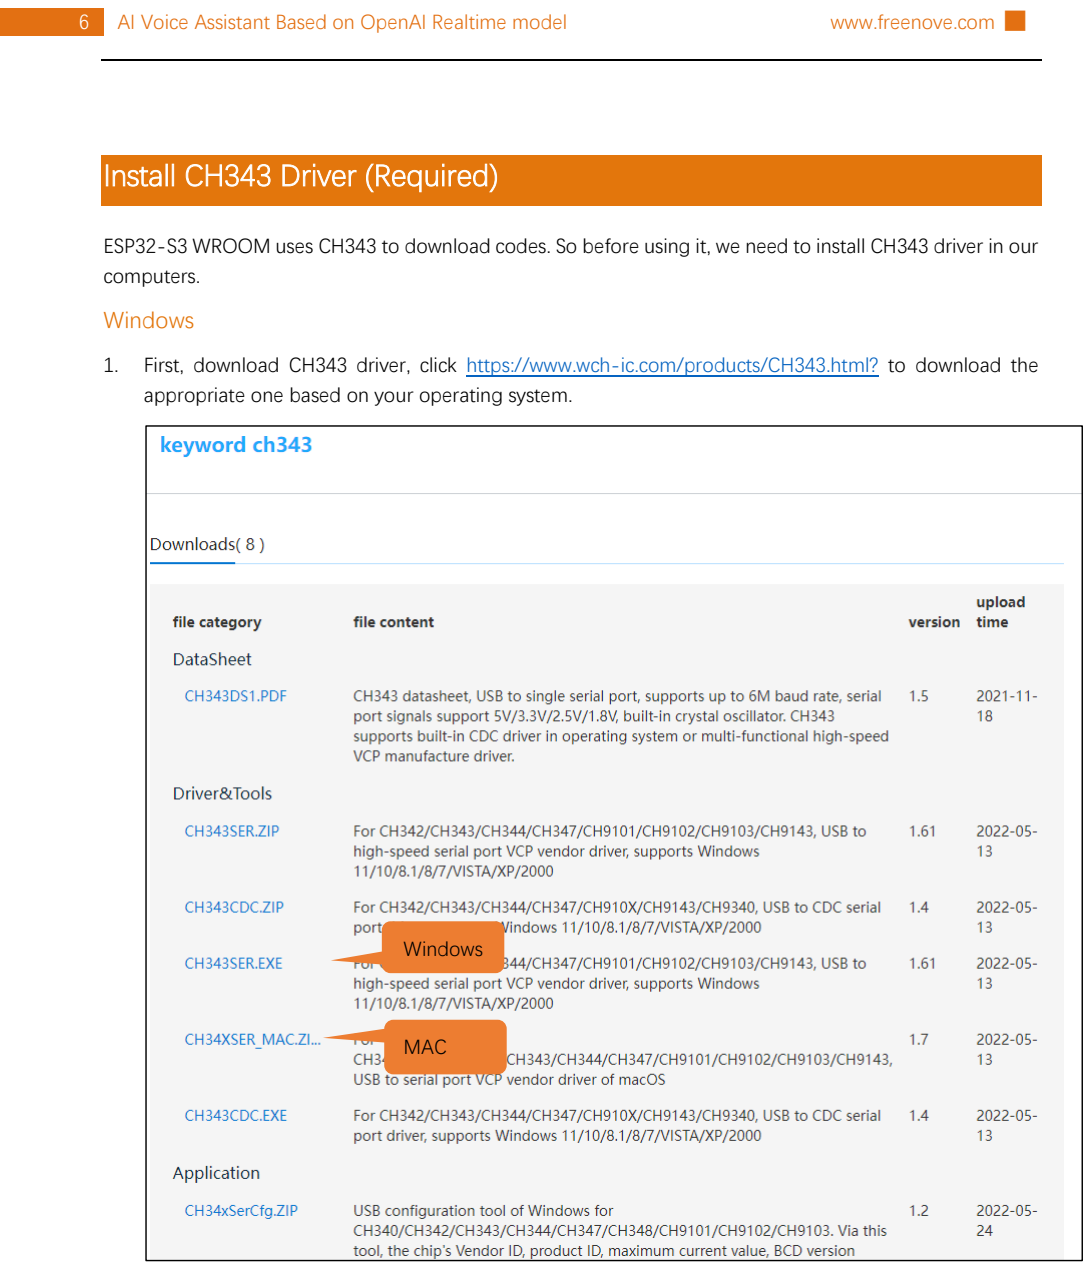
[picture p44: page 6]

6 | AI Voice Assistant Based on OpenAI Realtime model | www.freenove.com █

ESP32-S3 WROOM uses CH343 to download codes. So before using it, we need to install CH343 driver in our computers.

Windows

1. First, download CH343 driver, click https://www.wch-ic.com/products/CH343.html? to download the appropriate one based on your operating system.

Windows

MAC

█ www.freenove.com | AI Voice Assistant Based on OpenAI Realtime model | 7

If you would not like to download the installation package, you can open “Freenove_Media_Kit_for_ESP32-S3/CH343”, we have prepared the installation package.

2. Open the folder “Freenove_Media_Kit_for_ESP32-S3/CH343/Windows/”
3. Double click “CH343SER.EXE”.

8 | AI Voice Assistant Based on OpenAI Realtime model | www.freenove.com █
4. Click “INSTALL” and wait for the installation to complete.
5. If the driver is successfully installed, you should see the following prompt.

Note: If you see “The drive is successfully Pre-installed in advance”, it indicates the installation fails. Please make sure you use the USB data cable, not a charging cable.

█ www.freenove.com | AI Voice Assistant Based on OpenAI Realtime model | 9
6. When ESP32-S3 WROOM is connected to computer, select “This PC”, right-click to select “Manage” and click “Device Manager” in the newly pop-up dialog box, and you can see the following interface.

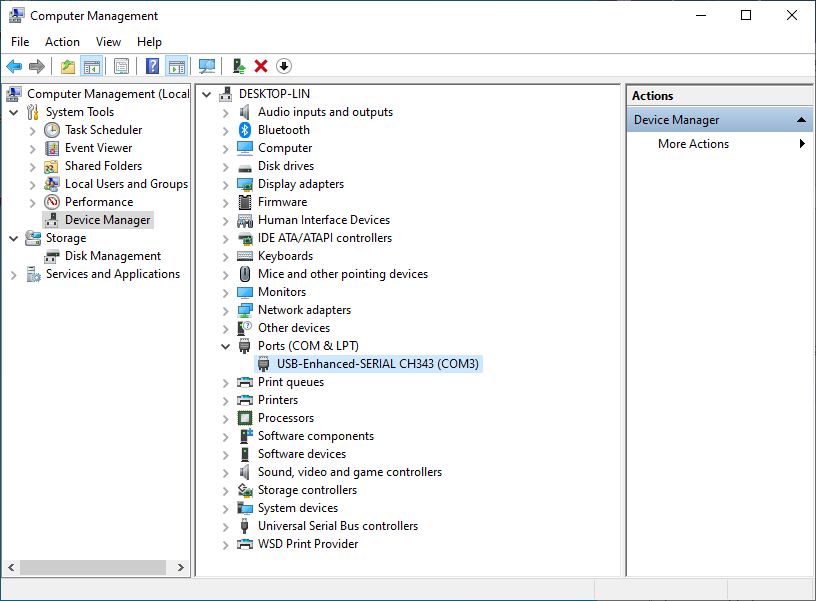
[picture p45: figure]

7. So far, CH343 has been installed successfully. Close all dialog boxes.

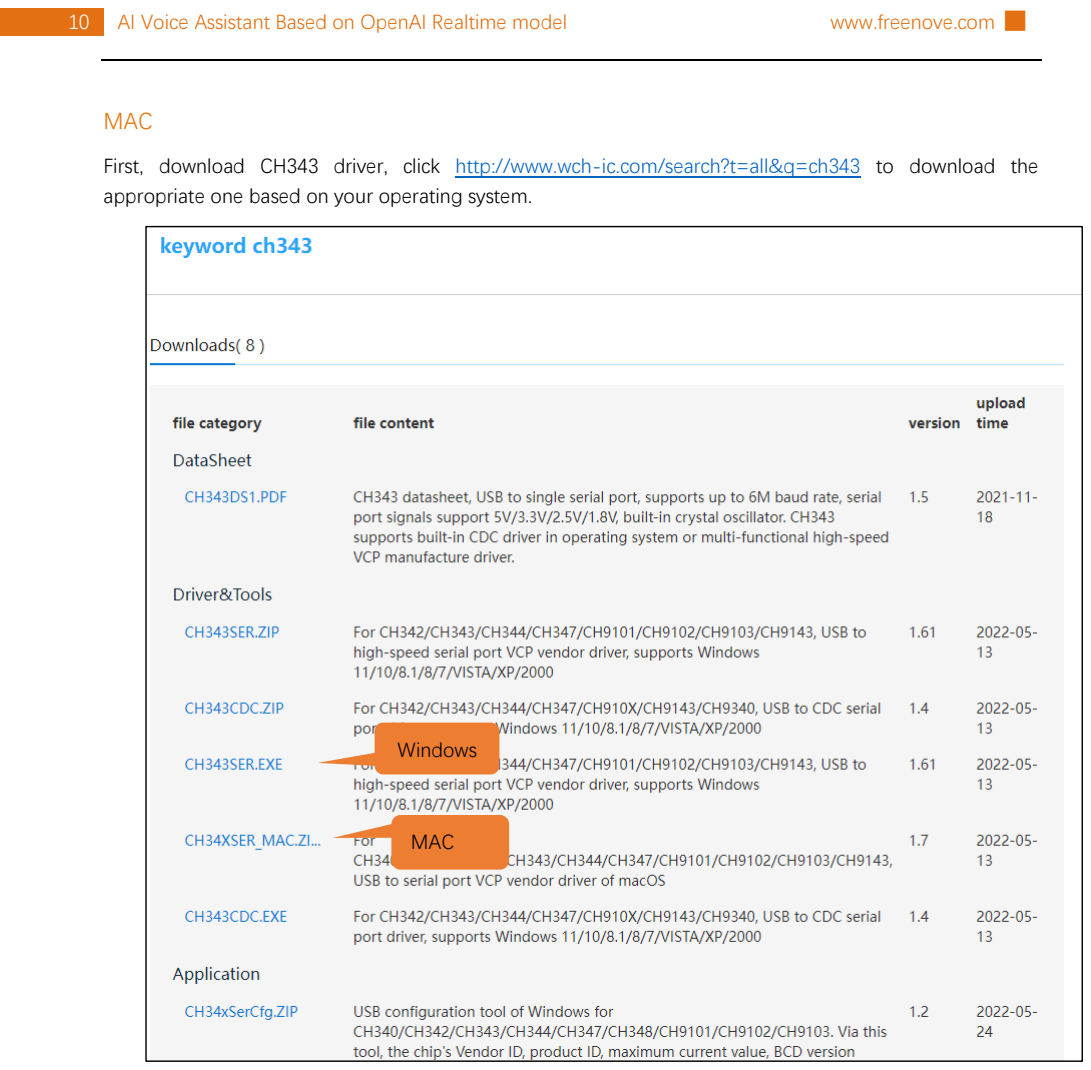
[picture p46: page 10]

10 | AI Voice Assistant Based on OpenAI Realtime model | www.freenove.com █

MAC

First, download CH343 driver, click http://www.wch-ic.com/search?t=all&q=ch343 to download the appropriate one based on your operating system.

Windows

MAC

█ www.freenove.com | AI Voice Assistant Based on OpenAI Realtime model | 11

If you would not like to download the installation package, you can open “Freenove_Media_Kit_for_ESP32-S3/CH343”, we have prepared the installation package.
Second, open the folder “Freenove_Media_Kit_for_ESP32-S3/CH343/MAC/”

Third, click Continue.

Run it.

12 | AI Voice Assistant Based on OpenAI Realtime model | www.freenove.com █

Fourth, click Install.

Then, waiting Finish.

█ www.freenove.com | AI Voice Assistant Based on OpenAI Realtime model | 13

Finally, restart your PC.

If you still haven't installed the CH340 by following the steps above, you can view readme.pdf to install it.

ReadMe

14 | AI Voice Assistant Based on OpenAI Realtime model | www.freenove.com █

Linux

Here we take Ubuntu as an example. Open the terminal in Linux system.

Check the port with the command “lsusb”. lsusb
ls /dev/tty*

Generally, the CH34x driver is included in modern Linux kernels, so it should work automatically when the device is connected
If your computer does not have the CH343 driver, you can follow the steps below to install it. If your computer recognizes the CH343 driver, you may skip the following steps.

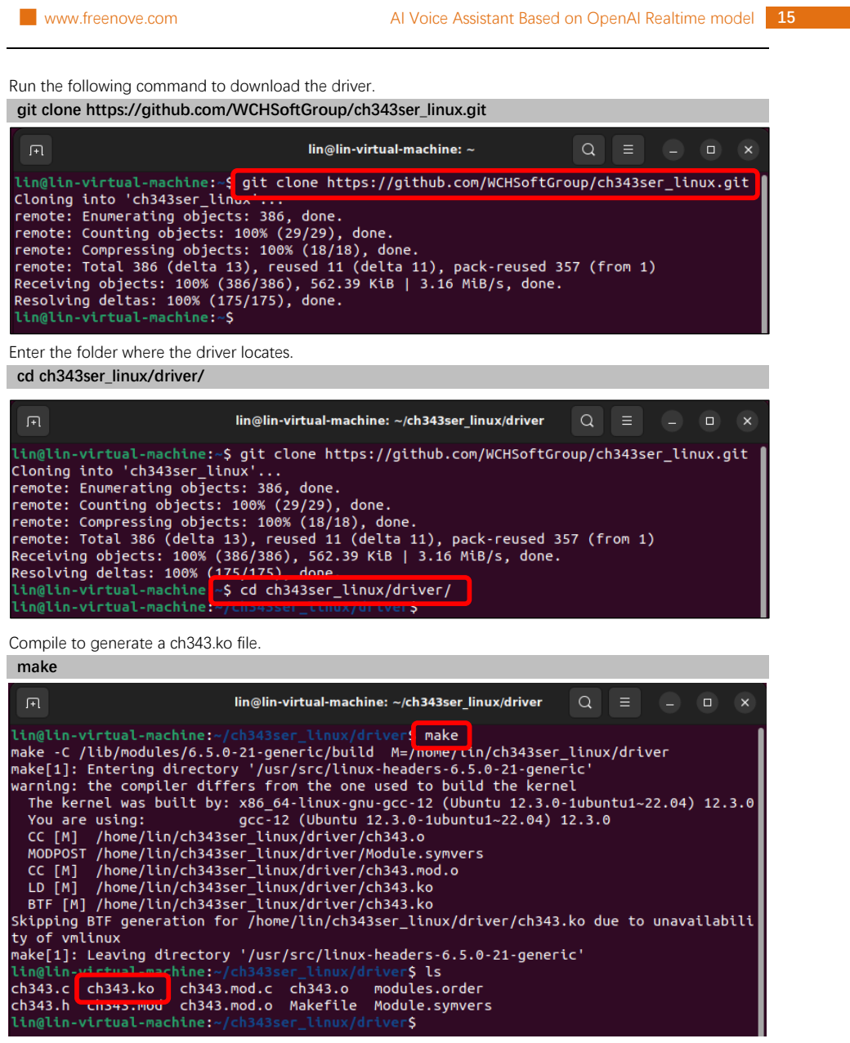
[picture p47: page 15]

█ www.freenove.com | AI Voice Assistant Based on OpenAI Realtime model | 15

Run the following command to download the driver.
git clone https://github.com/WCHSoftGroup/ch343ser_linux.git

Enter the folder where the driver locates. cd ch343ser_linux/driver/

Compile to generate a ch343.ko file. make

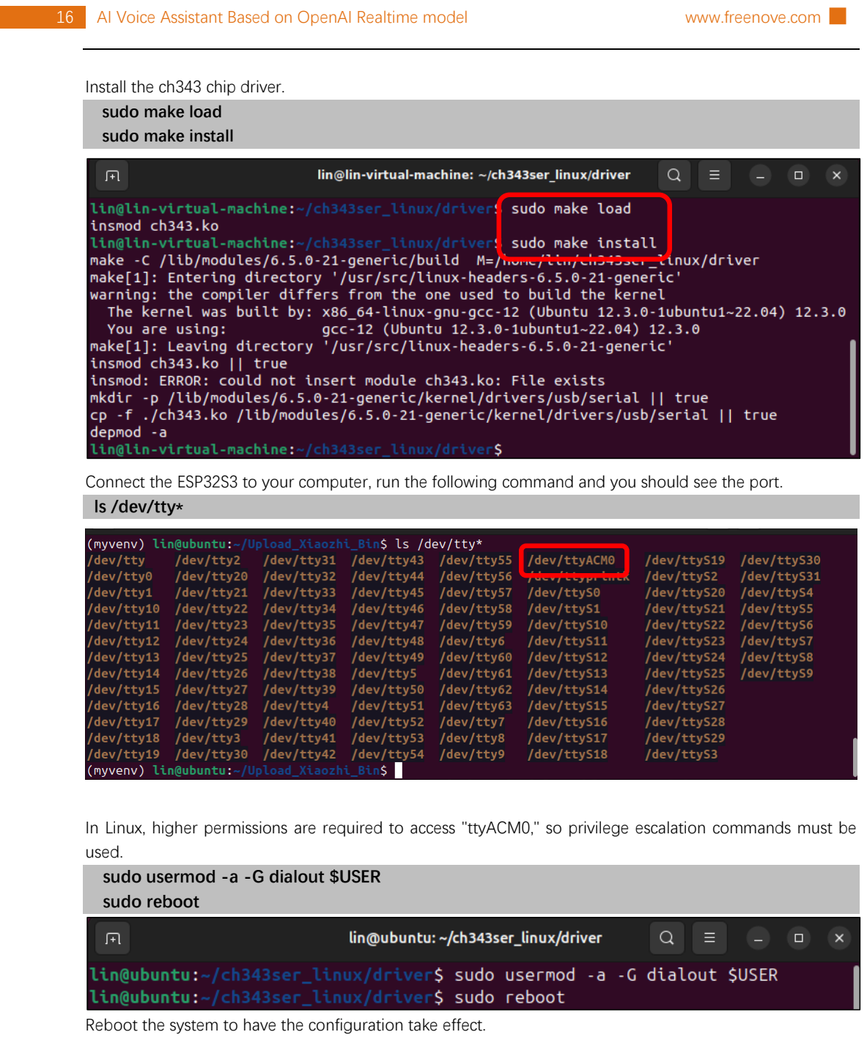
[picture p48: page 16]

16 | AI Voice Assistant Based on OpenAI Realtime model | www.freenove.com █

Install the ch343 chip driver.
sudo make load
sudo make install

Connect the ESP32S3 to your computer, run the following command and you should see the port. ls /dev/tty*

In Linux, higher permissions are required to access "ttyACM0," so privilege escalation commands must be used.
sudo usermod -a -G dialout $USER
sudo reboot

Reboot the system to have the configuration take effect.

█ www.freenove.com | OpenAI Code | 17

# OpenAI Code

## Visual Studio Code

As we use Visual Studio Code to compile and upload code, we need to install the software before proceeding.

## Windows

First, download Visual Studio Code by visiting https://code.visualstudio.com/Download. Choose the appropriate version for your operating system, then download and install it

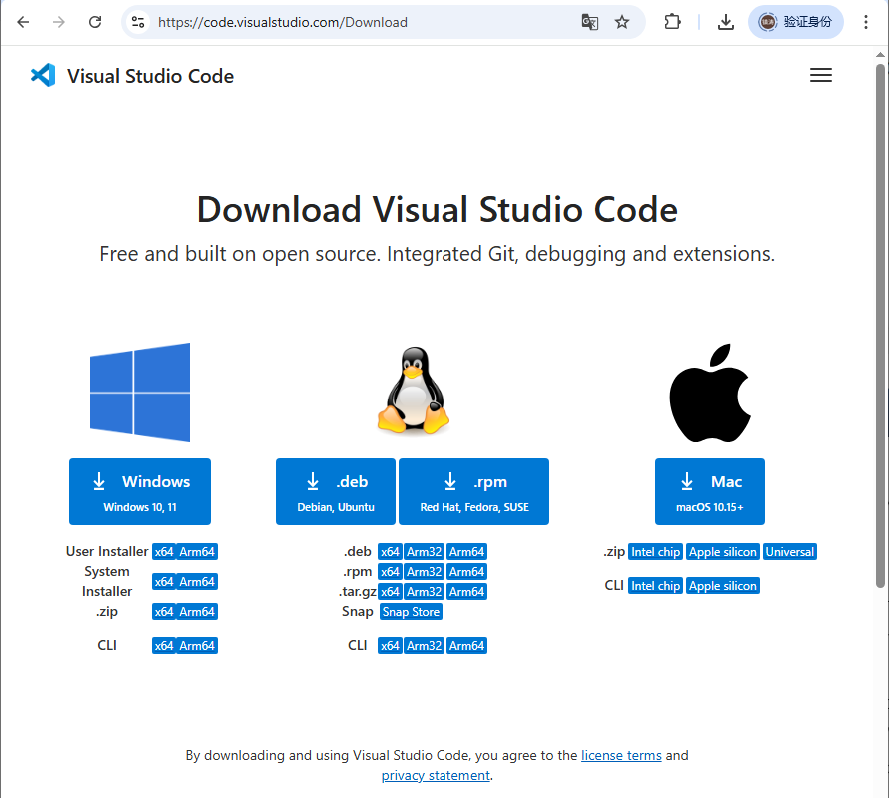
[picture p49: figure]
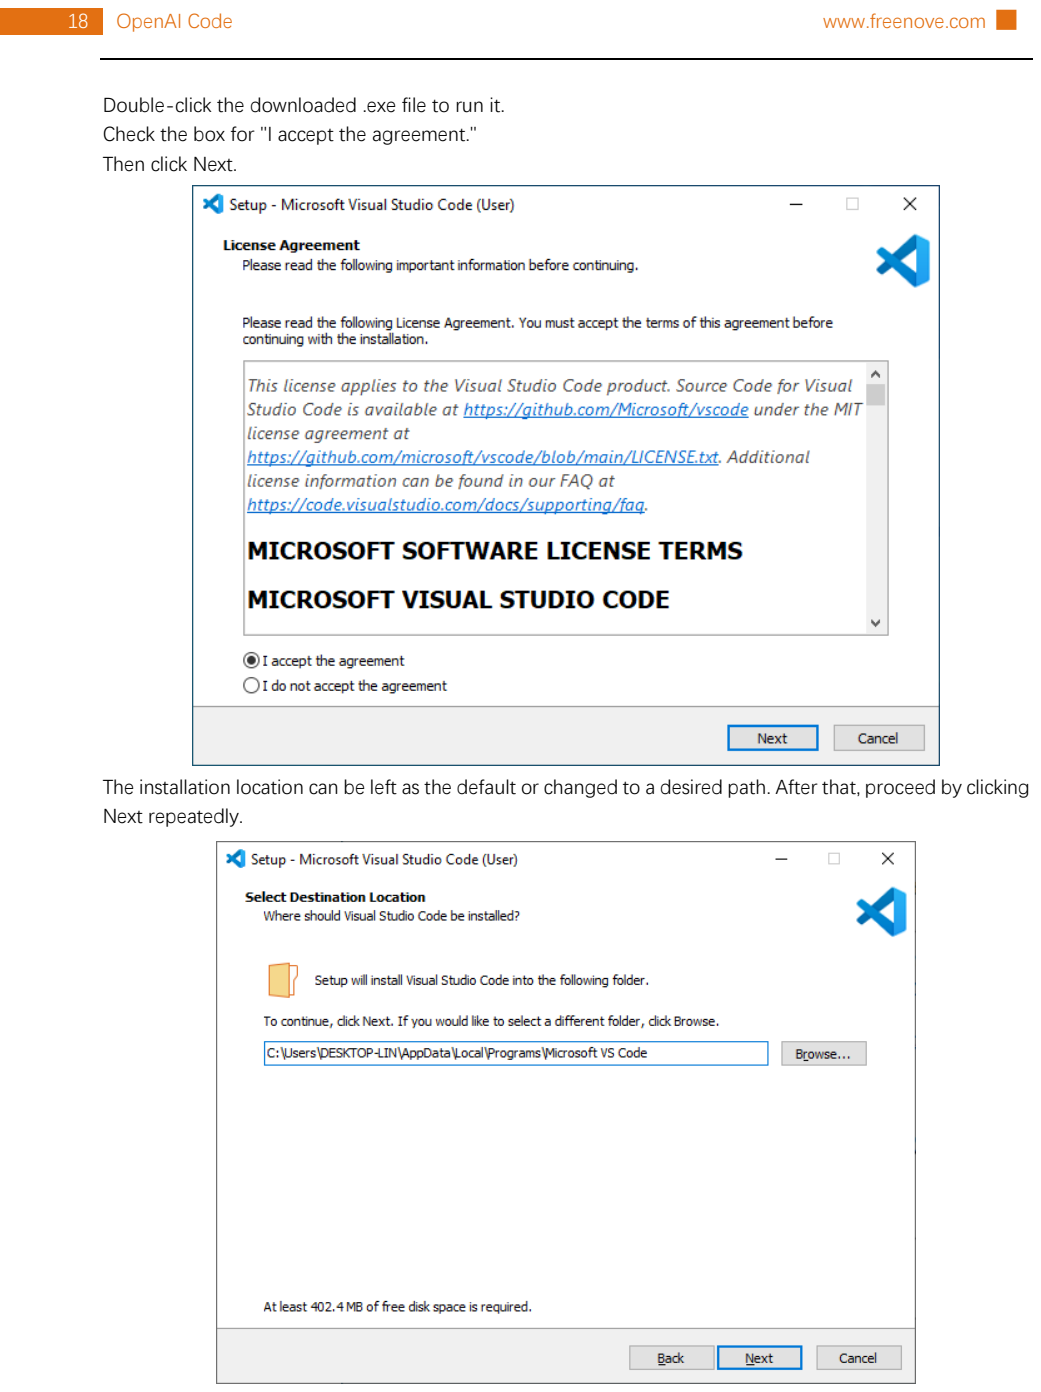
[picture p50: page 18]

18 | OpenAI Code | www.freenove.com █

Double-click the downloaded .exe file to run it.
Check the box for "I accept the agreement." Then click Next.

The installation location can be left as the default or changed to a desired path. After that, proceed by clicking Next repeatedly.

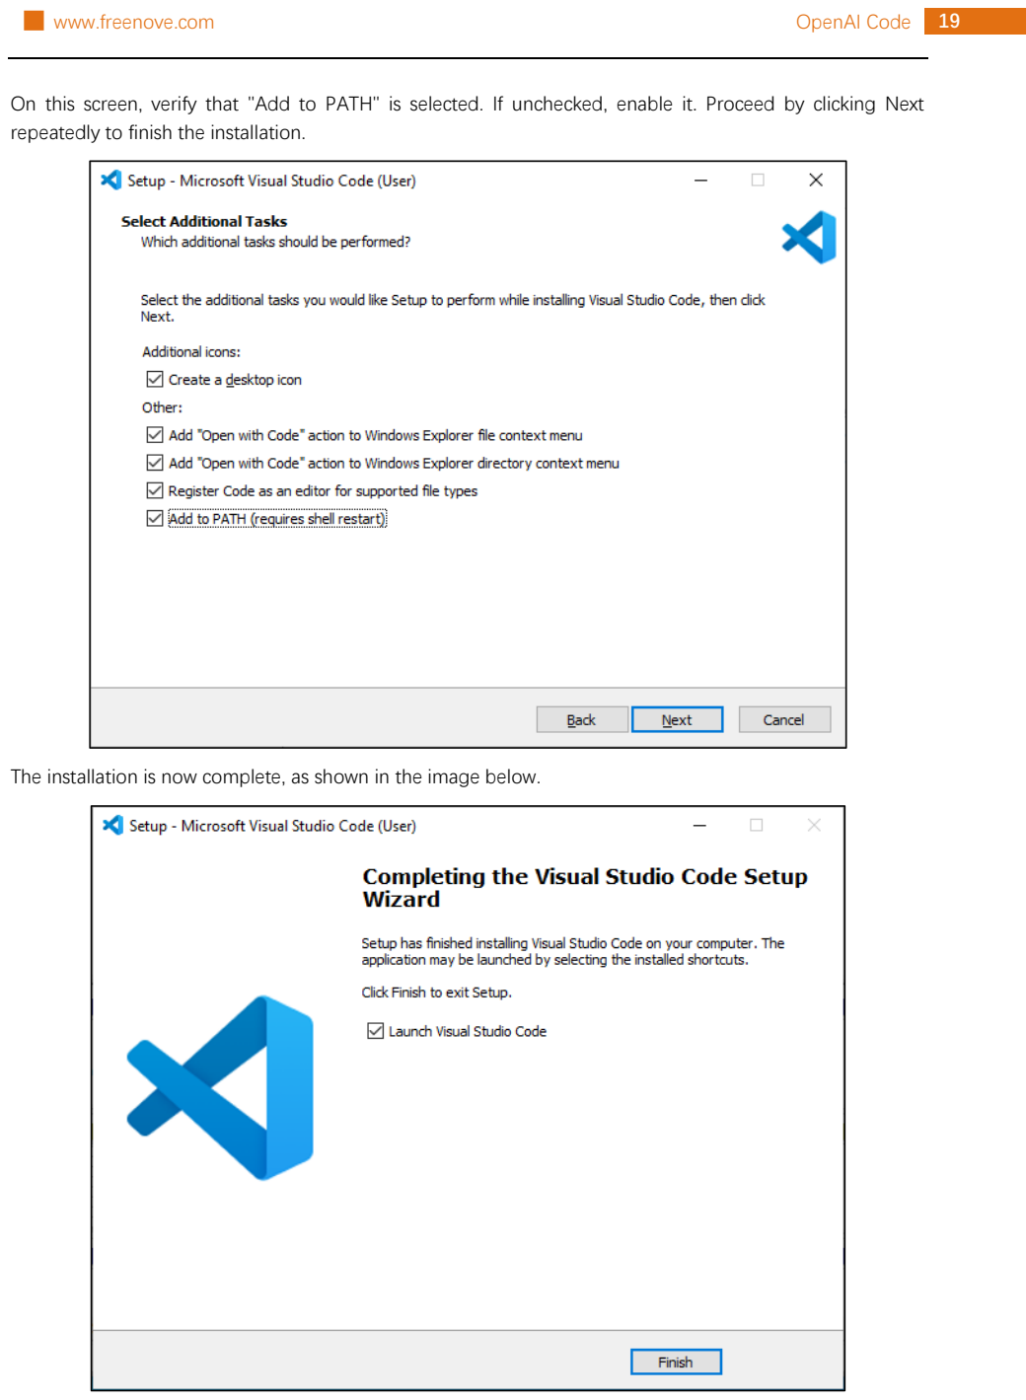
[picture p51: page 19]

█ www.freenove.com | OpenAI Code | 19

On this screen, verify that "Add to PATH" is selected. If unchecked, enable it. Proceed by clicking Next repeatedly to finish the installation.

The installation is now complete, as shown in the image below.

## Mac

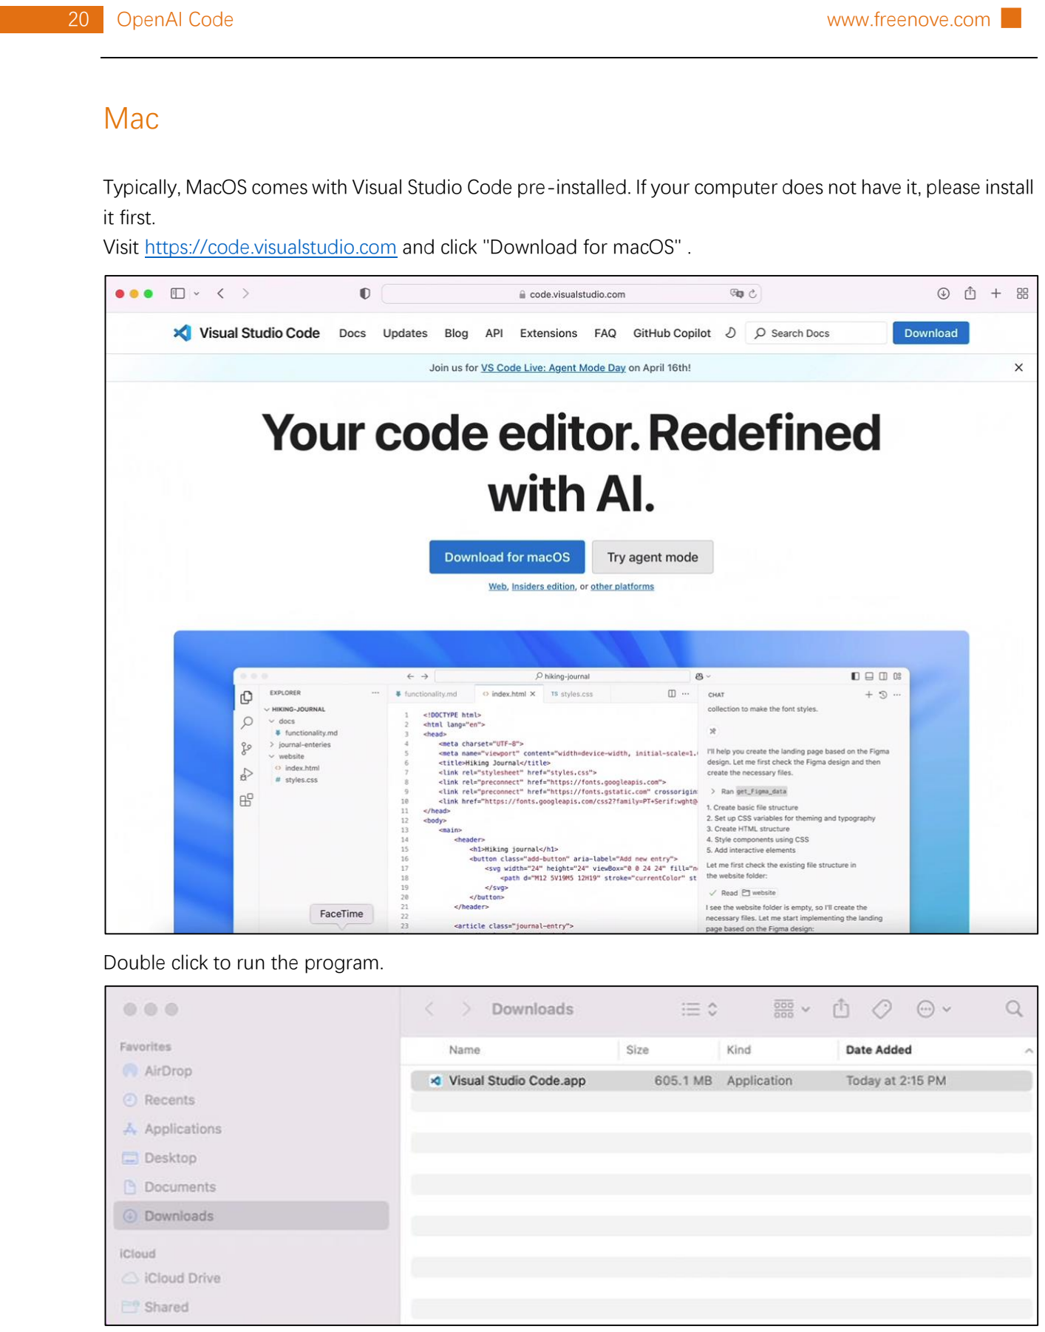
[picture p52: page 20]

20 | OpenAI Code | www.freenove.com █

Typically, MacOS comes with Visual Studio Code pre-installed. If your computer does not have it, please install it first.
Visit https://code.visualstudio.com and click "Download for macOS" .

Double click to run the program.

## Linux

█ www.freenove.com | OpenAI Code | 21

If your computer does not have Visual Studio Code, please install it first. Visit https://code.visualstudio.com and click ".deb" .

Open the downloaded“code_xxx.deb” file.

22 | OpenAI Code | www.freenove.com █

Click “Install” to install Visual Studio Code.

Wait for the installation to complete. Once finished, it should look like the image below.

█ www.freenove.com | OpenAI Code | 23

Click Show Apps and you can see the Visual Studio Code is in the system.

## ESP-IDF V5.4.1

24 | OpenAI Code | www.freenove.com █

Visual Studio Code is a versatile code editor. To program with the ESP-IDF SDK, we need to install the ESP-IDF extension for it.
Open Visual Studio Code.
Click on the menu bar: File -> Preferences -> Extensions.

Mac OS: Click “Code”->”Preferences”->”Extensions” on the menu bar.

█ www.freenove.com | OpenAI Code | 25

Search for "ESP-IDF" in the extension bar, select the correct result from the list, then click the Install button to proceed.

The ESP-IDF extension icon will now appear in the left sidebar - click it to continue.

Scroll down with your mouse, locate and click on the "Advanced" option.

26 | OpenAI Code | www.freenove.com █

Click the first option: "Configure ESP-IDF Extension”.

Select "EXPRESS" on the right.

█ www.freenove.com | OpenAI Code | 27

Note: If you're using macOS or Ubuntu, please complete the necessary preparations as prompted before proceeding with installation.

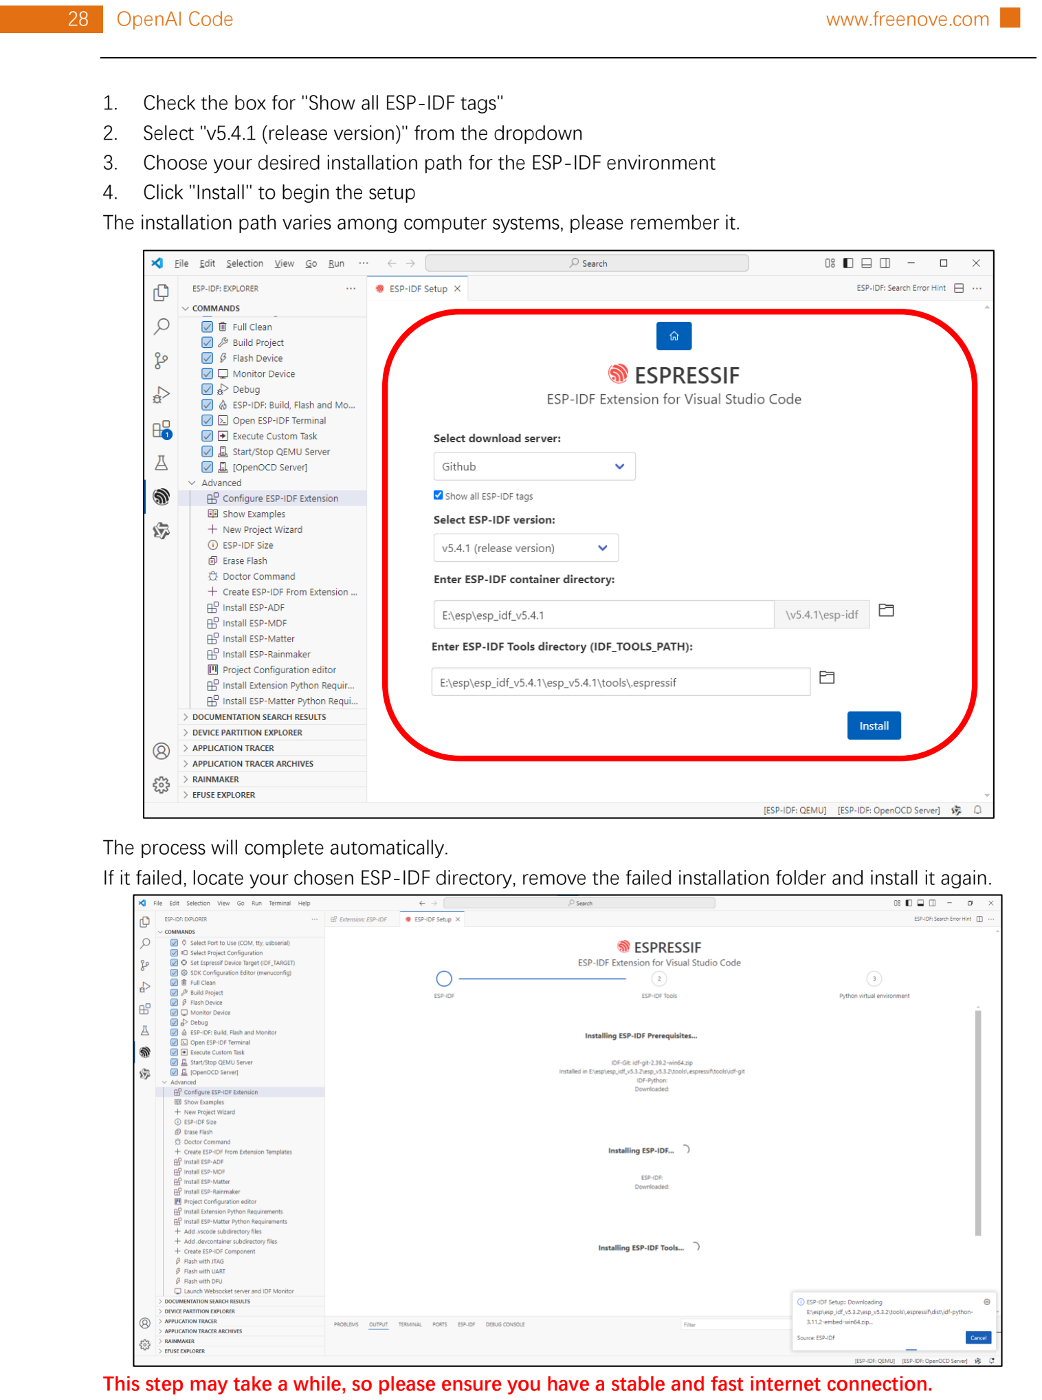
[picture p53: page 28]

28 | OpenAI Code | www.freenove.com █
1. Check the box for "Show all ESP-IDF tags"
2. Select "v5.4.1 (release version)" from the dropdown
3. Choose your desired installation path for the ESP-IDF environment
4. Click "Install" to begin the setup
The installation path varies among computer systems, please remember it.

The process will complete automatically.
If it failed, locate your chosen ESP-IDF directory, remove the failed installation folder and install it again.

This step may take a while, so please ensure you have a stable and fast internet connection.

█ www.freenove.com | OpenAI Code | 29

If the installation continues to fail, check the relevant link for your operating system below:
Window: https://docs.espressif.com/projects/esp-idf/en/latest/esp32/get-started/windowssetup.html (https://docs.espressif.com/projects/esp-idf/en/latest/esp32/get-started/windows-setup.html)
Mac & Linux: https://docs.espressif.com/projects/esp-idf/en/latest/esp32/get-started/linux-macossetup.html (https://docs.espressif.com/projects/esp-idf/en/latest/esp32/get-started/linux-macos-setup.html)

The complete installation is as shown below.

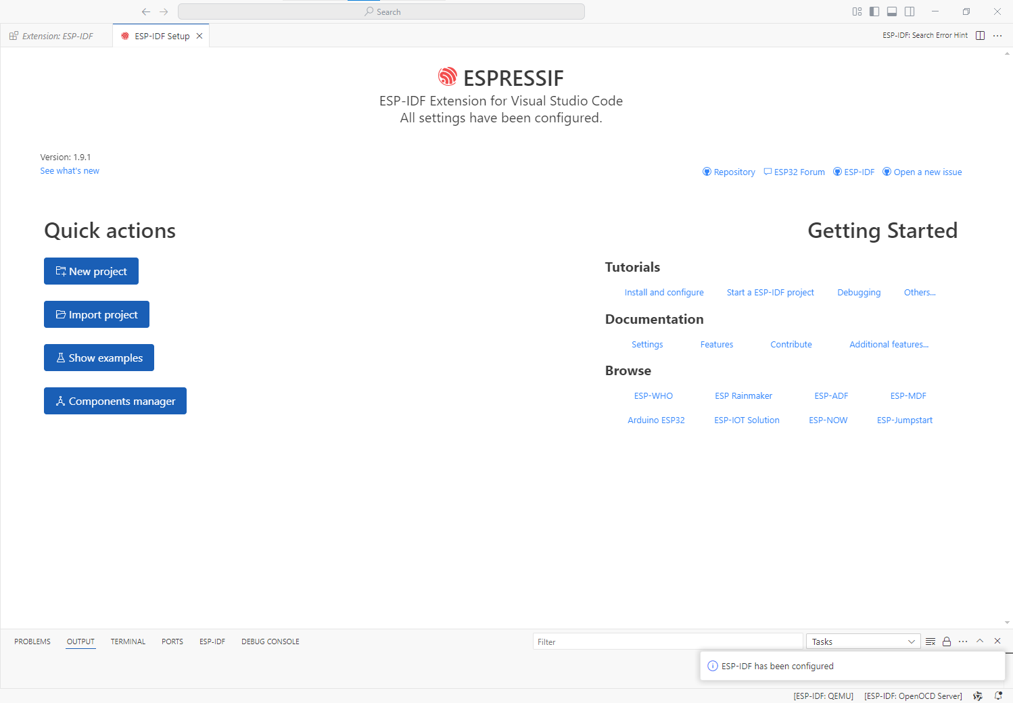
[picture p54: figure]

For more about ESP-IDF, please refer to https://docs.espressif.com/projects/vscode-esp-idf-extension/en/latest/installation.html

30 | OpenAI Code | www.freenove.com █

## OpenAI Code

This project is derived from the open-source repository: https://github.com/openai/openai-realtimeembedded, (https://github.com/openai/openai-realtime-embedded) licensed under MIT License. We have only adapted it for third-party learning and AI functionality trials, without any commercial promotion or application. This tutorial is intended solely for enthusiasts to supplement their learning.

## Code Downloading

Windows

Use the shortcut "Win+R", enter "CMD" in the pop-up window, and open the CMD interface.

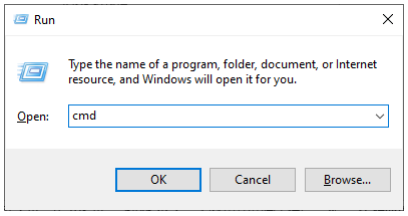
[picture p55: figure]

In the Terminal, install the code with git command.
git clone --recurse-submodules https://github.com/Freenove/openai-realtime-embedded

The installation is completed as shown below.

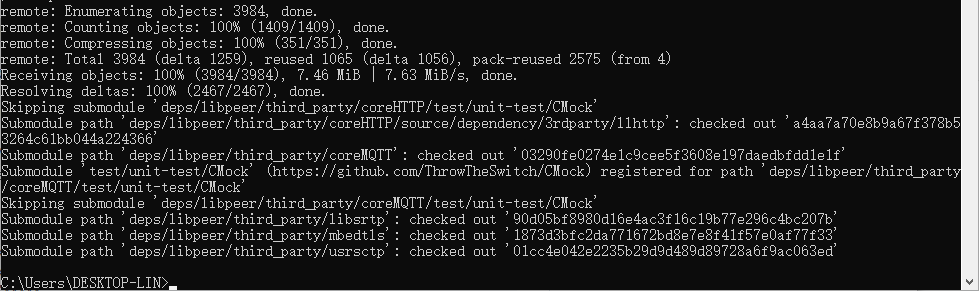
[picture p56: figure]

If you do not have the git tool on your computer, please download and install it by visiting https://gitscm.com/downloads (https://git-scm.com/downloads)

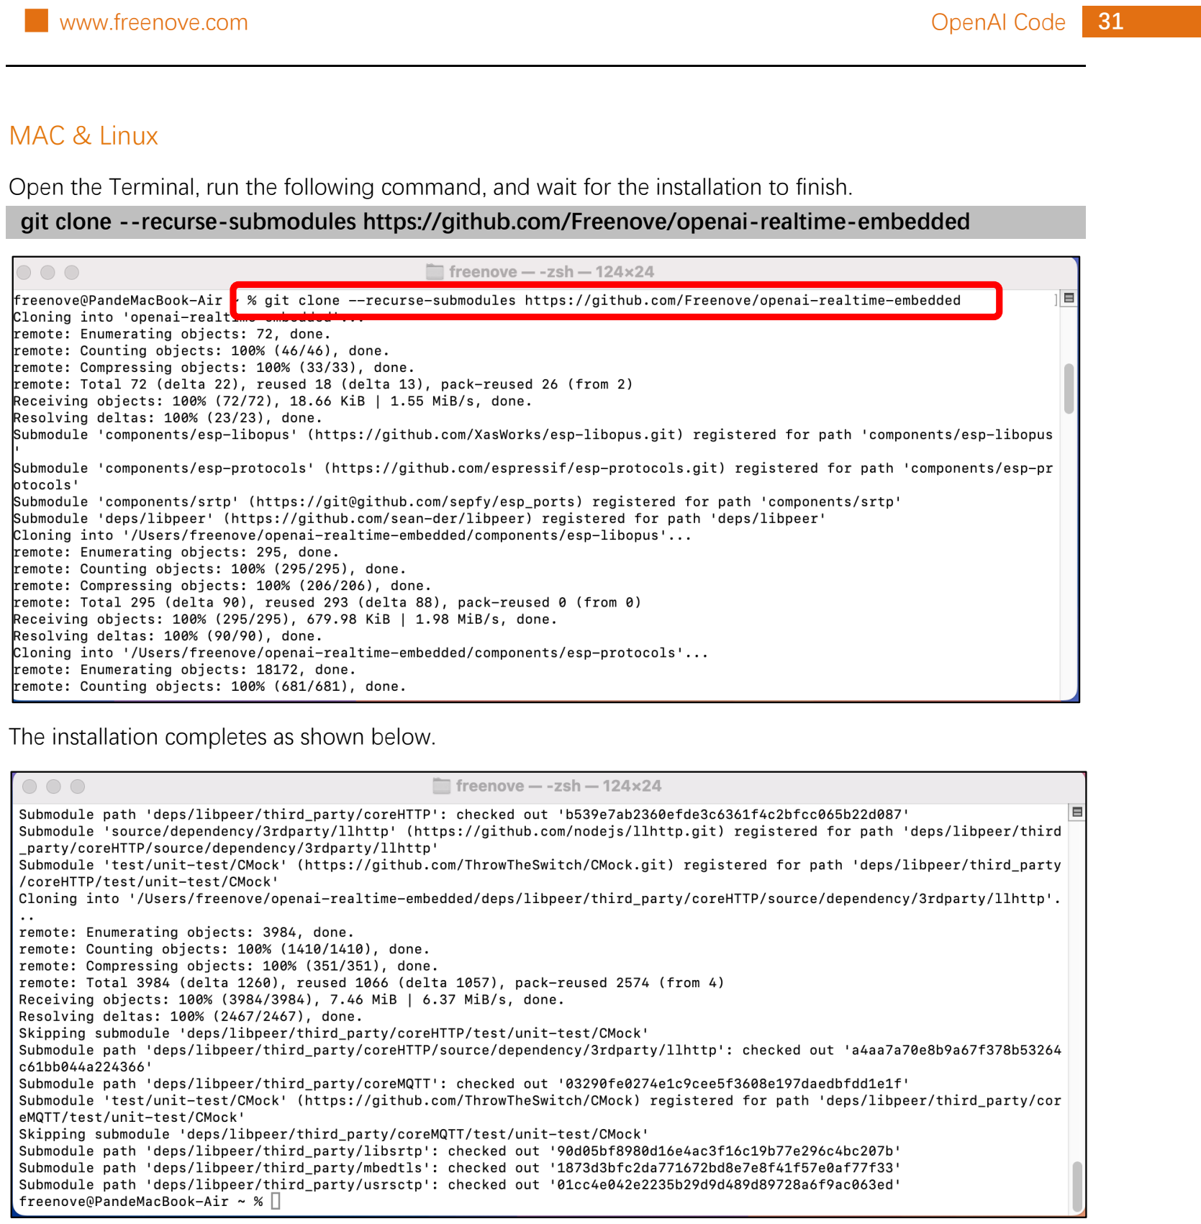
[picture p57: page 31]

█ www.freenove.com | OpenAI Code | 31

MAC & Linux

Open the Terminal, run the following command, and wait for the installation to finish.
git clone --recurse-submodules https://github.com/Freenove/openai-realtime-embedded

The installation completes as shown below.

## Configuring Code Environment


32 | OpenAI Code | www.freenove.com █

On Visual Studio Code, click “File” -> “Open Folder…”

Select the openai-realtime-embedded older. Here, the interface of the Windows system is taken as an example. The operation on the mac and Linux system is similar.

█ www.freenove.com | OpenAI Code | 33

Check the box “Trust the authors of all files in the parent folder ‘Downloads” and select “Yes, I trust the authors”.

Please note: A pop-up notification 'Generate comple_commands.json' will appear in the lower-right corner. Please disregard it. DO NOT click it.

34 | OpenAI Code | www.freenove.com █

Connect the ESP32S3 WROOM board to your computer with the USB cable (do not use the wrong connector).

Click on 'COMx' in the bottom-left corner to display all available COM ports on your computer. Locate and select the entry labeled 'ESP32-S3'.

Click the 'ESP32' button in the bottom-left corner to display all available ESP32 models, then select 'ESP32S3' from the list."

█ www.freenove.com | OpenAI Code | 35

From the new selection menu, choose 'ESP32-S3 Chip (via ESP-PROG) - ESP32-S3 debugging via ESP-PROG Board...'

Wait until it shows “Target ESP32S3 Set Successfully” at the bottom right.

36 | OpenAI Code | www.freenove.com █

As of the time of writing, the Freenove Media Kit for ESP32-S3 comes in two different models with varying screen sizes. However, this tutorial applies to both versions. Please select the corresponding macro definition based on your device's screen size (only one should be enabled, and the other must be commented out) (3.5inch coming soon).

## Registering Open API Keys

█ www.freenove.com | OpenAI Code | 37

If you don't have an OpenAI API key yet, please visit https://platform.openai.com/docs/overview to sign up and purchase one.
You'll need to create an account. Click "Sign up" in the top-right corner.

Create the account in any way you prefer.

38 | OpenAI Code | www.freenove.com █

Here we take Email address as an example. Input the email address and password, and click Continue.

OpenAI Platform will send a verification code to your email address. Input the code to the bar, click Continue.

█ www.freenove.com | OpenAI Code | 39

Complete your personal information.

You can either fill the Organization Name or not, then click Create organization.

You can click “I’ll invite my team later”.


40 | OpenAI Code | www.freenove.com █

Name it whatever you like, and then click “Generate API Key”.

Click Copy and paste your “My test key” somewhere to save it. If you click "Continue”, you will no longer be able to view the key again!
We recommend creating a separate document to store your key securely and prevent loss.


█ www.freenove.com | OpenAI Code | 41

OpenAI operates on a paid service model. You need to purchase for credits to ensure uninterrupted access
to its features.

After completion, the interface will appear as shown below. Click the settings icon in the upper right corner.

42 | OpenAI Code | www.freenove.com █

You can click "API Keys" to manage your OpenAI keys.

Click "Billing" to check your available balance, or click "Add Payment Details" to top up funds.

Now you have your own working OpenAI API keys. Feel free to explore more features on the website.

## Code Compilation and Uploading

█ www.freenove.com | OpenAI Code | 43

After ensuring everything is properly configured, let's start compiling the code. Click "Full Clean" below to clear all previous compilation data.

Click "ESP-IDF: Build, Flash and Monitor" below. It will compile the code, upload it to the ESP32-S3, and open the serial monitor.

The first compilation may take longer—please ensure a stable internet connection and wait patiently.

44 | OpenAI Code | www.freenove.com █

If you encounter the following error during compilation, it's typically caused by issues with the ESP-IDF toolchain. This often occurs due to network problems that prevented some toolchain components from installing properly. Please reinstall ESP-IDF. You can refer to ESP-IDF V5.4.1.


When the code compilation is complete and you upload it for the first time, you will see the prompt below. Please select "UART".


After the upload completes, the serial monitor will automatically open and establish an internet connection to access OpenAI. You can now start chatting via the ESP32-S3.


█ www.freenove.com | OpenAI Code | 45

Computer End

Enable Wi-Fi, locate "OpenAI" in the Wi-Fi settings, and click "Connect".


46 | OpenAI Code | www.freenove.com █

Open the browser, enter 192.168.4.1 in the address bar, and press Enter to access the network configuration page.

Enter the Wi-Fi name and password, as well as the API key of OpenAI, and then click Submit.

█ www.freenove.com | OpenAI Code | 47

The following interface indicates successful configuration.

When you see the “How can I help” prompt, you can start communicate with openAI.

The chat logs will be displayed simultaneously in VS Code's Serial Monitor.

48 | OpenAI Code | www.freenove.com █

Mobile End

Enable Wi-Fi, locate "OpenAI" in the Wi-Fi settings to connect.

Open the browser on your phone, input 192.168.4.1 in the address bar to enter the network settings interface.

Enter the Wi-Fi name and password, as well as the API key of OpenAI, and then click Submit.

█ www.freenove.com | OpenAI Code | 49

The following interface indicates successful configuration.

When you see the “How can I help” prompt, you can start communicate with openAI.

The chat logs will be displayed simultaneously in VS Code's Serial Monitor.

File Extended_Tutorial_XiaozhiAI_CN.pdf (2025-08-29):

█ www.freenove.com | 目录 | 1

目录

2 | 基于小智 AI 的 AI 语音助手 | www.freenove.com █

# 基于小智 AI 的 AI 语音助手

本项目使用 Media Kit 实现一个 AI 语音助手，需要有一定的编程基础，且对于 ESP-IDF 和开源大模型有一 定的了解。

## 项目介绍

本语音助手项目（https://github.com/Freenove/xiaozhi-esp32）来自开源项目（https://github.com/78/xiaozhi-esp32），该项目可以在嵌入式设备上调用市面上大多数长语言文本模型 （LLM），并通过语音活动检测（VAD）服务、语音识别(ASR)服务、语音转文本（STT）服务、文本转语音 （TTS 服务）、记忆存储（Memory）服务、意图识别（Intent）服务等多种服务，来实现语音对话功能，制 作属于你自己的 AI 语音助手。Freenove 将该项目适配到了产品 Media Kit 上。本文将介绍如何在 Media Kit 上运行该项目。

本项目有两种运行方式，
1. 在线版本，接入 xiaozhi.me 服务器，目前个人用户可以免费试用。
2. 离线版本，以上提到的各项服务都需要在本地个人电脑上搭建本地服务器，使用体验完全取决模型的选 取和本地电脑性能。本地服务器项目（https://github.com/Freenove/xiaozhi-esp32-server ）来自开源项 目（https://github.com/xinnan-tech/xiaozhi-esp32-server ）。
对于偏向于使用 AI 助手的用户，我们建议你使用在线版本。 对于偏向于开发者用户，可以尝试部署离线版本，以深入学习和了解 AI 助手所需要的各项服务。值得注意 的是，个人电脑难以同时运行以上各种服务，尤其是核心服务 LLM，这可能导致你的 AI 助手体检较差，因 此，离线版本仅具有更多的学习研究价值。

## 注意事项

⚫ | 项目版权:
⚫ | 语音助手项目原始作者署名为“虾哥”，Freenove 公司 fork 该项目并适配到 Media Kit 中，该项目遵
守 MIT 协议。
⚫ 本地服务器项目原始作者为“xinnan-tech”, Freenove 公司 fork 该项目并适配到 Media Kit 中，该项 目遵守 MIT 协议。
⚫ | 支持的国家或地区:
⚫ | 在线版本，这取决于 xiaozhi.me 服务器支持的国家或地区，并非所有国家或地区都受到支持。您可
以注册页面查看（https://xiaozhi.me/login?redirect=/console/agents）。 对于使用体验，也受 xiaozhi.me (https://xiaozhi.me/login?redirect=/console/agents）。%20对于使用体验，也受xiaozhi.me) 服务器的影响。如果您访问 xiaozhi.me 服务器的网络较差，则体验相对就差一些。
⚫ | 离线版本，无，您可以在任意国家或地区部署离线版本。
⚫ | 支持的语言：
⚫ | 在线版本：目前支持中文普通话、中文粤语、英语、日语、韩语等。如果您不会这些语言，那么
使用在线版本您将无法与小智 AI 正常交流。
⚫ 离线版本：取决于您部署的 ASR 模型。默认的 FunASR 模型仅支持中文普通话、中文粤语、英 语、日语、韩语。

█ www.freenove.com | 基于小智 AI 的 AI 语音助手 | 3
⚫ | 费用
⚫ | 在线版本：当前 xiaozhi.me 提供免费服务，我们不能保证在线服务器一直免费。
⚫ | 离线版本：上述提到的各项子服务中，均有收费服务或免费服务，取决于您自己的选择。
⚫ | 遇到问题，如果您按照教程操作，仍然无法使用，请与我们联系（support.freenove.com）。由于在线
服务由 xiaozhi.me 提供，如果 xiaozhi.me 关闭了服务，那么我们也将会关闭相关的文档、教程、代 码。

## 小智 AI 使用声明

我们仅在 https://github.com/78/xiaozhi-esp32 基础上提供适配，用做第三方学习和 AI 功能试用，不做商业 性质推广和应用。本教程仅给爱好者附加学习使用。
请注意：
1， 由于这个项目是第三方开源项目，如果您在学习过程中遇见问题，请向开源项目发起 issue： https://github.com/78/xiaozhi-esp32/issues
2， 目前小智 AI 仅支持普通话，粤语，英语，韩语，日语这 5 种语言识别。其他语言暂时仍不支持。 3， 目前小智服务器的界面仅支持英语、中文、日语。且小智服务器目前仅支持下列国家使用手机注册账号。 其他国家暂不支持。
在这个项目中，ESP32-S3 使用 websocket 的方式，和小智 AI 服务器进行数据交互。


4 | 基于小智 AI 的 AI 语音助手 | www.freenove.com █

## Freenove Media Kit for ESP32-S3

截至本文撰写时，Freenove Media Kit for ESP32-S3 提供两种屏幕尺寸的型号，但本教程内容均适用于这 两个版本

## 1.14inch

该音频电路板集成了多个功能硬件模块，包括 1.14 英寸 TFT 显示屏、麦克风、电池充电电路、音频处理电 路、耳机插孔以及集成式扬声器，如下图所示。; 外置扬声器接口; 音频解码与功放芯片; 板载扬声器; 数字麦克风; 电池充电芯片; 降压芯片; 锂电池接口

1.14-inch
TFT 显示屏

麦克风

五向按键

RGB 灯

电源按键

## 3.5inch

█ www.freenove.com | 基于小智 AI 的 AI 语音助手 | 5

该音频电路板集成了多个功能硬件模块，包括 3.5 英寸 TFT 显示屏、麦克风、电池充电电路、音频处理电 路、耳机插孔和扬声器插孔，如下图所示。

RGB 灯

3.5-inch
TFT 屏幕

电源按键

左麦克风

右麦克风

五向按键

耳机插孔 | 电池接口

降压电路

音频芯片

充电芯片

喇叭接口 | DAC 芯片

按键

## 安装 CH343 (Importance)

6 | 基于小智 AI 的 AI 语音助手 | www.freenove.com █

ESP32-S3 WROOM 使用 CH343 芯片下载代码，因此在使用前，需在电脑上安装 CH343 驱动程序。

Windows

首先下载 CH343 驱动，点击 http://www.wch-ic.com/search?t=all&q=ch343，根据您的操作系统选择对应 版本进行下载。

Windows

MAC

█ www.freenove.com | 基于小智 AI 的 AI 语音助手 | 7

如果您不想从官网下载安装包，可以打开 “Freenove_Media_Kit_for_ESP32-S3/CH343” 文件夹，我们已 为您准备好驱动安装包

2. 打开文件夹进入目录： “Freenove_Media_Kit_for_ESP32-S3/CH343/Windows/”
3. 双击运行“CH343SER.EXE”.

8 | 基于小智 AI 的 AI 语音助手 | www.freenove.com █
4. 点击 "INSTALL" 并等待安装完成
5. 安装成功！请关闭所有界面

注意：如果看到提示“驱动器已成功预安装”，则表明安装失败。 请确保使用的是 USB 数据线，而不是普通充电线

█ www.freenove.com | 基于小智 AI 的 AI 语音助手 | 9
6. 当 ESP32-S3 WROOM 模块连接到电脑时，选中"此电脑"，右键选择"管理"，在弹出的新对话框中点击"设 备管理器"，即可看到如下界面。
7. 至此，CH343 驱动已成功安装，关闭所有对话框。


10 | 基于小智 AI 的 AI 语音助手 | www.freenove.com █

MAC

首先下载 CH343 驱动，点击 http://www.wch-ic.com/search?t=all&q=ch343，根据您的操作系统选择对应 版本进行下载。

如果不想下载安装包，您可以打开 “Freenove_Media_Kit_for_ESP32-S3/CH343” 文件夹，我们已准备好 安装包。
其次，打开 “Freenove_Media_Kit_for_ESP32-S3/CH343/MAC/” 目录。

Windows

MAC

█ www.freenove.com | 基于小智 AI 的 AI 语音助手 | 11

第三步，点击 Continue。

运行

12 | 基于小智 AI 的 AI 语音助手 | www.freenove.com █

第四步，点击 Install。

然后等待完成

█ www.freenove.com | 基于小智 AI 的 AI 语音助手 | 13

最后，重新启动你的电脑

若按照上述步骤仍未成功安装 CH340 驱动，可查阅 readme.pdf 文件进行安装。

ReadMe

14 | 基于小智 AI 的 AI 语音助手 | www.freenove.com █

Linux

这里以 Ubuntu 为例。打开 Linux 系统的终端.

使用指令“lsusb”查看端口。
lsusb
ls /dev/tty*

如果您的电脑没有 CH343 驱动，您可以按照接下来的步骤安装它。如果您的电脑能识别到 CH343 驱动，您 可以跳过下面的步骤。


█ www.freenove.com | 基于小智 AI 的 AI 语音助手 | 15

使用指令下载 CH343 驱动。
git clone https://github.com/WCHSoftGroup/ch343ser_linux.git

进入 ch343 驱动文件夹。
cd ch343ser_linux/driver/

编译并生成 ch343.ko 文件。
make

16 | 基于小智 AI 的 AI 语音助手 | www.freenove.com █

安装 ch343p 芯片的驱动。
sudo make load
sudo make install

当将 ESP32S3 连接到电脑时，使用指令后的显示内容如下图所示。 ls /dev/tty*

在 Linux 中调用”ttyACM0”通常需要较高的权限，因此使用指令提升用户权限是必须的。 sudo usermod -a -G dialout $USER
sudo reboot

重启系统以使配置生效。

█ www.freenove.com | 基于小智 AI 的 AI 语音助手 | 17

## 小智 AI 固件

如果您的硬件还没有小智的固件，您可以参考接下来的教程，重新给 ESP32 S3 WROOM 上传固件。 如果您的硬件已经集成了小智的固件，您可以跳过这个章节。

## 安装 Python (Importance)

Windows

请下载并安装 Python3 软件包。
https://www.python.org/downloads/windows/

点击下载 Python 3.13.3

18 | 基于小智 AI 的 AI 语音助手 | www.freenove.com █

重要提示：务必勾选 "Add Python 3.13 to PATH" 选项。

勾选所有选项后，点击 “Next”。

█ www.freenove.com | 基于小智 AI 的 AI 语音助手 | 19

此处可设置 Python 的安装路径。我们将其安装在 D 盘。若您是新手，可直接选择默认路径。

等待安装完成

现在安装已完成。

20 | 基于小智 AI 的 AI 语音助手 | www.freenove.com █

MAC

下载安装包（链接：https://www.python.org/downloads/） (https://www.python.org/downloads/%EF%BC%89) 点击下载 Python 3.13.3

运行已下载的安装包，点击 "Continue" 按钮。

█ www.freenove.com | 基于小智 AI 的 AI 语音助手 | 21

点击”Continue”

点击”Continue”

22 | 基于小智 AI 的 AI 语音助手 | www.freenove.com █

点击 "Install"。若电脑设有密码，请输入密码后继续安装。

安装完成

█ www.freenove.com | 基于小智 AI 的 AI 语音助手 | 23

Linux

检查您的系统是否已经安装了 Python3， Python 要求 Python3.10 以上的版本。 python –version
python3 –version

安装 python3，默认安装最新版本。
sudo apt install python3

将 python 链接到 python3.
sudo rm /usr/bin/python
sudo ln -s /usr/bin/python3 /usr/bin/python

安装 python3.13-venv 虚拟环境。
sudo apt install python3-venv

安装 pip。
sudo apt install python3-pip

## 上传固件


24 | 基于小智 AI 的 AI 语音助手 | www.freenove.com █

Windows

进入 Upload_Xiaozhi_Bin 文件夹。

在文件栏输入“CMD”，并按下回车键。

输入“python –version“，查看是否已经安装 Python 环境，如果没有打印 Python 的版本信息，说明 Python 没有正确安装环境，请重新安装。

█ www.freenove.com | 基于小智 AI 的 AI 语音助手 | 25

使用数据线连接电脑和 ESP32 S3 WROOM，请注意，不要连接错 Type C 接口。

输入“python upload_xiaozhi_bin.py”，并按下回车。
如果您的电脑没有安装 esptool 及其相关的软件库，它会自动安装这些库。

然后，它会调用 esptool 将 bin 文件夹中的文件上传到 ESP32 S3 WROOM 中。

26 | 基于小智 AI 的 AI 语音助手 | www.freenove.com █

ESP32 S3 WROOM 显示如下。

MAC

进入 Upload_Xiaozhi_Bin 文件夹。

输入“python –version“，查看是否已经安装 Python 环境，如果没有打印 Python 的版本信息，说明 Python 没有正确安装环境，请重新安装。

使用数据线连接电脑和 ESP32 S3 WROOM，请注意，不要连接错 Type C 接口。

输入“python upload_xiaozhi_bin.py”，并按下回车。

█ www.freenove.com | 基于小智 AI 的 AI 语音助手 | 27

然后，它会调用 esptool 将 bin 文件夹中的文件上传到 ESP32 S3 WROOM 中。

ESP32 S3 WROOM 显示如下。


28 | 基于小智 AI 的 AI 语音助手 | www.freenove.com █

Linux

进入 Upload_Xiaozhi_Bin 文件夹。 cd Upload_Xiaozhi_Bin

输入“python –version“，查看是否已经安装 Python 环境，如果没有打印 Python 的版本信息，说明 Python 没有正确安装环境，请重新安装。

使用数据线连接电脑和 ESP32 S3 WROOM，请注意，不要连接错 Type C 接口。

创建一个虚拟环境，并命名为“myvenv”。
python -m venv myvenv

您可以使用下面的指令激活和关闭虚拟环境。
source myvenv/bin/activate deactivate

█ www.freenove.com | 基于小智 AI 的 AI 语音助手 | 29

激活虚拟环境。

使用指令查看 ESP32S3 的端口号。
ls /dev/tty*
当 ESP32S3 没有连接到电脑时，使用指令后的显示内容如下图所示。

当将 ESP32S3 连接到电脑时，使用指令后的显示内容如下图所示。

对比前后的区别，多出来的端口就是 ESP32S3 连接到电脑上的端口号。

在运行 python 文件之前，需要修改文件中的端口号。
使用指令打开 python 文件。
sudo nano upload_xiaozhi_bin.py

30 | 基于小智 AI 的 AI 语音助手 | www.freenove.com █

在文本编辑器中，找到’“--port”, “COMx”’这一行，将“COMx”修改为 ESP32S3 在电脑上的端口号。

修改后如下图所示。

使用 Crtl+O，保存文件。
使用 Ctrl+X，退出编辑器。

█ www.freenove.com | 基于小智 AI 的 AI 语音助手 | 31

运行 python 文件。
python upload_xiaozhi_bin.py

代码上传完成，如下图所示。

ESP32 S3 WROOM 显示如下。

32 | 基于小智 AI 的 AI 语音助手 | www.freenove.com █

## ESP32 S3 WROOM 配网

如果您的 ESP32 S3 WROOM 还没有集成小智 AI 固件，请跳转到小智 AI 固件。
如果您想学习小智 AI 的代码，请跳转到小智 AI 代码, 请跳转到小智 AI 代码。
如果您的 ESP32 S3 WROOM 已经集成了小智 AI 的固件，请使用您的手机，打开 WiFi 功能，您可以搜索到 一个叫“Xiaozhi-XXXX”的路由器 WiFi。请连接它，它是无密码的。

连接 WiFi 后，请按照提示点击它。它将会打开您的手机浏览器，并访问“192.168.4.1”这个网址。

█ www.freenove.com | 基于小智 AI 的 AI 语音助手 | 33

在SSID中输入您的家庭路由器WiFi名称，在Password中输入您的家庭路由器WiFi密码。然后点击Connect。 请注意，ESP32 S3 WROOM 只接收 2.4GHz 频段的路由器，如果您的路由器同时支持 2.4GHz 和 5GHz，请 注意，不能让 ESP32 S3 WROOM 连接 5Ghz 频段。也不能将 2.4Ghz 和 5Ghz 设置为混合模式。这都会导致 ESP32 S3 WROOM 无法正常联网工作。


当您看到这个界面时，说明您已经成功让 ESP32 S3 Wroom 配网成功，它将会加入您的家庭路由器 WiFi 网 络中。您可以看到 ESP32 S3 WROOM 自动连接 WiFi，然后屏幕显示如下图所示。


34 | 基于小智 AI 的 AI 语音助手 | www.freenove.com █

## 配置小智 AI 服务器

请确保您的手机或者电脑和 ESP32 S3 WROOM 连接到同一个路由器 WiFi 网络中。

█ www.freenove.com | 基于小智 AI 的 AI 语音助手 | 35

如果您还没有账号，请先注册一个账号，并登陆它。

点击 Console，开始配置小智 AI 服务器。

36 | 基于小智 AI 的 AI 语音助手 | www.freenove.com █

点击“Create Agent”，创建一个新的智能体。

填写任意名称。点击“Confirm”。

█ www.freenove.com | 基于小智 AI 的 AI 语音助手 | 37

点击“Configure Role”，配置您的智能体。

点击“English Tutor”，其他选项内容保持不变。

38 | 基于小智 AI 的 AI 语音助手 | www.freenove.com █

滚动鼠标，将界面移动到最底部，点击“Save”。

点击“Agents”回到智能体界面，然后点击”Add Device”。

█ www.freenove.com | 基于小智 AI 的 AI 语音助手 | 39

在新弹出的界面中，填写 ESP32 S3 WROOM 屏幕的数字。然后点击“Confirm”。

添加完成后，界面如下。

40 | 基于小智 AI 的 AI 语音助手 | www.freenove.com █

点击 ESP32 S3 WROOM 上的 RST 按键。它将让 ESP32 S3 WROOM 重新启动。

至此，您已经完成小智 AI 的全部工作。对着麦克风说，“Hi, ESP”。

您可以和它进行中文，英文交流。

█ www.freenove.com | 小智 AI 代码 | 41

# 小智 AI 代码

## Visual Studio Code

## Window

首先，我们需要先下载 Visual Studio Code，请访问 https://code.visualstudio.com/Download。选择适合您电 脑平台的版本，下载并安装它。

42 | 小智 AI 代码 | www.freenove.com █

双击运行下载的 exe 文件。勾选”I accept the agreement”。然后点击 next.

安装的位置可以保持默认选项，也可以自行修改到合适的位置。然后一直点击 Next。

█ www.freenove.com | 小智 AI 代码 | 43

在这个界面时，请注意查看“Add to PATH”是否勾选中，如果没有，请勾选它。然后一直点击 Next，直到软 件安装完成。

安装完成如下图所示。

## MAC


44 | 小智 AI 代码 | www.freenove.com █

通常，MAC 系统自带 Visual Studio Code，如果您的电脑没有 Visual Studio Code，请先安装它。 请访问 https://code.visualstudio.com 并点击“Download for macOS”.

双击运行它。

## Linux


█ www.freenove.com | 小智 AI 代码 | 45

如果您的电脑没有 Visual Studio Code，请先安装它。 请访问 https://code.visualstudio.com。并点击“.deb”. (https://code.visualstudio.com/Download)

打开下载的“code_xxx.deb”文件。

46 | 小智 AI 代码 | www.freenove.com █

点击“Install”，安装 Visual Studio Code.

等待安装完成，安装完成如下图所示。

█ www.freenove.com | 小智 AI 代码 | 47

点击 Show Apps，可以看到，Visual Studio Code 已经出现在系统中。

## 安装 ESP-IDF V5.3.2

48 | 小智 AI 代码 | www.freenove.com █

Visual Studio Code 是一个通用的代码编辑器，为了编程 ESP-IDF 的 SDK，我们需要给 Visual Studio Code 安 装一个 ESP-IDF 插件。
打开 Visual Studio Code。
Window 系统和 Linux 系统：点击菜单栏的“File”->”Preferences”->”Extensions”.

Mac 系统：点击屏幕左上方的“Code”->”Preferences”->”Extensions”.

█ www.freenove.com | 小智 AI 代码 | 49

输入“ESP-IDF”，点击搜索出来的“ESP-IDF”，然后点击右边的“Install”。

在左边可以看到出现了一个“ESP-IDF”的图标。点击它。

滚动鼠标，找到并点击“Advanced”。

50 | 小智 AI 代码 | www.freenove.com █

点击第一个选项，“Configure ESP-IDF Extension”。

在右边选择“EXPRESS”。

█ www.freenove.com | 小智 AI 代码 | 51

注意：如果您是 MAC 系统或者 Ubuntu 系统，请根据提示做好准备工作再进行安装。

52 | 小智 AI 代码 | www.freenove.com █

勾选“Show all ESP-IDF tags”，选择”v5.3.2 (release version)”，并选择您的 ESP-IDF 环境将要保存的位置。 然后点击“Install”。不同的系统保存的路径不同，请记住这些存放路径。

等待安装完成即可。如果您安装失败了，请找到上一步中的路径，删除对应的文件夹，并重新开始安装。

这一步需要等待一段较长的时间，请确保您的网络良好，且网速较快。

█ www.freenove.com | 小智 AI 代码 | 53

如果您始终无法正常安装，根据您的电脑系统，查看对应的链接：
Window: https://docs.espressif.com/projects/esp-idf/en/latest/esp32/get-started/windows-setup.html (https://docs.espressif.com/projects/esp-idf/en/latest/esp32/get-started/windows-setup.html)
Mac & Linux: https://docs.espressif.com/projects/esp-idf/en/latest/esp32/get-started/linux-macos-setup.html (https://docs.espressif.com/projects/esp-idf/en/latest/esp32/get-started/linux-macos-setup.html)

插件安装完成如下图所示。


更多关于 ESP-IDF 的消息，请访问：
https://docs.espressif.com/projects/vscode-esp-idf-extension/en/latest/installation.html

## 下载代码


54 | 小智 AI 代码 | www.freenove.com █

Window

打开浏览器，输入“https://github.com/Freenove/xiaozhi-esp32”。

点击“Code”，然后点击“Dowmload ZIP”，将代码下载到本地。

█ www.freenove.com | 小智 AI 代码 | 55

将下载的压缩文件解压到本地。请注意，将解压后的文件夹重命名为“xiaozhi-esp32”。

MAC

打开终端，使用 git 下载代码。
git clone https://github.com/Freenove/xiaozhi-esp32.git

Linux

打开终端，使用 git 下载代码。
git clone https://github.com/Freenove/xiaozhi-esp32.git

## 配置代码环境

56 | 小智 AI 代码 | www.freenove.com █

解压下载的文件
使用 Visual Studio Code，点击“File”->”Open Folder...”。

选择 xiaozhi-esp32 文件夹。这里以 Window 系统举例，在 MAC 系统和 Ubuntu 系统上的操作类似。

█ www.freenove.com | 小智 AI 代码 | 57

勾选复选框，并点击”Yes，I trust the authors of all files in the parent floder ‘Downloads’”。

请注意，右下角会弹出一个提示框，请点击“Generate comple_commands.json”，它将根据文件下载对应的 组件模块代码。

58 | 小智 AI 代码 | www.freenove.com █

组件安装需要一些时间，请注意等待，不要进行其他操作。组件安装完成会在右下角打印提示。

使用数据线连接电脑和 ESP32 S3 WROOM，请注意，不要连接错 Type C 接口。

点击左下角的 COMx，在上方会出现电脑上所有的 COM 设备端口号。找到 ESP32-S3，并选择那一项。

█ www.freenove.com | 小智 AI 代码 | 59

点击左下角的 ESP32，在上方会出现很多 ESP32 型号，选择 ESP32S3。

在新的选择框中，选择“ESP32-S3 Chip (via ESP-PROG) ESP32-S3 debugging via ESP-PROG Board ...”。

60 | 小智 AI 代码 | www.freenove.com █

请等待一会，直到下方出现“Target ESP32S3 Set Successfully.”的提示。

接下来点击 SDK Configuration Editor (menuconfig)选项。

█ www.freenove.com | 小智 AI 代码 | 61

在新的界面中，点击“Serial flasher config”，并检查配置是否和下图一致。

点击“Partition Table”，并检查配置是否和下图一致。


62 | 小智 AI 代码 | www.freenove.com █

点击“Xiao Assistant”，并检查配置是否和下图一致。

到目前为止，在本教程撰写之时，Freenove_Media_Kit_for_ESP32-S3 有两个不同的型号，它们的屏幕大小 不同，但是您都可以通过本教程来学习如何使用它们, 请根据您手上 Freenove_Media_Kit_for_ESP32-S3 的 屏幕大小来选择“Board Type” (3.5inch 即将推出)

█ www.freenove.com | 小智 AI 代码 | 63

点击 Load Multiple Wake Words”，并勾选“Hi, ESP”、“Hi, Lily”等选项。


64 | 小智 AI 代码 | www.freenove.com █

最后，点击”Save”，保存您的配置。保存成功，下方会给出提示信息。

## 编译代码

█ www.freenove.com | 小智 AI 代码 | 65

确保一切都配置完成之后，我们开始编译代码。
点击下方的“Full Clean”，它将会清除之前的所有编译信息。

点击下方的“Build Project”，开始编译整个工程代码。首次编译需要等待的时间较长，请耐心等待，直到下方 出现编译成功的提示。

66 | 小智 AI 代码 | www.freenove.com █

点击下方的“Flash Device”。准备开始上传代码到 ESP32 S3 Wroom 中。

在新出现的选项中，选择“UART”，然后等待代码上传完成即可。

看到“Flash has finished. You can monitor your device with 'ESP-IDF: Monitor command'”的提示，说明您已 经将小智 AI 的代码上传到 ESP32 S3 WROOM 中。

至此，您已经编译完成，可以进行二次创作了。

█ www.freenove.com | 本地服务器 | 67

# 本地服务器

## 小智 AI 服务器使用声明

本项目基于网络开源项目https://github.com/xinnan-tech/xiaozhi-esp32-server。该项目开源协议类型为MIT 协议。我们仅在此基础上提供适配，用做第三方学习和 AI 功能试用，不做商业性质推广和应用。本教程仅 给爱好者附加学习使用。

## 小智 AI 本地服务器部署

如果您不想使用小智 AI 服务器，您也可以使用自己的电脑搭建一个简易版本的服务器，这个章节我们将使 用开源项目 https://github.com/xinnan-tech/xiaozhi-esp32-server 来部署一个本地服务器，并和 ESP32 S3 WROOM 建立连接。如果您在使用过程中发现代码存在 bug，请在 https://github.com/xinnan-tech/xiaozhi-esp32-server (https://github.com/xinnan-tech/xiaozhi-esp32-server) 上提交 issue，我们对此项目并不进入深入了解，无法为您提供太多帮助。

## 安装 Ollama

Window

在开始之前，我们需要在本地先安装 Ollama 工具，它可以在我们的电脑上安装任意开源模型。 如果您还没有安装 Ollama，请访问 https://ollama.com/download 进行下载和安装。

68 | 本地服务器 | www.freenove.com █

运行 Ollama 安装包，点击 Install.

安装完成后，您可以在电脑的右下角看到图标。

回到电脑的桌面位置，选择此电脑，按下鼠标右键，选择“Properties”.

█ www.freenove.com | 本地服务器 | 69

在新弹出的界面中，找到“Advances system settings”，然后点击它。

在新的窗口中，点击“Environment Variables”.

70 | 本地服务器 | www.freenove.com █

点击”New”.

变量名称输入“OLLAMA_HOST”，变量值输入“0.0.0.0:11434”，然后点击 OK。 这样局域网内所有的设备都可以通过 IP 地址访问 Ollama。否则只能电脑本身访问 Ollama.

█ www.freenove.com | 本地服务器 | 71

MAC

在开始之前，我们需要在本地先安装 Ollama 工具，它可以在我们的电脑上安装任意开源模型。 如果您还没有安装 Ollama，请访问 https://ollama.com/download 进行下载和安装。

在 Downloads 中找到“Ollama.app”，双击运行它。

点击”Next”，然后点击“Install”，最后点击“Finish”


72 | 本地服务器 | www.freenove.com █

安装完成后，界面会直接关闭。
打开终端，通过指令查看 Ollama 是否已经安装完成。 ollama --version

请注意，Ollama 存放在 Applications 中。如上图所示，如果您的 Ollama 已经在运行，则运行“ollama --version” 时，会直接打印 Ollama 的版本号。如果您的 Ollama 没有运行，则运行“ollama --version”时，会提示您无法 连接到运行中的 Ollama.

Linux

在开始之前，我们需要在本地先安装 Ollama 工具，它可以在我们的电脑上安装任意开源模型。 如果您还没有安装 Ollama，请访问 https://ollama.com/download 进行下载和安装。

█ www.freenove.com | 本地服务器 | 73

打开终端。输入指令，开始安装 Ollama.

安装完成如下图所示。当然，您可以使用“ollama --version”查看是否已经安装 Ollama.


74 | 本地服务器 | www.freenove.com █

LLM 模型

请访问 https://ollama.com/search，选择适合您电脑的，或者您喜欢的 LLM 模型。

这里我以 qwen2.5 举例。点击“qwen2.5”模型。

█ www.freenove.com | 本地服务器 | 75

请注意，在选择模型时，需要根据您的电脑显卡内存或者 CPU 内存条配置，选择合适的模型。 1，模型越大，智能化程度越高。模型越小，智能化程度越低。 2，如果您的配置比较高，您可以选择比较大的模型，如果您的电脑配置比较低，您可以选择比较小的模 型。
3，如果您的电脑配置较低，而您选择的模型过大，可能会导致模型无法运行，或者运行的速度变慢。 通过下拉框，可以选择合适的模型参数。

模型越小，越不智能，但是运行速度越快，这里只是作为演示，我们选择 qwen2.5:0.5b 来作为示范。复制 网页中的指令：“ollama run qwen2.5:0.5b”

76 | 本地服务器 | www.freenove.com █

接下来请根据您的电脑系统，安装您喜欢的 LLM 模型。

Window

您可以使用指令“Win+R”，在弹出的窗口中输入“CMD”，打开 CMD 界面。

输入指令“ollama --version”，查看是否已经安装了 ollama。

输入“ollama run qwen2.5:0.5b”，将模型下载到本地中。

█ www.freenove.com | 本地服务器 | 77

MAC

打开终端，输入指令“ollama --version”，查看是否已经安装了 ollama。

如果出现“Warning: could not connect to a running Ollama instance”的提示，请先运行 Ollama.

重新使用指令，查看 Ollama 是否正常运行。

输入“ollama run qwen2.5:0.5b”，将模型下载到本地中。

78 | 本地服务器 | www.freenove.com █

当安装完成后，你可以直接在终端界面中和 qwen2.5:0.5b 进行聊天。

您可以使用指令“Ctrl+d”，退出聊天模式。

您可以通过指令“ollama serve”来运行 ollama 服务器。

如果您的 Ollama 已经运行，则会提示您下面的界面。

您可以输入 Ollama，查看 Ollama 的使用说明。

█ www.freenove.com | 本地服务器 | 79

Linux

打开终端，输入指令“ollama --version”，查看是否已经安装了 ollama。

输入“ollama run qwen2.5:0.5b”，将模型下载到本地中。

当安装完成后，你可以直接在终端界面中和 qwen2.5:0.5b 进行聊天。

您可以使用指令“Ctrl+d”，退出聊天模式。

80 | 本地服务器 | www.freenove.com █

您可以输入 Ollama，查看 Ollama 的使用说明。

## 安装 Conda

█ www.freenove.com | 本地服务器 | 81

xiaozhi-esp32-server 这个开源项目提供了 4 (https://github.com/xinnan-tech/xiaozhi-esp32-server%20提供了4) 种安装方式，在本教程中，我们选择最简单的配置示例作为示 范，其他使用方法请参考网站进行探索学习。

Window

本示例使用 conda 管理依赖环境。因此我们需要事先在电脑上安装 Conda 环境。如果您的电脑还没安装 Conda，您可以访问这个链接下载并安装它：https://www.anaconda.com/download/success 选择适合您电脑平台的软件包下载。Miniconda is an installer by Anaconda that comes preconfigured for use with the Anaconda Repository.

双击打开 Conda 软件，点击 Next.


82 | 本地服务器 | www.freenove.com █

点击“I Agree”.

根据需求，选择合适的安装类型，一般我们选择“All Users”.

█ www.freenove.com | 本地服务器 | 83

选择安装软件的位置。

保持默认即可。点击 Install。


84 | 本地服务器 | www.freenove.com █

等待安装，可能需要等待一小会。

至此，软件就安装完成了。

█ www.freenove.com | 本地服务器 | 85

您可以使用“Win+R”打开 Run 界面。输入“CMD”，并按下回车键，进入 CMD 界面。

输入“conda --version”，并按下回车键。如果您的 Anaconda3 已经安装完成，您可以看到下面的提示信息。

MAC

本示例使用 conda 管理依赖环境。因此我们需要事先在电脑上安装 Conda 环境。如果您的电脑还没安装 Conda，您可以访问这个链接下载并安装它：https://www.anaconda.com/download/success 选择适合您电脑平台的软件包下载。Miniconda is an installer by Anaconda that comes preconfigured for use with the Anaconda Repository.


86 | 本地服务器 | www.freenove.com █

双击打开 Conda 软件，点击 Continue.

点击 Continue.

█ www.freenove.com | 本地服务器 | 87

点击 Continue.

点击 Agree.

88 | 本地服务器 | www.freenove.com █

保持默认，点击 Continue.

点击 Install.


█ www.freenove.com | 本地服务器 | 89

这里需要等待几分钟。

点击 Continue.

90 | 本地服务器 | www.freenove.com █

点击 Close.

至此，您可以安装了 Conda。您可以在您的应用列表中找到它。

█ www.freenove.com | 本地服务器 | 91

双击运行它，这一步不会有任何现象。
再次打开终端。您可以发现，出现了”(base)”的提示词。您也可以通过指令“conda --version”查看 conda 的 版本。

您可以使用 conda -h 来查看更多的使用方法。

如果您是第一次使用 conda，您需要使用指令“conde init”，让安装的 conda 环境初始化并生效。 conda init
您可以使用 conda activate 来激活虚拟环境。或者通过 conda deactivate 来退出虚拟环境。 conda activate
conda deactivate

如果您想要打开终端就自动进入虚拟环境，您可以使用“conda config --set auto_activate_base true”指令。 如果您不想要打开终端就自动进入虚拟环境，您可以使用“conda config --set auto_activate_base flase”指令。 conda config --set auto_activate_base false
conda config --set auto_activate_base true

92 | 本地服务器 | www.freenove.com █

Linux

本示例使用 conda 管理依赖环境。因此我们需要事先在电脑上安装 Conda 环境。如果您的电脑还没安装 Conda，您可以访问这个链接下载并安装它：https://www.anaconda.com/download/success 选择适合您电脑平台的软件包下载。Miniconda is an installer by Anaconda that comes preconfigured for use with the Anaconda Repository.

此处我下载的文件名称为“Anaconda3-2024.10-1-Linux-x86_64.sh”，不同的电脑，名称可能不同。 打开终端，使用下面的指令安装 Anaconda。
sh Anaconda3-2024.10-1-Linux-x86_64.sh

█ www.freenove.com | 本地服务器 | 93

按住回车键不松开，直到出现下方的的提示信息。输入“Yes”。

选择您的安装位置。按下回车键，使用默认安装位置即可。

安装过程需要网络，请确保您的网络稳定，并耐心等待几分钟。直到您的界面出现下方的提示信息。 请注意，这里需要输入 Yes.

Yes

94 | 本地服务器 | www.freenove.com █

出现下方的提示，说明您已经成功安装 conda.

如果您想要打开终端就自动进入虚拟环境，您可以使用“conda config --set auto_activate_base true”指令。 如果您不想要打开终端就自动进入虚拟环境，您可以使用“conda config --set auto_activate_base flase”指令。 conda config --set auto_activate_base false
conda config --set auto_activate_base true
这里，我们建议使用“conda config --set auto_activate_base false”。

重启终端，您可以通过指令查看 conda 的版本号。
conda –version

您可以使用 conda activate 来激活虚拟环境。或者通过 conda deactivate 来退出虚拟环境。 conda activate
conda deactivate

█ www.freenove.com | 本地服务器 | 95

如果您查看 conda 的版本号时报错如下。
conda –version

这说明您的文件 Conda 虽然已经安装，但是没有添加到 PATH 中。 请按照下面的步骤将 conda 添加到 PATH 中。
使用 nano 编辑”.bashrc”文件.
cd ~
sudo nano ./.bashrc

在文件的最下方，添加一行内容。
export PATH=”$HOME/anaconda3/bin:$PATH”

使用 Ctrl+O 保存文件，使用 Ctrl+X 退出编辑器。
使用 source 指令，让文件生效。并查看 conda 的版本。 source ./.bashrc
conda --version

## 部署虚拟环境

96 | 本地服务器 | www.freenove.com █

请注意，部署虚拟环境的指令，在 Window，MAC，Ubuntu 中是通用的，这里以 Window 举例，其他平 台操作相同。

打开 CMD 界面，使用指令创建一个带有 python3.10 的虚拟环境，并命名为“xiaozhi-esp32-server” conda create -n xiaozhi-esp32-server python=3.10 -y

当看到下面的消息，说明虚拟环境已经创建完成。

█ www.freenove.com | 本地服务器 | 97

如果您想删除这个虚拟环境，请使用下面的指令。
conda remove -n xiaozhi-esp32-server --all -y

同样，您随时可以使用这两个指令，开启和关闭虚拟环境： conda activate xiaozhi-esp32-server
conda deactivate

请注意，有时候使用开启虚拟环境会提示您需要使用“conda init”指令。请执行它，并重启终端。

## 部署 xiaozhi-esp32-server 服务器

98 | 本地服务器 | www.freenove.com █

如果您是 Window 用户，请打开 CMD 界面。如果您是 MAC 或者 Ubuntu 用户，请打开终端。接下来的教 程以 window 系统配图作为示例，有不同之处，我们会附上其他系统图片作为补充解释。

激活虚拟环境。
conda activate xiaozhi-esp32-server

在虚拟环境中安装 libopus。
conda install libopus -y

在虚拟环境中安装 ffmpeg。
conda install ffmpeg -y


█ www.freenove.com | 本地服务器 | 99

在虚拟环境中在虚拟环境中安装 git.
conda install git -y

使用 git clone 指令下载服务器源码。
git clone https://github.com/Freenove/xiaozhi-esp32-server.git

100 | 本地服务器 | www.freenove.com █

进入服务器源码文件夹。
如果您是 window 用户，请注意路径是反斜杠。
cd xiaozhi-esp32-server\main\xiaozhi-server

如果您是 mac 用户或者 Linux 用户，请注意路径是正斜杠。 cd xiaozhi-esp32-server/main/xiaozhi-server

安装服务器源码需要的库环境。这个步骤需要较长一段时间，请确保您的网络良好，不要退出安装。 pip config set global.index-url https://mirrors.aliyun.com/pypi/simple/
pip install -r requirements.txt

安装完成如下图所示。


█ www.freenove.com | 本地服务器 | 101

下载声音模型。
git clone https://www.modelscope.cn/iic/SenseVoiceSmall.git

使用复制指令，将 SenseVoiceSmall 中的 model.pt 文件拷贝到 models/SenseVoiceSmall 文件夹中。 如果您是 window 用户，使用 copy 指令。
copy .\SenseVoiceSmall\model.pt .\models\SenseVoiceSmall\

如果您是 mac 用户或者 Linux 用户，使用 cp 指令。
cp ./SenseVoiceSmall/model.pt ./models/SenseVoiceSmall/

在 CMD 界面中输入“mkdir data && copy config.yaml data\.config.yaml”，它将在 xiaozhi-server 中创建 一个文件夹并命名为“data”，并将当前目录下的“config.yaml”复制到“data”文件夹下，然后命名为 “.config.yaml”。
如果您是 window 用户，请执行这个指令。
mkdir data && copy config.yaml data\.config.yaml

如果您是 MAC/Linux 用户，请执行这个指令。 mkdir data && cp config.yaml data/.config.yaml

102 | 本地服务器 | www.freenove.com █

打开并修改.config.yaml 文件。
如果您是 window 用户，请执行这个指令。
code .\data\.config.yaml
如果您是 MAC/Linux 用户，请执行这个指令。
code ./data/.config.yaml
注意：如果您的 Vscode 没有正确安装，使用指令可能会报错。您同样可以手动使用 Vscode 打开这个文 件。
找到“selected_module:”，将其中的“LLM: ChatGLMLLM”修改为“LLM: OllamaLLM”


█ www.freenove.com | 本地服务器 | 103

找到”LLM:”中的“OllamaLLM:”，将其中的“model_name: qwen2.5”修改为“model_name: qwen2.5:0.5b”.

请注意：为确保您能够顺利使用小智 AI 的视觉识别功能，请按照以下步骤配置视觉识别大模型（VLLM）； 若您当前无需使用该功能，则可直接跳过此步骤继续后续操作。
继续修改 config.yaml 文件，先按照提示步骤注册对应的 api key，再将生成的 api key 填入到代码中

保存文件并退出。
当然，您可以也选择其他模型，比如默认的 ChatGLMLLM。请注意，配置不同的 LLM 模型需要您自行探索 并配置。

点击链接并注册账号

在网站上申请一个
api key 并填写在此处

104 | 本地服务器 | www.freenove.com █

运行 xiaozhi-esp32-verser 代码。
python app.py

请注意，此时，服务器会打印一个访问端口。记住它，后面的教程需要用到。

此时，您可以使用浏览器，打开“xiaozhi-esp32-server\main\xiaozhi-server\test”中的 html 文件。 测试步骤如下所示。

点击“连接”.

█ www.freenove.com | 本地服务器 | 105

您可以在文本框中输入任意内容，并点击发送，测试 xiaozhi-esp32-server 是否正常运行。

106 | 本地服务器 | www.freenove.com █

如果服务器正常工作，您可以和它进行聊天。

█ www.freenove.com | 本地服务器 | 107

请注意，必须同时运行 xiaozhi-esp32-server 和 Ollama，如果您的 Ollama 没有运行，您可以看到如下方所 示的提示。

您可以查看 LLM 模型来运行 Ollama。

## ESP32S3 访问 xiaozhi-esp-server 服务器

108 | 本地服务器 | www.freenove.com █

请注意，前面的代码中，我们讲解了小智 AI 代码的配置，在这个章节中，我们需要对工程的配置进行修 改，从而让 ESP32S3 可以访问 xiaozhi-esp32-server 本地服务器。
打开 Visual Studio Code，选择之前的 xiaozhi-esp32 工程。点击 SDK Configuration Editor (menuconfig)。

将 Connection Type 设置为“Websocket”，并填写 xiaozhi-esp32-server 打印的服务器端口链接。

点击保存，然后重新编译代码。如下所示。

█ www.freenove.com | 本地服务器 | 109

在界面下方点击“Build Project”，编译代码。

在界面下方点击“Flash Device”，将代码上传到 ESP32S3 中。

至此，您已经完成小智 AI 的全部工作。对着麦克风说，“Hi, ESP”。您就可以和本地服务器进行聊天。

请注意，本地服务器对电脑的配置要求较高，如果您的电脑配置不高，您可以考虑将 LLM 模型选择大公司 开放的 LLM 接口。这样对电脑的配置相对要低很多。

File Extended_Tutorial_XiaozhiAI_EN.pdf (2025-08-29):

█ www.freenove.com | Contents | 1

# Contents

2 | AI Voice Assistant Based on XiaoZhi AI | www.freenove.com █

# AI Voice Assistant Based on XiaoZhi AI

This project applies the Media Kit to implement an AI voice assistant, which requires a certain level of programming proficiency as well as familiarity with ESP-IDF and open-source large models.

## About the Project

This voice assistant project (https://github.com/Freenove/xiaozhi-esp32) is derived from the open-source project (https://github.com/78/xiaozhi-esp32 ). It enables the invocation of most mainstream large language models (LLMs) on embedded devices and achieves voice conversation functionality through multiple services, including Voice Activity Detection (VAD), Automatic Speech Recognition (ASR), Speech-to-Text (STT), Text-to-Speech (TTS), Memory Storage, and Intent Recognition. Freenove has adapted this project for its Media Kit product. This article will explain how to run the project on the Media Kit.

There are two ways to run this project – online or offline.
1. Online: Connected to the xiaozhi.me server, currently available for free trial to individual users.
2. Offline: All the aforementioned services (VAD, ASR, STT, TTS, Memory, Intent Recognition, etc.) must be deployed locally on a personal computer. The user experience depends entirely on the selected models and the performance of the local machine. The local server project (https://github.com/Freenove/xiaozhi-esp32-server) (https://github.com/Freenove/xiaozhi-esp32-server) is derived from the open-source project (https://github.com/xinnan-tech/xiaozhi-esp32-server).

For users who prefer AI assistants, we recommend using the online version.
For developer-oriented users, you can try deploying the offline version to gain a deeper understanding of the various services required for an AI assistant. However, it's important to note that personal computers may struggle to run all these services simultaneously—especially the core LLM (Large Language Model) service— which could result in a poor AI assistant experience. Therefore, the offline version is primarily valuable for learning and research purposes.

## Cautions

⚫ | Project Copyright:
⚫ | Voice Assistant Project: Originally developed by "Xiage", this project was forked and adapted by
Freenove for the Media Kit, released under MIT License.
⚫ Local Server Project: Originally created by "xinnan-tech", this project was similarly forked and adapted by Freenove for Media Kit integration, licensed under MIT License.
⚫ | Supprted Countries and Regions:
⚫ | Online Version:
Service availability is determined by xiaozhi.me server coverage, which may exclude certain regions. For current supported areas, please refer to: https://xiaozhi.me/login?redirect=/console/agents; User experience is directly affected by server connectivity quality. Poor network conditions to xiaozhi.me servers may degrade performance.

█ www.freenove.com | AI Voice Assistant Based on XiaoZhi AI | 3
⚫ | Offline Version:
Fully location-independent, with deployment possible in all countries and regions without geographical restrictions.
⚫ | Supported Languages：
⚫ | Online Version: Currently supports Mandarin Chinese, Cantonese, English, Japanese, Korean, and
others. If you do not speak these languages, you may not be able to communicate effectively with XiaoZhi AI.
⚫ Offline Version: Depending on the ASR model you deploy. The default FunASR model only supports Mandarin Chinese, Cantonese Chinese, English, Japanese and Korean.
⚫ | Pricing:
⚫ | Online Version: Currently, xiaozhi.me provides free services, but we cannot guarantee that the
online server will remain free indefinitely.
⚫ Offline Version: Among the sub-services mentioned, some are paid while others are free—your choice determines the cost.
⚫ Seeking Help:
If you have followed the tutorial and still encounter issues, please contact us at support@freenove.com Note: Since the online service is provided by xiaozhi.me, if xiaozhi.me discontinues its service, we will also remove related documentation, tutorials, and code.

## Disclaimer

This implementation is an adaptation of the open-source project available at https://github.com/78/xiaozhi-esp32, (https://github.com/78/xiaozhi-esp32) provided for third-party learning and AI functionality testing purposes, without any promotion or support for commercial applications. This tutorial is intended solely for personal learning and development by technology enthusiasts.
Notes:
1. As this is a third-party open-source project, if you encounter issues during your learning process, please submit an issue to the original repository: https://github.com/78/xiaozhi-esp32/issues
2. Currently, XiaoZhi AI only supports Mandarin Chinese, Cantonese, English, Korean, and Japanese for speech recognition. Other languages are not yet supported.
3. The XiaoZhi server interface currently supports English, Chinese, and Japanese only. Additionally, mobile registration is only available for users in the following countries (see the table below). Users from other countries cannot register yet.
In this project, the ESP32-S3 communicates with XiaoZhi AI server through WebSocket protocol for data exchange.

4 | AI Voice Assistant Based on XiaoZhi AI | www.freenove.com █
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

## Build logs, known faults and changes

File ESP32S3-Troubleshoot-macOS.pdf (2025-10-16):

## CH34x Driver Installation on macOS

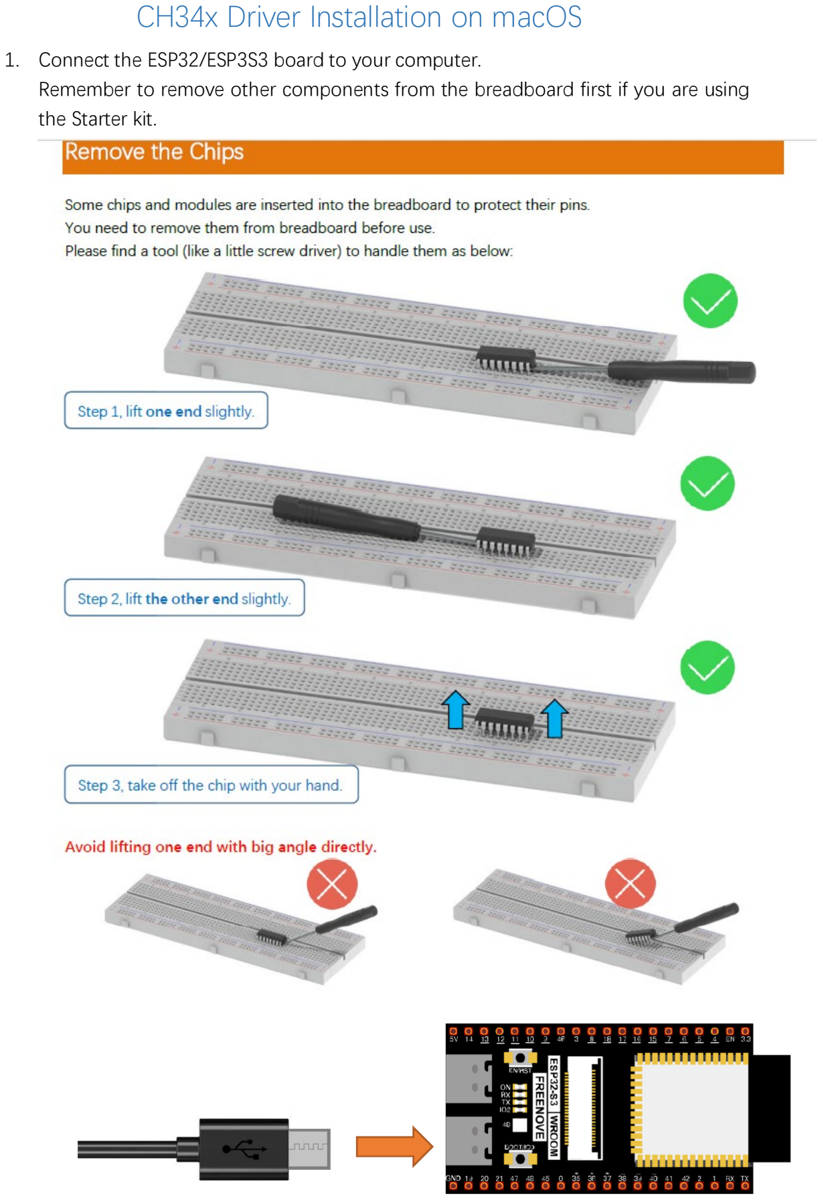
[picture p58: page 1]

1. Connect the ESP32/ESP3S3 board to your computer.
Remember to remove other components from the breadboard first if you are using the Starter kit.

2. Download the ch34x driver from WCH official. https://www.wch-ic.com/downloads/CH34XSER_MAC_ZIP.html
3. Open the CH34xVCPDriver.pkg to install the driver.

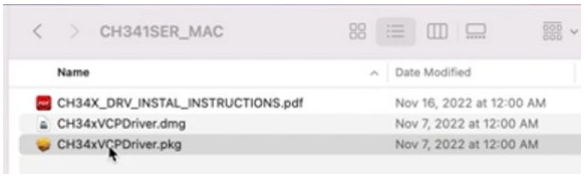
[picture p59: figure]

If it is blocked, please open Security Preferences to allow it.

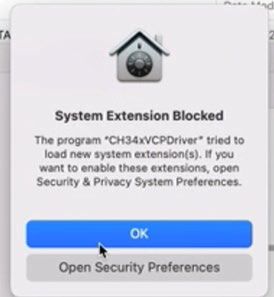
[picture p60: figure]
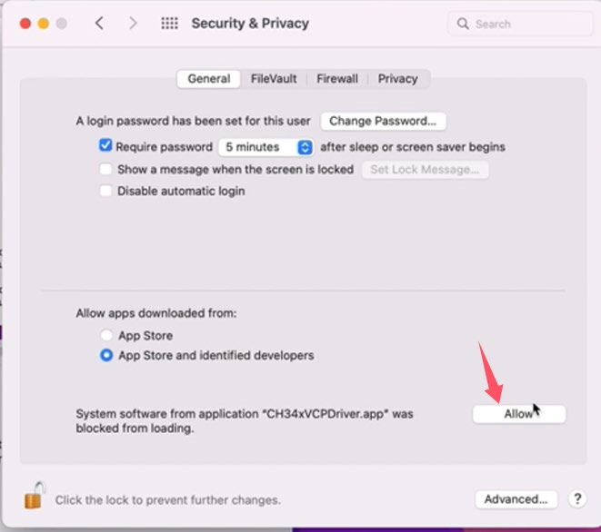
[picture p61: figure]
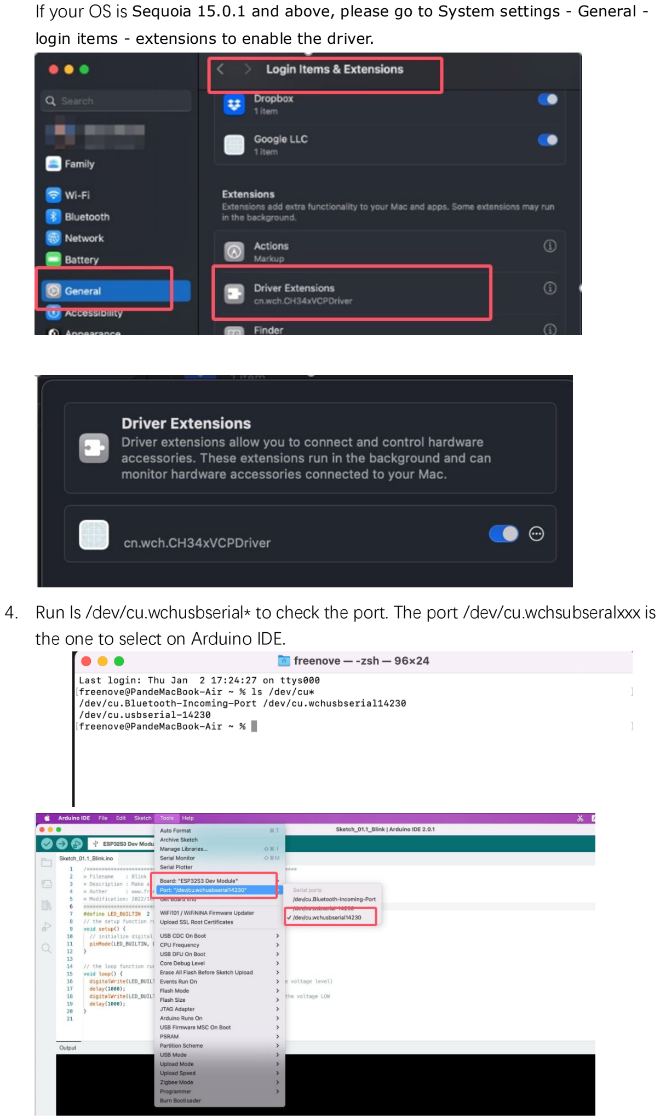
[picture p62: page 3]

If your OS is Sequoia 15.0.1 and above, please go to System settings - General -login items - extensions to enable the driver.

4. Run ls /dev/cu.wchusbserial* to check the port. The port /dev/cu.wchsubseralxxx is the one to select on Arduino IDE.

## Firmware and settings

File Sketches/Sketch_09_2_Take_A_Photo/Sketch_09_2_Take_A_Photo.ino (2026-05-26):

/*  
* Sketch_09_2_Take_A_Photo.ino
* This sketch captures images from an ESP32S3 Eye camera module and displays them on a TFT screen.
* It also allows taking photos by pressing a button and saving them to an SD card.
* 
* Author: Zhentao Lin
* Date:   2025-04-07
*/

#include <TFT_eSPI.h>
#include "esp_camera.h"
#include "driver_sdmmc.h"
#define CAMERA_MODEL_ESP32S3_EYE  // Has PSRAM
#include "camera_pins.h"
#include <ESP_I2S.h>

#ifdef FNK0102A_1P14_135x240_ST7789
  int screenWidth = 135;
  int screenHeight = 240;
#elif defined FNK0102B_3P5_320x480_ST7796
  int screenWidth = 320;
  int screenHeight = 480;
#endif

#define BUTTON_PIN 19  // Please do not modify it.
#define SD_MMC_CMD 38  // Please do not modify it.
#define SD_MMC_CLK 39  // Please do not modify it.
#define SD_MMC_D0 40   // Please do not modify it.
#define TFT_BL 20

I2SClass i2s_output; 

bool i2s_output_init(int bclk, int lrc, int dout) {
  i2s_output.setPins(bclk, lrc, dout, -1);
  if (!i2s_output.begin(I2S_MODE_STD, 16000, I2S_DATA_BIT_WIDTH_16BIT, I2S_SLOT_MODE_MONO, I2S_STD_SLOT_RIGHT)) {
    Serial.println("Failed to initialize I2S output bus!");
    return false;
  }
  i2s_output.write(0); 
  i2s_output.write(0); 
  i2s_output.end();
  return true;
}

// Global variable to track if we're using 3.5 inch screen
bool is35InchScreen = false;

TFT_eSPI tft = TFT_eSPI();

void camera_init(void);
void cameraShow(void);
void cameraPhoto(void);
void tft_rst(void);

void setup() {
  Serial.begin(115200);
  Serial.setDebugOutput(true);
  Serial.println();
  i2s_output_init(I2S_BCLK, I2S_LRC, I2S_DOUT);
  analogReadResolution(12);
  analogSetAttenuation(ADC_11db);
  pinMode(BUTTON_PIN, INPUT_PULLUP);

  // Check if we're using 3.5 inch screen
#ifdef FNK0102B_3P5_320x480_ST7796
  is35InchScreen = true;
#endif

  tft_rst();
  tft.init();
  if(is35InchScreen)
    tft.setRotation(1);            // Set the rotation of the TFT display
  else
    tft.setRotation(0);// Set the rotation of the TFT display
  camera_init();
  sdmmc_init(SD_MMC_CLK, SD_MMC_CMD, SD_MMC_D0);
  remove_dir("/video");
  create_dir("/video");
}

void loop() {
  cameraShow();   // Continuously display the camera feed on the TFT screen
  cameraPhoto();  // Check for button press to take a photo
}

void tft_rst(void) {
  pinMode(TFT_BL, OUTPUT);
  digitalWrite(TFT_BL, LOW);
  delay(50);
  digitalWrite(TFT_BL, HIGH);
  delay(50);
}

void camera_init(void) {
  camera_config_t config;
  config.ledc_channel = LEDC_CHANNEL_0;
  config.ledc_timer = LEDC_TIMER_0;
  config.pin_d0 = Y2_GPIO_NUM;
  config.pin_d1 = Y3_GPIO_NUM;
  config.pin_d2 = Y4_GPIO_NUM;
  config.pin_d3 = Y5_GPIO_NUM;
  config.pin_d4 = Y6_GPIO_NUM;
  config.pin_d5 = Y7_GPIO_NUM;
  config.pin_d6 = Y8_GPIO_NUM;
  config.pin_d7 = Y9_GPIO_NUM;
  config.pin_xclk = XCLK_GPIO_NUM;
  config.pin_pclk = PCLK_GPIO_NUM;
  config.pin_vsync = VSYNC_GPIO_NUM;
  config.pin_href = HREF_GPIO_NUM;
  config.pin_sccb_sda = SIOD_GPIO_NUM;
  config.pin_sccb_scl = SIOC_GPIO_NUM;
  config.pin_pwdn = PWDN_GPIO_NUM;
  config.pin_reset = RESET_GPIO_NUM;
  config.xclk_freq_hz = 10000000;
  
  // Set frame size based on screen type
  if (is35InchScreen) {
    config.frame_size = FRAMESIZE_HVGA;  // 320x240 for 3.5 inch screen
  } else {
    config.frame_size = FRAMESIZE_240X240;  // 240x240 for 1.14 inch screen
  }
  
  config.pixel_format = PIXFORMAT_RGB565;
  config.grab_mode = CAMERA_GRAB_WHEN_EMPTY;
  config.fb_location = CAMERA_FB_IN_PSRAM;
  config.jpeg_quality = 12;
  config.fb_count = 1;

  // Initialize the camera with the specified configuration
  esp_err_t err = esp_camera_init(&config);
  if (err != ESP_OK) {
    Serial.printf("Camera init failed with error 0x%x", err);
    return;
  }

  // Get the camera sensor and adjust settings
  sensor_t* s = esp_camera_sensor_get();
  uint16_t pid = s->id.PID;
  if(pid == OV2640_PID){
    s->set_hmirror(s, 0);
    s->set_vflip(s, 0);     
  }
  else if(pid == OV3660_PID){
    s->set_hmirror(s, 0);
    s->set_vflip(s, 1);     
  }
  else if(pid == GC2145_PID){
    s->set_hmirror(s, 1);
    delay(500);
    s->set_vflip(s, 1);      
  }
  else if(pid == GC0308_PID){
    s->set_hmirror(s, 0);
    delay(500);
    s->set_vflip(s, 0);     
  }
  else{
    s->set_hmirror(s, 0);
    s->set_vflip(s, 1);       
  }
  s->set_brightness(s, 1);  // Increase brightness
  s->set_saturation(s, 0);  // Decrease saturation
  s->set_ae_level(s, -3);   // Set exposure compensation level
}

void cameraShow(void) {
  // Capture a frame from the camera
  camera_fb_t *fb = esp_camera_fb_get();
  if (!fb) {
    Serial.println("Camera capture failed");
    return;
  }

  // For 3.5 inch screen, display directly without cropping
  if (is35InchScreen) {
    // Direct display when dimensions match
    tft.startWrite();
    tft.pushImage(0, 0, fb->width, fb->height, (uint16_t*)fb->buf);
    tft.endWrite();
  } 
  else {
    // For 1.14 inch screen, use original cropping logic
    int camWidth = fb->width;
    int camHeight = fb->height;

    // Calculate cropping area
    int cropWidth = screenWidth;
    int cropHeight = screenHeight;
    int cropStartX = (camWidth - cropWidth) / 2;
    int cropStartY = (camHeight - cropHeight) / 2;

    // Check if cropping is needed
    if (camWidth > screenWidth || camHeight > screenHeight) {
      // Allocate memory for cropped image
      uint16_t *croppedBuffer = (uint16_t *)malloc(cropWidth * cropHeight * sizeof(uint16_t));
      if (!croppedBuffer) {
        Serial.println("Failed to allocate memory for cropped image");
        esp_camera_fb_return(fb);
        return;
      }

      // Crop the image
      for (int y = 0; y < cropHeight; y++) {
        for (int x = 0; x < cropWidth; x++) {
          croppedBuffer[y * cropWidth + x] = ((uint16_t *)fb->buf)[(cropStartY + y) * camWidth + (cropStartX + x)];
        }
      }

      // Display cropped image on the TFT screen
      tft.startWrite();
      tft.pushImage(0, 0, cropWidth, cropHeight, croppedBuffer);
      tft.endWrite();

      // Free the cropped image buffer
      free(croppedBuffer);
    } else {
      // If camera size is less than or equal to screen size, display the image directly
      tft.startWrite();
      tft.pushImage(0, 0, camWidth, camHeight, fb->buf);
      tft.endWrite();
    }
  }

  // Return the frame buffer to the driver for reuse
  esp_camera_fb_return(fb);
}

void cameraPhoto(void) {
  static int fileCounter = 0;
  int analogValue = analogRead(BUTTON_PIN);
  if (analogValue < 100) {
    size_t _jpg_buf_len = 0;
    uint8_t *_jpg_buf = NULL;
    camera_fb_t *fb = esp_camera_fb_get();
    if (!fb) {
      Serial.println("Camera capture failed");
      return;
    }
    else {
      if (fb->format != PIXFORMAT_JPEG){
          bool jpeg_converted = frame2jpg(fb, 80, &_jpg_buf, &_jpg_buf_len);
          esp_camera_fb_return(fb);
          fb = NULL;
          if (!jpeg_converted){
              Serial.println("JPEG compression failed");
              if(_jpg_buf){
                  free(_jpg_buf);
                  _jpg_buf = NULL;
              }
              return;
          }
      }
      else{
        _jpg_buf_len = fb->len;
        _jpg_buf = fb->buf;
      }
    }
    char filename[32];
    snprintf(filename, sizeof(filename), "/video/photo_%04d.jpg", fileCounter);
    Serial.println(filename);
    write_jpg(filename, _jpg_buf, _jpg_buf_len);  // Save the photo to the SD card
    if(fb){
        esp_camera_fb_return(fb);
        fb = NULL;
        _jpg_buf = NULL;
    }
    else{
        free(_jpg_buf);
        _jpg_buf = NULL;
    }
    fileCounter++;
    list_dir("/video", 0);  // List the contents of the /video directory
    while (analogRead(BUTTON_PIN) < 3000);  // Wait for button release
  }
}

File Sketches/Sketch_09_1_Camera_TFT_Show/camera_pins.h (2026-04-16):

#if defined(CAMERA_MODEL_WROVER_KIT)
#define PWDN_GPIO_NUM    -1
#define RESET_GPIO_NUM   -1
#define XCLK_GPIO_NUM    21
#define SIOD_GPIO_NUM    26
#define SIOC_GPIO_NUM    27

#define Y9_GPIO_NUM      35
#define Y8_GPIO_NUM      34
#define Y7_GPIO_NUM      39
#define Y6_GPIO_NUM      36
#define Y5_GPIO_NUM      19
#define Y4_GPIO_NUM      18
#define Y3_GPIO_NUM       5
#define Y2_GPIO_NUM       4
#define VSYNC_GPIO_NUM   25
#define HREF_GPIO_NUM    23
#define PCLK_GPIO_NUM    22

#elif defined(CAMERA_MODEL_ESP_EYE)
#define PWDN_GPIO_NUM    -1
#define RESET_GPIO_NUM   -1
#define XCLK_GPIO_NUM    4
#define SIOD_GPIO_NUM    18
#define SIOC_GPIO_NUM    23

#define Y9_GPIO_NUM      36
#define Y8_GPIO_NUM      37
#define Y7_GPIO_NUM      38
#define Y6_GPIO_NUM      39
#define Y5_GPIO_NUM      35
#define Y4_GPIO_NUM      14
#define Y3_GPIO_NUM      13
#define Y2_GPIO_NUM      34
#define VSYNC_GPIO_NUM   5
#define HREF_GPIO_NUM    27
#define PCLK_GPIO_NUM    25

#elif defined(CAMERA_MODEL_M5STACK_PSRAM)
#define PWDN_GPIO_NUM     -1
#define RESET_GPIO_NUM    15
#define XCLK_GPIO_NUM     27
#define SIOD_GPIO_NUM     25
#define SIOC_GPIO_NUM     23

#define Y9_GPIO_NUM       19
#define Y8_GPIO_NUM       36
#define Y7_GPIO_NUM       18
#define Y6_GPIO_NUM       39
#define Y5_GPIO_NUM        5
#define Y4_GPIO_NUM       34
#define Y3_GPIO_NUM       35
#define Y2_GPIO_NUM       32
#define VSYNC_GPIO_NUM    22
#define HREF_GPIO_NUM     26
#define PCLK_GPIO_NUM     21

#elif defined(CAMERA_MODEL_M5STACK_V2_PSRAM)
#define PWDN_GPIO_NUM     -1
#define RESET_GPIO_NUM    15
#define XCLK_GPIO_NUM     27
#define SIOD_GPIO_NUM     22
#define SIOC_GPIO_NUM     23

#define Y9_GPIO_NUM       19
#define Y8_GPIO_NUM       36
#define Y7_GPIO_NUM       18
#define Y6_GPIO_NUM       39
#define Y5_GPIO_NUM        5
#define Y4_GPIO_NUM       34
#define Y3_GPIO_NUM       35
#define Y2_GPIO_NUM       32
#define VSYNC_GPIO_NUM    25
#define HREF_GPIO_NUM     26
#define PCLK_GPIO_NUM     21

#elif defined(CAMERA_MODEL_M5STACK_WIDE)
#define PWDN_GPIO_NUM     -1
#define RESET_GPIO_NUM    15
#define XCLK_GPIO_NUM     27
#define SIOD_GPIO_NUM     22
#define SIOC_GPIO_NUM     23

#define Y9_GPIO_NUM       19
#define Y8_GPIO_NUM       36
#define Y7_GPIO_NUM       18
#define Y6_GPIO_NUM       39
#define Y5_GPIO_NUM        5
#define Y4_GPIO_NUM       34
#define Y3_GPIO_NUM       35
#define Y2_GPIO_NUM       32
#define VSYNC_GPIO_NUM    25
#define HREF_GPIO_NUM     26
#define PCLK_GPIO_NUM     21

#elif defined(CAMERA_MODEL_M5STACK_ESP32CAM)
#define PWDN_GPIO_NUM     -1
#define RESET_GPIO_NUM    15
#define XCLK_GPIO_NUM     27
#define SIOD_GPIO_NUM     25
#define SIOC_GPIO_NUM     23

#define Y9_GPIO_NUM       19
#define Y8_GPIO_NUM       36
#define Y7_GPIO_NUM       18
#define Y6_GPIO_NUM       39
#define Y5_GPIO_NUM        5
#define Y4_GPIO_NUM       34
#define Y3_GPIO_NUM       35
#define Y2_GPIO_NUM       17
#define VSYNC_GPIO_NUM    22
#define HREF_GPIO_NUM     26
#define PCLK_GPIO_NUM     21

#elif defined(CAMERA_MODEL_M5STACK_UNITCAM)
#define PWDN_GPIO_NUM     -1
#define RESET_GPIO_NUM    15
#define XCLK_GPIO_NUM     27
#define SIOD_GPIO_NUM     25
#define SIOC_GPIO_NUM     23

#define Y9_GPIO_NUM       19
#define Y8_GPIO_NUM       36
#define Y7_GPIO_NUM       18
#define Y6_GPIO_NUM       39
#define Y5_GPIO_NUM        5
#define Y4_GPIO_NUM       34
#define Y3_GPIO_NUM       35
#define Y2_GPIO_NUM       32
#define VSYNC_GPIO_NUM    22
#define HREF_GPIO_NUM     26
#define PCLK_GPIO_NUM     21

#elif defined(CAMERA_MODEL_AI_THINKER)
#define PWDN_GPIO_NUM     32
#define RESET_GPIO_NUM    -1
#define XCLK_GPIO_NUM      0
#define SIOD_GPIO_NUM     26
#define SIOC_GPIO_NUM     27

#define Y9_GPIO_NUM       35
#define Y8_GPIO_NUM       34
#define Y7_GPIO_NUM       39
#define Y6_GPIO_NUM       36
#define Y5_GPIO_NUM       21
#define Y4_GPIO_NUM       19
#define Y3_GPIO_NUM       18
#define Y2_GPIO_NUM        5
#define VSYNC_GPIO_NUM    25
#define HREF_GPIO_NUM     23
#define PCLK_GPIO_NUM     22

#elif defined(CAMERA_MODEL_TTGO_T_JOURNAL)
#define PWDN_GPIO_NUM      0
#define RESET_GPIO_NUM    15
#define XCLK_GPIO_NUM     27
#define SIOD_GPIO_NUM     25
#define SIOC_GPIO_NUM     23

#define Y9_GPIO_NUM       19
#define Y8_GPIO_NUM       36
#define Y7_GPIO_NUM       18
#define Y6_GPIO_NUM       39
#define Y5_GPIO_NUM        5
#define Y4_GPIO_NUM       34
#define Y3_GPIO_NUM       35
#define Y2_GPIO_NUM       17
#define VSYNC_GPIO_NUM    22
#define HREF_GPIO_NUM     26
#define PCLK_GPIO_NUM     21


#elif defined(CAMERA_MODEL_ESP32_CAM_BOARD)
// The 18 pin header on the board has Y5 and Y3 swapped
#define USE_BOARD_HEADER 0 
#define PWDN_GPIO_NUM    32
#define RESET_GPIO_NUM   33
#define XCLK_GPIO_NUM     4
#define SIOD_GPIO_NUM    18
#define SIOC_GPIO_NUM    23
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

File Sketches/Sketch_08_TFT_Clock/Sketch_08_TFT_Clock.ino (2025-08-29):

/*
* Sketch_08_TFT_Clock.ino
* This sketch displays a clock on a TFT display using the TFT_eSPI library.
* It updates the time every second and draws hour, minute, and second hands.
* 
* Author: Zhentao Lin
* Date:   2025-04-07
*/

#include <TFT_eSPI.h>  // Graphics and font library for ST7735 driver chip
#include <SPI.h>

#ifdef FNK0102A_1P14_135x240_ST7789
  int screenWidth = 135;
  int screenHeight = 240;
#elif defined FNK0102B_3P5_320x480_ST7796
  int screenWidth = 320;
  int screenHeight = 480;
#endif

#define TFT_BL 20
#define TFT_DIRECTION 1  // Define the direction of the TFT display (0, 1, 2, or 3)

TFT_eSPI tft = TFT_eSPI();  // Invoke library, pins defined in User_Setup.h

#define TFT_GREY 0xBDF7  // Define a custom grey color for the background

// Display dimensions after rotation
int displayWidth, displayHeight;
// Calculate positions for clock and text
int clockCenterX, clockCenterY;
int textX, textY;
// Adjust clock radius based on the smaller screen dimension
int clockRadius;

// Variables to store the positions and angles of the clock hands
float sx = 0, sy = 1, mx = 1, my = 0, hx = -1, hy = 0;                // Saved H, M, S x & y multipliers
float sdeg = 0, mdeg = 0, hdeg = 0;                                   // Degrees for second, minute, and hour hands
uint16_t osx, osy, omx, omy, ohx, ohy;  // Saved H, M, S x & y coords
uint16_t x0 = 0, x1 = 0, yy0 = 0, yy1 = 0;                            // Temporary variables for drawing lines
uint32_t targetTime = 0;                                              // Time for the next second timeout

// Function to convert a two-character string to an integer
static uint8_t conv2d(const char *p) {
  uint8_t v = 0;
  if ('0' <= *p && *p <= '9')
    v = *p - '0';
  return 10 * v + *++p - '0';
}

// Get the current time from the compile time
uint8_t hh = conv2d(__TIME__), mm = conv2d(__TIME__ + 3), ss = conv2d(__TIME__ + 6);

bool initial = 1;  // Flag to indicate initial setup

// Initialize coordinates based on screen layout
void initializeDisplayParameters() {
  // After rotation, width and height are swapped
  if (TFT_DIRECTION == 1 || TFT_DIRECTION == 3) {
    displayWidth = screenHeight;
    displayHeight = screenWidth;
  } else {
    displayWidth = screenWidth;
    displayHeight = screenHeight;
  }
  
  // 根据屏幕尺寸调整布局比例
  float layoutRatio = 0.0;
  if (displayWidth >= 320) {
    // 3.5寸屏幕，使用较小的布局比例
    layoutRatio = 0.35;
  } else {
    // 1.14寸屏幕，使用较大的布局比例
    layoutRatio = 0.45;
  }
  
  // 将时钟放在左侧区域的中心
  clockCenterX = displayWidth * 0.3;  // 30%的位置
  clockCenterY = displayHeight / 2;
  
  // 将文字放在最右侧区域，确保完全超出时钟范围
  textX = displayWidth * 0.8;  // 80%的位置，更靠右
  textY = displayHeight / 2;
  
  // 根据屏幕尺寸调整时钟半径
  clockRadius = min(displayWidth, displayHeight) * layoutRatio;
  
  // Initialize hand coordinates
  osx = clockCenterX;
  osy = clockCenterY;
  omx = clockCenterX;
  omy = clockCenterY;
  ohx = clockCenterX;
  ohy = clockCenterY;
}

void tftRst(void) {
  pinMode(TFT_BL, OUTPUT);
  digitalWrite(TFT_BL, LOW);
  delay(50);
  digitalWrite(TFT_BL, HIGH);
  delay(50);
}

void setup(void) {
  tftRst();
  tft.init();                             // Initialize the TFT display
  tft.setRotation(TFT_DIRECTION);         // Set the rotation of the display
  tft.fillScreen(TFT_GREY);               // Fill the screen with grey color
  tft.setTextColor(TFT_GREEN, TFT_GREY);  // Set text color and background color
  
  initializeDisplayParameters(); // Initialize coordinates

  // Draw the clock face with dynamic sizing
  tft.fillCircle(clockCenterX, clockCenterY, clockRadius, TFT_BLUE);
  tft.fillCircle(clockCenterX, clockCenterY, clockRadius - 4, TFT_BLACK);

  // Draw 12 lines for the clock marks
  for (int i = 0; i < 360; i += 30) {
    float angle = (i - 90) * 0.0174532925;
    sx = cos(angle);
    sy = sin(angle);
    x0 = sx * (clockRadius - 4) + clockCenterX;
    yy0 = sy * (clockRadius - 4) + clockCenterY;
    x1 = sx * (clockRadius - 11) + clockCenterX;
    yy1 = sy * (clockRadius - 11) + clockCenterY;

    tft.drawLine(x0, yy0, x1, yy1, TFT_BLUE);
  }

  // Draw 60 dots for the clock marks
  for (int i = 0; i < 360; i += 6) {
    float angle = (i - 90) * 0.0174532925;
    sx = cos(angle);
    sy = sin(angle);
    x0 = sx * (clockRadius - 8) + clockCenterX;
    yy0 = sy * (clockRadius - 8) + clockCenterY;

    tft.drawPixel(x0, yy0, TFT_BLUE);
    // Draw larger dots at 12, 3, 6, 9 o'clock positions
    if (i == 0 || i == 180)
      tft.fillCircle(x0, yy0, 1, TFT_CYAN);
    if (i == 0 || i == 180)
      tft.fillCircle(x0 + 1, yy0, 1, TFT_CYAN);
    if (i == 90 || i == 270)
      tft.fillCircle(x0, yy0, 1, TFT_CYAN);
    if (i == 90 || i == 270)
      tft.fillCircle(x0 + 1, yy0, 1, TFT_CYAN);
  }

  tft.fillCircle(clockCenterX, clockCenterY, 3, TFT_RED);

  // Draw text on the right side of the screen
  tft.setTextColor(TFT_GREEN);  // Set text color
  tft.drawCentreString("Freenove", textX, textY, 4);

  targetTime = millis() + 1000;  // Set the target time for the next second
}
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

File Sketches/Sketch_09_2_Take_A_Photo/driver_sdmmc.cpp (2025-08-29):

#include "driver_sdmmc.h"

void sdmmc_init(uint8_t clkPin, uint8_t cmdPin, uint8_t d0Pin) {
  SD_MMC.setPins(clkPin, cmdPin, d0Pin);
  if (!SD_MMC.begin("/sdcard", true, true, SDMMC_FREQ_DEFAULT, 5)) {
    Serial.println("Card Mount Failed");
    return;
  }
  uint8_t cardType = SD_MMC.cardType();
  if (cardType == CARD_NONE) {
    Serial.println("No SD_MMC card attached");
    return;
  }
  Serial.print("SD_MMC Card Type: ");
  if (cardType == CARD_MMC) {
    Serial.println("MMC");
  } else if (cardType == CARD_SD) {
    Serial.println("SDSC");
  } else if (cardType == CARD_SDHC) {
    Serial.println("SDHC");
  } else {
    Serial.println("UNKNOWN");
  }
  uint64_t cardSize = SD_MMC.cardSize() / (1024 * 1024);
  Serial.printf("SD_MMC Card Size: %lluMB\n", cardSize);
  Serial.printf("Total space: %lluMB\r\n", SD_MMC.totalBytes() / (1024 * 1024));
  Serial.printf("Used space: %lluMB\r\n", SD_MMC.usedBytes() / (1024 * 1024));
}

std::list<File_Entry> list_dir(const char *dirname, uint8_t levels) {
  std::list<File_Entry> fileList;

  File root = SD_MMC.open(dirname);
  if (!root) {
    return fileList;
  }
  if (!root.isDirectory()) {
    return fileList;
  }

  File file = root.openNextFile();
  while (file) {
    File_Entry entry;
    entry.name = file.name();
    entry.isDirectory = file.isDirectory();
    if (!entry.isDirectory) {
      entry.size = file.size();
    }
    fileList.push_back(entry);
    if (entry.isDirectory && levels) {
      std::list<File_Entry> subDirList = list_dir(file.path(), levels - 1);
      fileList.insert(fileList.end(), subDirList.begin(), subDirList.end());
    }
    file = root.openNextFile();
  }
  return fileList;
}

void create_dir(const char *path) {
  if (SD_MMC.exists(path)) {
    return;
  } else {
    if (!SD_MMC.mkdir(path)) {
      Serial.println("mkdir failed");
    }
  }
}

void remove_dir(const char *path) {
  if (SD_MMC.exists(path)) {
    std::list<File_Entry> fileList = list_dir(path, 1);

    for (const auto &entry : fileList) {
      if (entry.isDirectory) {
        char subPath[256];
        snprintf(subPath, sizeof(subPath), "%s/%s", path, entry.name.c_str());
        remove_dir(subPath);
      } else {
        char filePath[256];
        snprintf(filePath, sizeof(filePath), "%s/%s", path, entry.name.c_str());
        delete_file(filePath);
      }
    }

    if (!SD_MMC.rmdir(path)) {
      Serial.println("rmdir failed");
    }
  }
}

size_t read_file_size(const char *path) {
  File file = SD_MMC.open(path);
  if (!file) {
    Serial.println("Failed to open file for reading");
    return 0;
  }
  size_t fileSize = file.size();
  file.close();
  return fileSize;
}

void read_file(const char *path, uint8_t *buffer, size_t length) {
  File file = SD_MMC.open(path);
  if (!file) {
    Serial.println("Failed to open file for reading");
    return;
  }

  size_t fileSize = file.size();
  if (length == 0 || length > fileSize) {
    length = fileSize;
  }

  size_t totalBytesRead = 0;
  const size_t chunkSize = 512;
  
  while (totalBytesRead < length) {
    size_t bytesToRead = length - totalBytesRead;
    if (bytesToRead > chunkSize) {
      bytesToRead = chunkSize;
    }
    
    size_t bytesRead = file.read(buffer + totalBytesRead, bytesToRead);
    totalBytesRead += bytesRead;
    
    if (bytesRead != bytesToRead) {
      Serial.printf("Failed to read %u bytes, only read %u bytes\n", bytesToRead, bytesRead);
      break; 
    }
  }
  
  if (totalBytesRead > 0) {
    buffer[totalBytesRead] = '\0';
  }
  Serial.printf("Successfully read %u bytes in total\n", totalBytesRead);
  file.close();
}

void write_file(const char *path, const uint8_t *buffer, size_t size) {
  File file = SD_MMC.open(path, FILE_WRITE);
  if (!file) {
    Serial.println("Failed to open file for writing");
    return;
  }

  size_t bytesWritten = file.write(buffer, size);
  if (bytesWritten != size) {
    Serial.printf("Failed to write %u bytes, only wrote %u bytes\n", size, bytesWritten);
  }

  file.close();
}

void append_file(const char *path, const uint8_t *buffer, size_t size) {
  File file = SD_MMC.open(path, FILE_APPEND);
  if (!file) {
    Serial.println("Failed to open file for appending");
    return;
  }

  size_t bytesWritten = file.write(buffer, size);
  if (bytesWritten != size) {
    Serial.printf("Failed to append %u bytes, only appended %u bytes\n", size, bytesWritten);
  }

  file.close();
}

void rename_file(const char *path1, const char *path2) {
  if (SD_MMC.exists(path2)) {
    if (!SD_MMC.remove(path2)) {
      Serial.println("Failed to delete target file");
      return;
    }
  }

  if (!SD_MMC.rename(path1, path2)) {
    Serial.println("Rename failed");
  }
}

void delete_file(const char *path) {
  if (!SD_MMC.remove(path)) {
    Serial.println("Delete failed");
  }
}

void test_file_io(const char *path) {
  File file = SD_MMC.open(path);
  static uint8_t buf[512];
  size_t len = 0;

  if (file) {
    len = file.size();
    while (len) {
      size_t toRead = len;
      if (toRead > 512) {
        toRead = 512;
      }
      file.read(buf, toRead);
      len -= toRead;
    }
    file.close();
  } else {
    Serial.println("Failed to open file for reading");
    return;
  }

  file = SD_MMC.open(path, FILE_WRITE);
  if (!file) {
    Serial.println("Failed to open file for writing");
    return;
  }

  for (size_t i = 0; i < 2048; i++) {
    file.write(buf, 512);
  }

  file.close();
}

void create_folder(char *path) {
  File root = SD_MMC.open(path);
  if (!root) {
    if (!SD_MMC.mkdir(path)) {
      Serial.println("mkdir failed");
    }
  }
  root.close();
}

int read_file_num(const char *dirname) {
  std::list<File_Entry> fileList = list_dir(dirname, 0);
  if (fileList.empty()) {
    return 0;
  }

  int num = 0;
  for (const auto &entry : fileList) {
    if (!entry.isDirectory) {
      num++;
    }
  }

  return num;
}

void print_file_list(const std::list<File_Entry> &fileList) {
  for (const auto &entry : fileList) {
    if (entry.isDirectory) {
      Serial.print("DIR: ");
    } else {
      Serial.print("FILE: ");
    }
    Serial.print(entry.name);
    if (!entry.isDirectory) {
      Serial.printf("  SIZE: %u\n", entry.size);
    } else {
      Serial.println();
    }
  }
}

String get_file_name_by_index(const char *dirname, int index) {
  std::list<File_Entry> fileList = list_dir(dirname, 0);
  if (fileList.empty()) {
    return "";
  }

  int count = 0;
  for (const auto &entry : fileList) {
    if (!entry.isDirectory) {
      if (count == index) {
        return entry.name;
      }
      count++;
    }
  }

  return "";
}

void write_jpg(const char *path, const uint8_t *buf, size_t size) {
  write_file(path, buf, size);
}
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

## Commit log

2025-04-29 Upload 3D Models.
    [Battery_752035.SLDPRT, Camera.SLDPRT, Camera_OV3660.SLDPRT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]
2025-04-29 Upload Sketches.
    [partitions.csv]
2025-09-06 Update codes.
    1. Updated the range settings of the driver_button.
    2. Updated the volume settings of the music.
2025-12-30 Update 3D models.
    [Battery_103450.SLDPRT, Battery_752035.SLDPRT, CB10201.SLDPRT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]

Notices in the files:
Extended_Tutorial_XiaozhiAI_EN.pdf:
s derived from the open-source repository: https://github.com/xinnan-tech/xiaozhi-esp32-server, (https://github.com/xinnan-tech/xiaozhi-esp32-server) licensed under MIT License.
